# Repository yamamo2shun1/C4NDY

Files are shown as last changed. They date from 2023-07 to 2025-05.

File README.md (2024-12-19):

# C4NDY KeyVLM / STK

## Documentation
- [See the official documentation on https://yamamo2shun1.github.io/C4NDY/](https://yamamo2shun1.github.io/C4NDY/)

The docs are powered by [VitePress](https://vitepress.dev/). 

## Submodule
[TinyUSB](https://github.com/hathach/tinyusb) is included as a submodule in [STM32CubeIDE/C4NDY_KeyVLM](https://github.com/yamamo2shun1/C4NDY/tree/main/STM32CubeIDE/C4NDY_KeyVLM) and [STM32CubeIDE/C4NDY_STK](https://github.com/yamamo2shun1/C4NDY/tree/main/STM32CubeIDE/C4NDY_STK). Since the version of TinyUSB that we have confirmed to work is [0.17.0](https://github.com/hathach/tinyusb/releases/tag/0.17.0), please check out to the [commit](https://github.com/hathach/tinyusb/commit/5217cee5de4cd555018da90f9f1bcc87fb1c1d3a) with this tag.

## Maintainer
C4NDY is developed and maintained by Shunichi Yamamoto of Yamamoto Works Ltd.

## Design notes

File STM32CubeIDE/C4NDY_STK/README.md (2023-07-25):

# C4NDY Composite HID & UAC

サブモジュール化したTinyUSBそのままではPC接続時にUSBデバイスとして正しく認識しないので、以下の変更を行う。

## dcd_stm32_fsdev.c (src/portable/st/stm32_fsdev)
dcd_init_enable関数内にある割り込みを有効化する処理を2箇所、コメントアウトする。

```
#elif CFG_TUSB_MCU == OPT_MCU_STM32G4
  //NVIC_EnableIRQ(USB_HP_IRQn); <-- コメントアウト
  NVIC_EnableIRQ(USB_LP_IRQn);
  //NVIC_EnableIRQ(USBWakeUp_IRQn); <-- コメントアウト
```

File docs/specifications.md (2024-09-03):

# Specifications

## Common

- Mainboard:
  - MCU: [STM32G491](https://www.st.com/en/microcontrollers-microprocessors/stm32g4x1.html)
  - USB Stack: [TinyUSB](https://docs.tinyusb.org/en/latest/)
  - Debug Interface: SWD
  - [Schematics](/pdf/main-sch.pdf)
  - [PCB](/pdf/main-brd.pdf)
- Codec: [Analog Devices ADAU1761](https://www.analog.com/jp/products/adau1761.html)
  - USB Audio Spec: 24bit 48kHz Input only
  - Analog Audio In/Out: Line/Phono In and HP Out, [Thonkiconn 3.5mm jack socket](https://www.thonk.co.uk/shop/thonkiconn/))
- Keyswitch: Gateron Low Profile 2.0(Implemented Hotswap socket KS-27)  

## KeyVLM 

- 65x Keys, 2x Pots(mix and main output gain), 9x GPIO Ports
- [Schematics](/pdf/KeyVLM-sch.pdf)
- [PCB](/pdf/KeyVLM-brd.pdf)

## STK

- 37x Keys, 34x RGB LEDs, 2x Analog JoySticks, 1x Pot(mix), 6x GPIO Ports
- [Schematics](/pdf/STK-sch.pdf)
- [PCB](/pdf/STK-brd.pdf)

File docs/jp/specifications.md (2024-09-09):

# 主な仕様

## 共通

- メインボード:
  - MCU: [STM32G491](https://www.st.com/en/microcontrollers-microprocessors/stm32g4x1.html)
  - USBスタック: [TinyUSB](https://docs.tinyusb.org/en/latest/)
  - デバッグ・インターフェース: SWD
  - [Schematics](/pdf/main-sch.pdf)
  - [PCB](/pdf/main-brd.pdf)
- オーディオ・コーデック: [Analog Devices ADAU1761](https://www.analog.com/jp/products/adau1761.html)
  - USBオーディオ: 24bit 48kHz （入力のみ、フォノ/ラインの音声をホスト側に送ることは出来ません）
  - アナログ・オーディオ入出力: フォノ/ライン入力、 HP出力, [Thonkiconn 3.5mm jack socket](https://www.thonk.co.uk/shop/thonkiconn/))
- キースイッチ: Gateron Low Profile 2.0(Implemented Hotswap socket KS-27)  

## KeyVLM 

- 65個のキー、2個のボリューム(ミックスと出力ゲイン調整用), 9個のGPIOポート
- [Schematics](/pdf/KeyVLM-sch.pdf)
- [PCB](/pdf/KeyVLM-brd.pdf)

## STK

- 37個のキー、34個のフルカラーLED、2本のジョイスティック、1個のボリューム(ミックス調整用), 6個のGPIOポート
- [Schematics](/pdf/STK-sch.pdf)
- [PCB](/pdf/STK-brd.pdf)

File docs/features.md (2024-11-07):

# What is C4NDY KeyVLM/STK?

The C4NDY KeyVLM/STK is a USB keyboard with a Ortholinear layout. It's greatest feature is that it can be connected to a turntable, allowing you to mix the music you are playing on your computer or smartphone(USB host device) with the music on your vinyl records.

Furthermore, C4NDY KeyVLM/STK is open source hardware under the [MIT license](https://github.com/yamamo2shun1/C4NDY/blob/main/LICENSE.md). The [source codes](https://github.com/yamamo2shun1/C4NDY/tree/main/STM32CubeIDE) of the firmware as well as the [circuit board schematics](https://github.com/yamamo2shun1/C4NDY/tree/main/KiCad) and [3D model data](https://github.com/yamamo2shun1/C4NDY/tree/main/3Dmodel) of the enclosure are available to the public.

## KeyVLM

KeyVLM is designed to be stress-free for first-time users of Ortholinear Layout by setting the number of keys to 65.

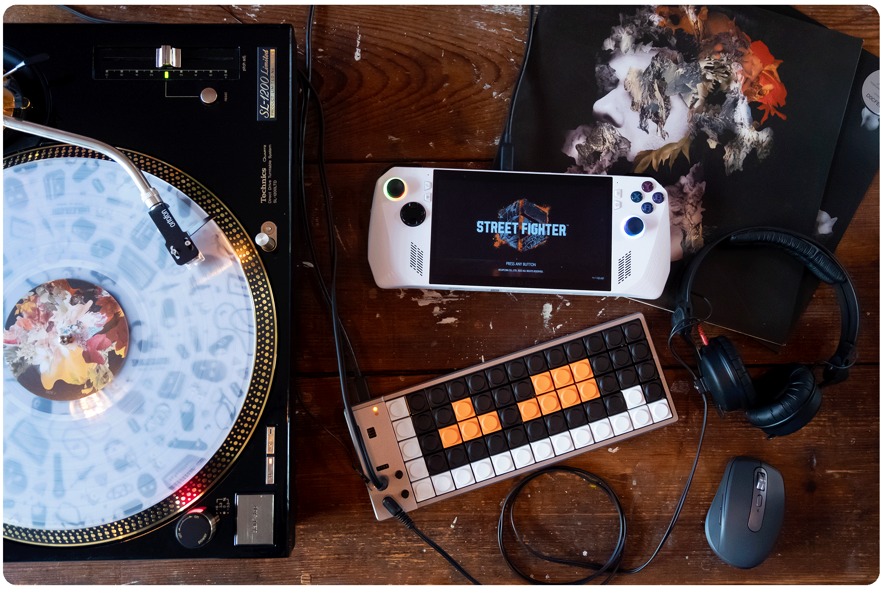
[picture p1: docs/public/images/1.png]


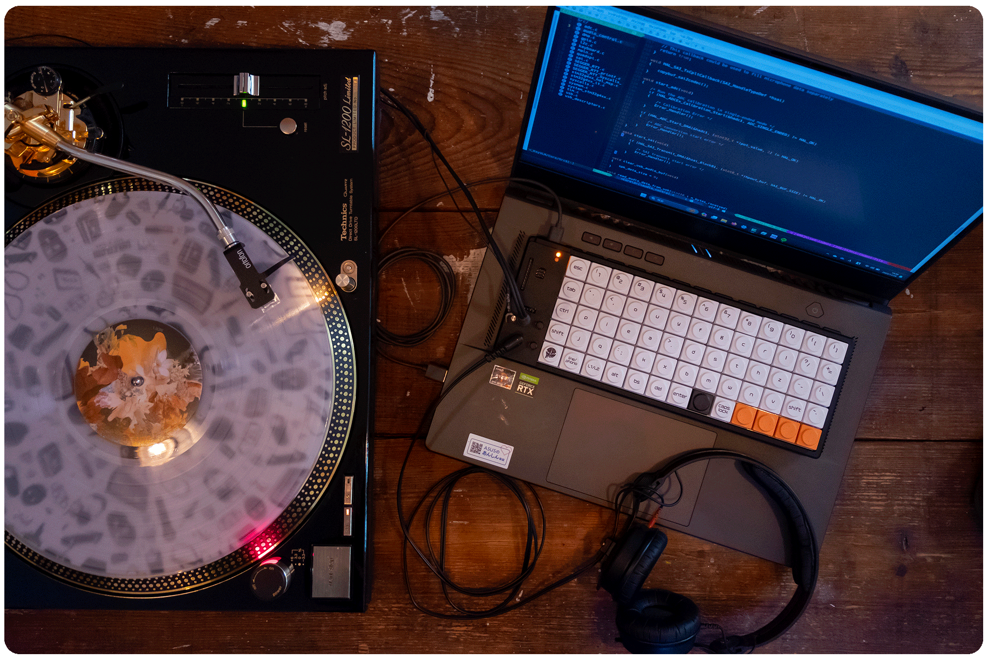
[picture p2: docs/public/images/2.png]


## STK

STK is a minimalist keyboard with 37 keys, but with 2 joysticks designed to reduce pinky finger fatigue and maximize thumb's performance.

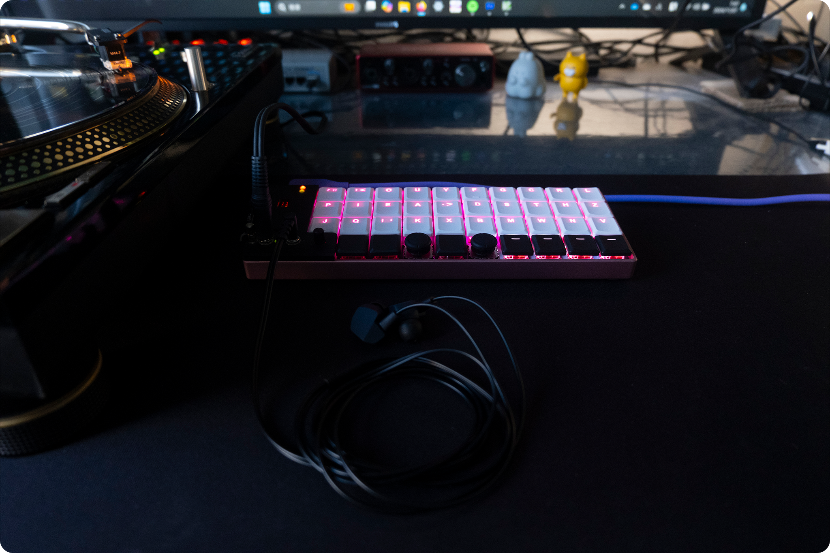
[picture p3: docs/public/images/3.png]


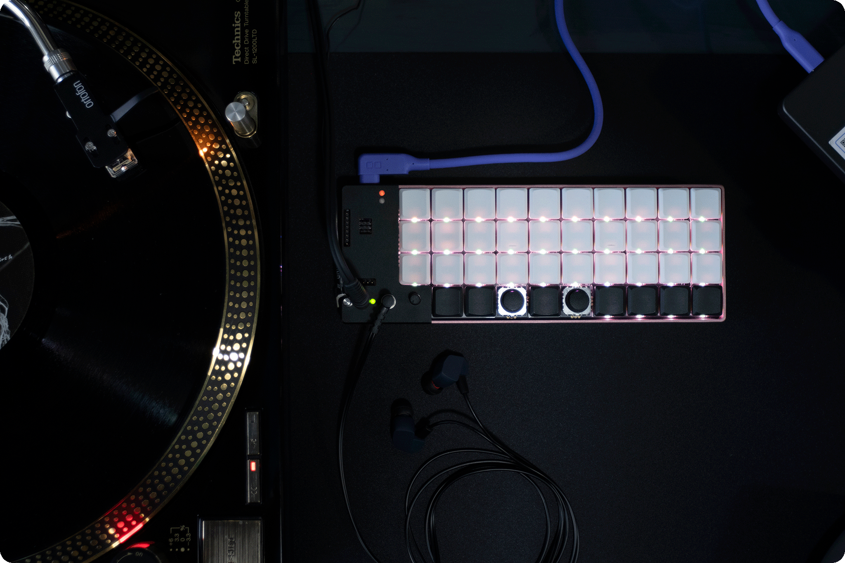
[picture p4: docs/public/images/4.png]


<iframe class="youtube" src="https://www.youtube.com/embed/TXuELYQbFvI?si=C4ZM-QYwuqbofEQ4" title="YouTube video player" frameborder="0" allow="accelerometer; autoplay; clipboard-write; encrypted-media; gyroscope; picture-in-picture; web-share" referrerpolicy="strict-origin-when-cross-origin" allowfullscreen></iframe>
<br>
<iframe class="youtube" src="https://www.youtube.com/embed/GJj3aiSIqJE?si=5twpRAXy-AmaJDOT" title="YouTube video player" frameborder="0" allow="accelerometer; autoplay; clipboard-write; encrypted-media; gyroscope; picture-in-picture; web-share" referrerpolicy="strict-origin-when-cross-origin" allowfullscreen></iframe>
<br>
<iframe class="youtube" src="https://www.youtube.com/embed/NtcGqJvtMxw?si=YaaeqbSABE9DcXNv" title="YouTube video player" frameborder="0" allow="accelerometer; autoplay; clipboard-write; encrypted-media; gyroscope; picture-in-picture; web-share" referrerpolicy="strict-origin-when-cross-origin" allowfullscreen></iframe>
<br>
<iframe class="youtube" src="https://www.youtube.com/embed/8FVFd6uG3Ts?si=2ghEefk_HB_o5fTh" title="YouTube video player" frameborder="0" allow="accelerometer; autoplay; clipboard-write; encrypted-media; gyroscope; picture-in-picture; web-share" referrerpolicy="strict-origin-when-cross-origin" allowfullscreen></iframe>

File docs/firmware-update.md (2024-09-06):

# Firmware Update
## Introduction
The C4NDY KeyVLM/STK does not require a firmware rewrite to change the keymap.
Normal users will only update the firmware when bug fixes or new features are added.
C4NDY KeyVLM/STK has a built-in boot loader for this purpose.

## How to switch to boot loader mode
Press and hold down the LGUI and ESC keys or RESET key until the green LED on the Side-Panel blinks three times to enter the boot loader mode.

<video controls="controls" src="https://github.com/yamamo2shun1/C4NDY/assets/96638/79a93170-637f-4472-83ec-ebd615135d6c" />

## Installing the driver
If you are using Windows, you will need to install the driver on [Zadig](https://zadig.akeo.ie/) after entering the boot loader mode (first time only).

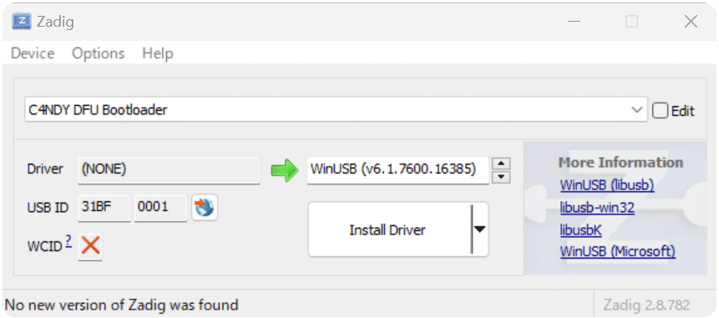
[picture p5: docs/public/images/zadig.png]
zadig


## Installing the programmer
To update the firmware, it is recommended to install and use [STM32CubeProg](https://www.st.com/ja/development-tools/stm32cubeprog.html).
The procedure to update the firmware using STM32CubeProg is as follows

0. Download the latest ELF file from [here](https://github.com/yamamo2shun1/C4NDY/releases).
1. launch STM32CubeProg.
2. Rewrite "PID" to "0x0001".
3. Rewrite "VID" to "0x31BF".
4. Click the "Port" update button.
5. Confirm that "Port" is changed from "No DFU detected" to "USB1" and click the "Connect" button.
6. Click the "Erasing & Programming" button, the second green button from the top on the left side of the window.
7. Check the "Verify programming" and "Run after programming" check boxes.
8. Confirm that "Full chip erase" is not checked.
9. Set the path of downloaded .elf file in "File path".
10. Click "Start Programming" to start programming.

<video controls="controls" src="https://github.com/yamamo2shun1/C4NDY/assets/96638/fc8503f9-ba2c-4c98-849b-17fdc625cbd1" />

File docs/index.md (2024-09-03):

---
# https://vitepress.dev/reference/default-theme-home-page
layout: home

hero:
  name: "C4NDY KeyVLM / STK"
  text: "Ortholinear Keyboard connectable a Turntable."
  tagline: The UAC and HID composite device project based on STM32G491.
  image:
    dark: /images/c4ndy-dark.png
    light: /images/c4ndy-light.png
    alt: logo
  actions:
    - theme: brand
      text: Get Started
      link: /features
    - theme: alt
      text: View on GitHub
      link: https://github.com/yamamo2shun1/C4NDY 

features:
  - icon:
      src: /images/keyvlm.png
      width: 560px
    title: C4NDY KeyVLM
    details: 65-Key Ortholinear Layout and Audio I/O(Phono/Line in & HP out).
    link: https://booth.pm/ja/items/5785829
    linkText: buy (Japanese)
    rel: external
  - icon:
      src: /images/stk.png
      width: 560px
    title: C4NDY STK
    details: 37-Key Ortholinear Layout, 34-RGB LEDs, 2-JoySticks and Audio I/O(Phono/Line in & HP out).
#  - title: Feature C
#    details: Lorem ipsum dolor sit amet, consectetur adipiscing elit
---

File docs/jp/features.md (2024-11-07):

# C4NDY KeyVLM/STK とは？

C4NDY KeyVLM/STKは格子配列のUSBキーボードです。最大の特徴はターンテーブルが接続することが可能で、PCやスマホなど（USBホストデバイス）の音楽とヴァイナルの音楽をミックスして楽しく事ができます。

さらに、C4NDY KeyVLM/STK は[MITライセンス](https://github.com/yamamo2shun1/C4NDY/blob/main/LICENSE.md)に基づくオープンソース・ハードウェアです。ファームウェアの[ソースコード](https://github.com/yamamo2shun1/C4NDY/tree/main/STM32CubeIDE)、[基板の回路図、ボードデータ](https://github.com/yamamo2shun1/C4NDY/tree/main/KiCad) 、そして筐体の[3Dデータ](https://github.com/yamamo2shun1/C4NDY/tree/main/3Dmodel)も再利用可能です。

## KeyVLM

KeyVLMは初めての格子配列キーボードでもストレスなく使えるようキーの数を65キーで設計されています。





## STK

STKは37キーのミニマルなキーボードです。小指の負荷を軽減し、親指の運動性能を最大限活用するため2本のジョイスティックが実装されています。





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

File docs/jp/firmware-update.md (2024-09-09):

# ファームウェアの更新
## はじめに
C4NDY KeyVLM/STKはキーマップの変更でファームウェアを書き換える必要がありません。通常のユーザーはバグ修正や新機能が追加されるときに必要に応じてファームエアを更新します。

## ブートローダーモードへの移行
C4NDY KeyVLM/STKはファームウェア書き換え用のライターを使わずにファームウェアの更新を置くなうためにブートローダーが内蔵さえています。
ブートローダーモードに移行するには、サイドパネルの緑LEDが3回点滅するまでLGUIとESCキーの2つ（もしくはRESETキー単独）を長押しします。

<video controls="controls" src="https://github.com/yamamo2shun1/C4NDY/assets/96638/79a93170-637f-4472-83ec-ebd615135d6c" />

## ドライバのインストール
Windowsユーザーの場合、ブートローダーモードに初めて切り替えた時のみ、[Zadig](https://zadig.akeo.ie/)でドライバーをインストールする必要があります。

zadig

## プログラマのインストール
ファームウェアの更新をするためには、STMicroelectronics社がリリースしている[STM32CubeProg](https://www.st.com/ja/development-tools/stm32cubeprog.html)をインストールしてお使いいただくことを推奨しています。
STM32CubeProgを使ってファームウェアを更新する手順は下記の通りです。

0. 最新のELFファイルを[ここ](https://github.com/yamamo2shun1/C4NDY/releases)からダウンロードします
1. STM32CubeProgを起動します
2. 「PID」に「0x0001」と入力します
3. 「VID」に「0x31BF」と入力します
4. 「Port」の更新ボタンをクリックします
5. 「Port」が「No DFU detected」から「USB1」になったことを確認し、「Connect」ボタンをクリックします
6. ウィンドウ左端に並んでいる緑色アイコンの上から2つ目にある「Erasing & Programming」ボタンをクリックします
7. 「Verify programming」と「Run after programming」のチェックボックスにチェックを入れます
8. 「Full chip erase」にチェックが入っていないことを確認します
9．「File path」にダウンロードした.elfファイルをセットします
10. 「Start Programming」をクリックし、9でセットした.elfを書き込みます

<video controls="controls" src="https://github.com/yamamo2shun1/C4NDY/assets/96638/fc8503f9-ba2c-4c98-849b-17fdc625cbd1" />

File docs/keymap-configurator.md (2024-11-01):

# How to remap

[Confiseur](https://github.com/yamamo2shun1/Confiseur) is a command line tool for key remapping dedicated to C4NDY KeyVLM/STK.

## Preparing
By preparing a keymap file written in TOML and reading it, it is possible to remap without rewriting the firmware.

- [Example for KeyVLM](https://github.com/yamamo2shun1/Confiseur/blob/main/example-layout/layouts_KeyVLM.toml)
```toml
[layout1]
	normal = [
		[["Esc", "00000000"],  ["1", "00000000"],    ["2", "00000000"],      ["3", "00000000"],    ["4", "00000000"],  ["5", "00000000"],   ["6", "00000000"],     ["7", "00000000"],     ["8", "00000000"],        ["9", "00000000"],      ["0", "00000000"],     ["Minus", "00000000"],      ["Equal", "00000000"]],
		[["Tab", "00000000"],  ["Q", "00000000"],    ["W", "00000000"],      ["E", "00000000"],    ["R", "00000000"],  ["T", "00000000"],   ["Y", "00000000"],     ["U", "00000000"],     ["V", "00000000"],        ["O", "00000000"],      ["P", "00000000"],     ["O_SBracket", "00000000"], ["C_SBracket", "00000000"]],
		[["Null", "00000001"], ["A", "00000000"],    ["S", "00000000"],      ["D", "00000000"],    ["F", "00000000"],  ["G", "00000000"],   ["H", "00000000"],     ["J", "00000000"],     ["K", "00000000"],        ["L", "00000000"],      ["Colon", "00000000"], ["Apostrophe", "00000000"], ["Yen", "00000000"]],
		[["Null", "00000010"], ["Z", "00000000"],    ["X", "00000000"],      ["C", "00000000"],    ["I", "00000000"],  ["B", "00000000"],   ["N", "00000000"],     ["M", "00000000"],     ["Comma", "00000000"],    ["Period", "00000000"], ["Slash", "00000000"], ["Null", "00100000"],       ["Backquote", "00000000"]],
		[["Null", "00001000"], ["LNPH", "00000000"], ["LAYOUT", "00000000"], ["Null", "00000100"], ["BS", "00000000"], ["Del", "00000000"], ["Enter", "00000000"], ["Space", "00000000"], ["CapsLock", "00000000"], ["Left", "00000000"],   ["Down", "00000000"],  ["Up", "00000000"],         ["Right", "00000000"]]

	]

[layout2]
	normal = [
		[["Esc", "00000000"],  ["1", "00000000"],          ["2", "00000000"],      ["3", "00000000"],     ["4", "00000000"],  ["5", "00000000"],      ["6", "00000000"],     ["7", "00000000"],     ["8", "00000000"],        ["9", "00000000"],    ["0", "00000000"],    ["O_SBracket", "00000000"], ["C_SBracket", "00000000"]],
		[["Tab", "00000000"],  ["Apostrophe", "00000000"], ["Comma", "00000000"],  ["O", "00000000"],     ["U", "00000000"],  ["Y", "00000000"],      ["F", "00000000"],     ["G", "00000000"],     ["C", "00000000"],        ["R", "00000000"],    ["L", "00000000"],    ["Slash", "00000000"],      ["Equal", "00000000"]],
		[["Null", "00000001"], ["P", "00000000"],          ["I", "00000000"],      ["E", "00000000"],     ["A", "00000000"],  ["Period", "00000000"], ["D", "00000000"],     ["S", "00000000"],     ["T", "00000000"],        ["H", "00000000"],    ["Z", "00000000"],    ["Minus", "00000000"],      ["Backslash", "00000000"]],
		[["Null", "00000010"], ["J", "00000000"],          ["Q", "00000000"],      ["Colon", "00000000"], ["K", "00000000"],  ["X", "00000000"],      ["B", "00000000"],     ["M", "00000000"],     ["W", "00000000"],        ["N", "00000000"],    ["V", "00000000"],    ["Null", "00100000"],       ["Backquote", "00000000"]],
		[["Null", "00001000"], ["LNPH", "00000000"],       ["LAYOUT", "00000000"], ["Null", "00000100"],  ["BS", "00000000"], ["Del", "00000000"],    ["Enter", "00000000"], ["Space", "00000000"], ["CapsLock", "00000000"], ["Left", "00000000"], ["Down", "00000000"], ["Up", "00000000"],         ["Right", "00000000"]]
	]
```

- [Example for STK](https://github.com/yamamo2shun1/Confiseur/blob/main/example-layout/layouts_STK.toml)
```toml
[layout1]
	normal = [
		[["Q", "00000000"],    ["W", "00000000"],    ["E", "00000000"],    ["R", "00000000"],    ["T", "00000000"],    ["Y", "00000000"],    ["U", "00000000"],    ["I", "00000000"],     ["O", "00000000"],      ["P", "00000000"]],
		[["A", "00000000"],    ["S", "00000000"],    ["D", "00000000"],    ["F", "00000000"],    ["G", "00000000"],    ["H", "00000000"],    ["J", "00000000"],    ["K", "00000000"],     ["L", "00000000"],      ["Colon", "00000000"]],
		[["Z", "00000000"],    ["X", "00000000"],    ["C", "00000000"],    ["V", "00000000"],    ["B", "00000000"],    ["N", "00000000"],    ["M", "00000000"],    ["Comma", "00000000"], ["Period", "00000000"], ["Slash", "00000000"]],
		[["Null", "00000000"], ["Null", "00001000"], ["Null", "00000100"], ["Null", "00000000"], ["Null", "00000001"], ["Null", "00000000"], ["Left", "00000000"], ["Down", "00000000"],  ["Up", "00000000"],     ["Right", "00000000"]]
	]
	upper = [
		[["1", "00000000"],          ["2", "00000000"],         ["3", "00000000"],      ["4", "00000000"],      ["5", "00000000"],       ["6", "00000000"],    ["7", "00000000"],          ["8", "00000000"],          ["9", "00000000"],        ["0", "00000000"]],
		[["Apostrophe", "00000000"], ["Backquote", "00000000"], ["Null", "00000000"],   ["Null", "00001000"],   ["Null", "00000000"],    ["Null", "00000000"], ["O_SBracket", "00000000"], ["C_SBracket", "00000000"], ["Minus", "00000000"],    ["Equal", "00000000"]],
		[["Null", "00000000"],       ["CapsLock", "00000000"],  ["M_LBTN", "00000000"], ["M_RBTN", "00000000"], ["M_WHEEL", "00000000"], ["Null", "00000000"], ["Null", "00000000"],       ["Comma", "00000000"],      ["Period", "00000000"],   ["Backslash", "00000000"]],
		[["Null", "00000000"],       ["LNPH", "00000000"],      ["LAYOUT", "00000000"], ["Null", "00000000"],   ["Null", "00000001"],    ["Null", "00000000"], ["Null", "00000000"],       ["MGain_Down", "00000000"], ["MGain_Up", "00000000"], ["Reset", "00000000"]]
	]
	stick = [
		[
			["Null", "00000000"], ["Upper", "00000000"], ["Null", "00000000"],
			["BS",   "00000000"], ["Null",  "00000000"], ["Tab",  "00000000"],
			["Null", "00000000"], ["Enter", "00000000"], ["Null", "00000000"]
		],
		[
			["Null", "00000000"], ["Null", "00100000"], ["Null",  "00000000"],
			["Del",  "00000000"], ["Null", "00000000"], ["Space", "00000000"],
			["Null", "00000000"], ["Esc",  "00000000"], ["Null",  "00000000"]
		]
	]
	led = [
		[0x00, 0xAE, 0xEF],
		[0xEF, 0x00, 0xAE],
		[0xAE, 0xEF, 0x00]
	]
    intensity = [
        1.0
    ]

[layout2]
	normal = [
		[["Apostrophe", "00000000"], ["Comma", "00000000"], ["O", "00000000"],     ["U", "00000000"],    ["Y", "00000000"],      ["F", "00000000"],    ["G", "00000000"],    ["C", "00000000"],    ["R", "00000000"],  ["L", "00000000"]],
		[["P", "00000000"],          ["I", "00000000"],     ["E", "00000000"],     ["A", "00000000"],    ["Period", "00000000"], ["D", "00000000"],    ["S", "00000000"],    ["T", "00000000"],    ["H", "00000000"],  ["Z", "00000000"]],
		[["J", "00000000"],          ["Q", "00000000"],     ["Colon", "00000000"], ["K", "00000000"],    ["X", "00000000"],      ["B", "00000000"],    ["M", "00000000"],    ["W", "00000000"],    ["N", "00000000"],  ["V", "00000000"]],
		[["Null", "00000000"],       ["Null", "00001000"],  ["Null", "00000100"],  ["Null", "00000000"], ["Null", "00000001"],   ["Null", "00000000"], ["Left", "00000000"], ["Down", "00000000"], ["Up", "00000000"], ["Right", "00000000"]]
	]
	upper = [
		[["1", "00000000"],          ["2", "00000000"],        ["3", "00000000"],      ["4", "00000000"],      ["5", "00000000"],       ["6", "00000000"],    ["7", "00000000"],          ["8", "00000000"],          ["9", "00000000"],         ["0", "00000000"]],
		[["Apostrophe", "00000000"], ["Comma", "00000000"],    ["Null", "00000000"],   ["Null", "00001000"],   ["Period", "00000000"],  ["Null", "00000000"], ["O_SBracket", "00000000"], ["C_SBracket", "00000000"], ["Slash", "00000000"],     ["Minus", "00000000"]],
		[["Null", "00000000"],       ["CapsLock", "00000000"], ["M_LBTN", "00000000"], ["M_RBTN", "00000000"], ["M_WHEEL", "00000000"], ["Null", "00000000"], ["Equal", "00000000"],      ["Null", "00000000"],       ["Backquote", "00000000"], ["Backslash", "00000000"]],
		[["Null", "00000000"],       ["LNPH", "00000000"],     ["LAYOUT", "00000000"], ["Null", "00000000"],   ["Null", "00000001"],    ["Null", "00000000"], ["Null", "00000000"],       ["MGain_Down", "00000000"], ["MGain_Up", "00000000"],  ["Reset", "00000000"]]
	]
	stick = [
		[
			["Null", "00000000"], ["Upper", "00000000"], ["Null", "00000000"],
			["BS",   "00000000"], ["Null",  "00000000"], ["Tab",  "00000000"],
			["Null", "00000000"], ["Enter", "00000000"], ["Null", "00000000"]
		],
		[
			["Null", "00000000"], ["Null", "00100000"], ["Null",  "00000000"],
			["Del",  "00000000"], ["Null", "00000000"], ["Space", "00000000"],
			["Null", "00000000"], ["Esc",  "00000000"], ["Null",  "00000000"]
		]
	]
	led = [
		[0xFF, 0x00, 0x8C],
		[0x00, 0xFF, 0xFF],
		[0x00, 0x00, 0xFF]
	]
    intensity = [
        1.0
    ]
```

## Installation
The `go install` is available.
```shellscript
$ go install github.com/yamamo2shun1/Confiseur/cmd/confiseur@v0.14.0
```

## Usage

```Less
-version
        Show the version of the tool installed.
        ex) confiseur -version
-check
        Show information on C4NDY KeyVLM/STK connected to PC/Mac.
        ex) confiseur -check
-list
        Show connected device name list.
        ex) confiseur -list
-id [int]
        Select connected device ID(ID can be checked in -check/-list).
        This option is available when using the following command options.
        If ID is not specified, 0 is the default.
-load
        Show the current key names of the keyboard.
        ex) confiseur -load
            confiseur -load -id 1
-remap [string]
        Apply the keyboard settings from specified toml file.
        ex) confiseur -remap examples/layout_STK.toml
            confiseur -remap examples/layout_KeyVLM.toml -id 0
-save
        Save the keymap written by "remap" to the memory area.
        ex) confiseur -save
            confiseur -id 0 -save
-led [int(0x000000-0xFFFFFF)]
        Set LED RGB value for checking color.
        ex) confiseur -led 0xFF0000 # red
            confiseur id 0 -led 0x00FFFF # cyan
-intensity [float(0.0-1.0)]
        Set LED intensity.
        ex) confiseur -intensity 1.0
            confiseur -id 1 -intensity 0.5
-restart
        Restart the keyboard immediately.
        ex) confiseur -restart
            confiseur -restart -id 1
-factoryreset
        Reset all settings to factory defaults.
        ex) confiseur -factoryreset
            confiseur -id 0 -factoryreset
```

## Preparation to build
First, install the [Go language](https://go.dev/) development environment.  
Some preparation is required to build the code because we are using [go-hid](https://github.com/sstallion/go-hid).

### for Windows
Add `CGO_ENABLED=1` to the environment variable and install a C compiler such as [TDM-GCC](https://jmeubank.github.io/tdm-gcc/) beforehand.

### for macOS/Linux
Add `CGO_ENABLED=1` to your shell configuration file, such as .zshrc.

## How to build from Source Code
```shellscript
$ git clone https://github.com/yamamo2shun1/Confiseur
$ cd Confiseur/cmd/confiseur
$ go build -o confiseur
```

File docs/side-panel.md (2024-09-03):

# Side Panel I/O

## KeyVLM
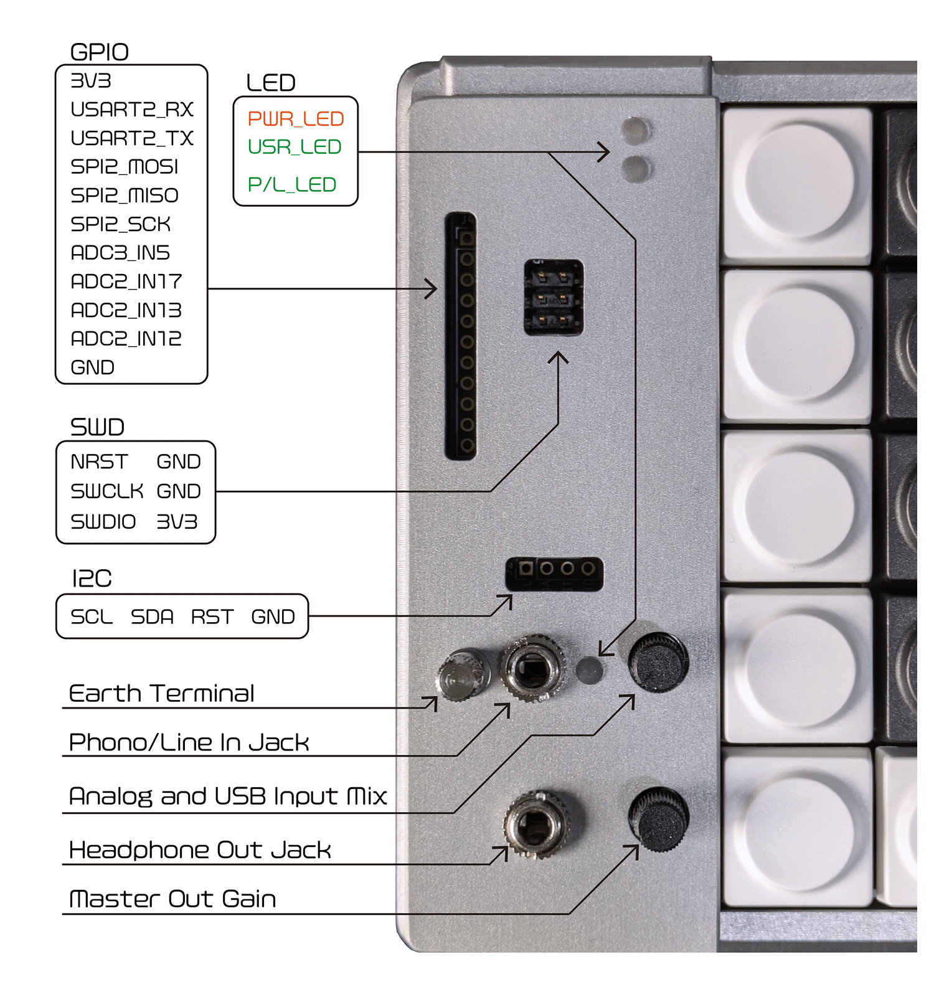
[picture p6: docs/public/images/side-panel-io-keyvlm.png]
side-panel-io-keyvlm


## STK
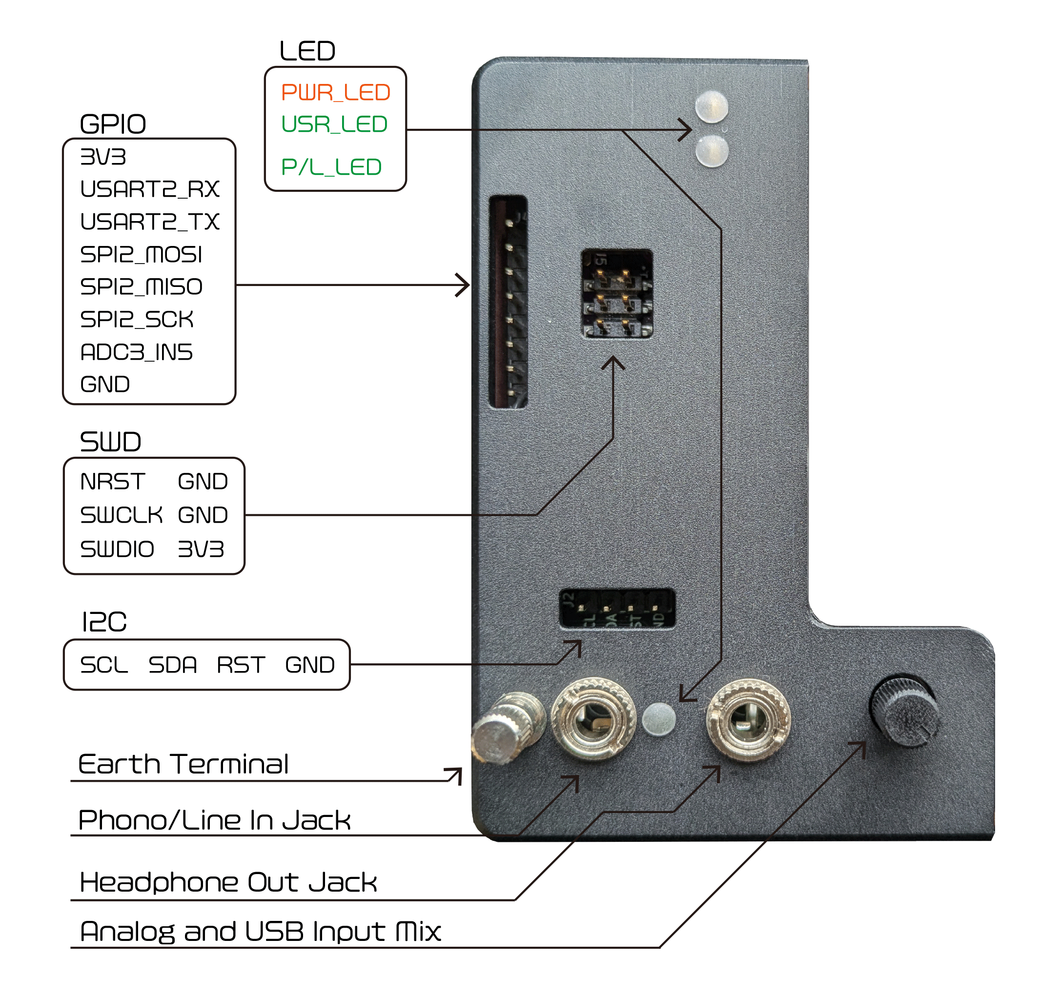
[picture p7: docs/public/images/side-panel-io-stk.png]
side-panel-io-stk


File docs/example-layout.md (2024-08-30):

# Example Layout
## KeyVLM
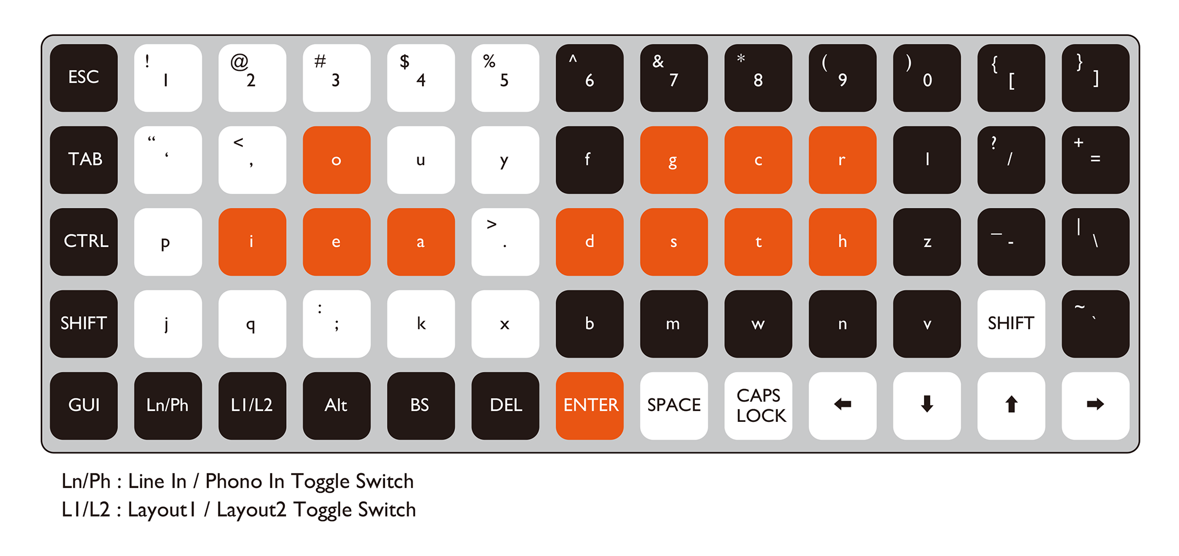
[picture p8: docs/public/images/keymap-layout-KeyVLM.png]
layout-keyvlm


## STK
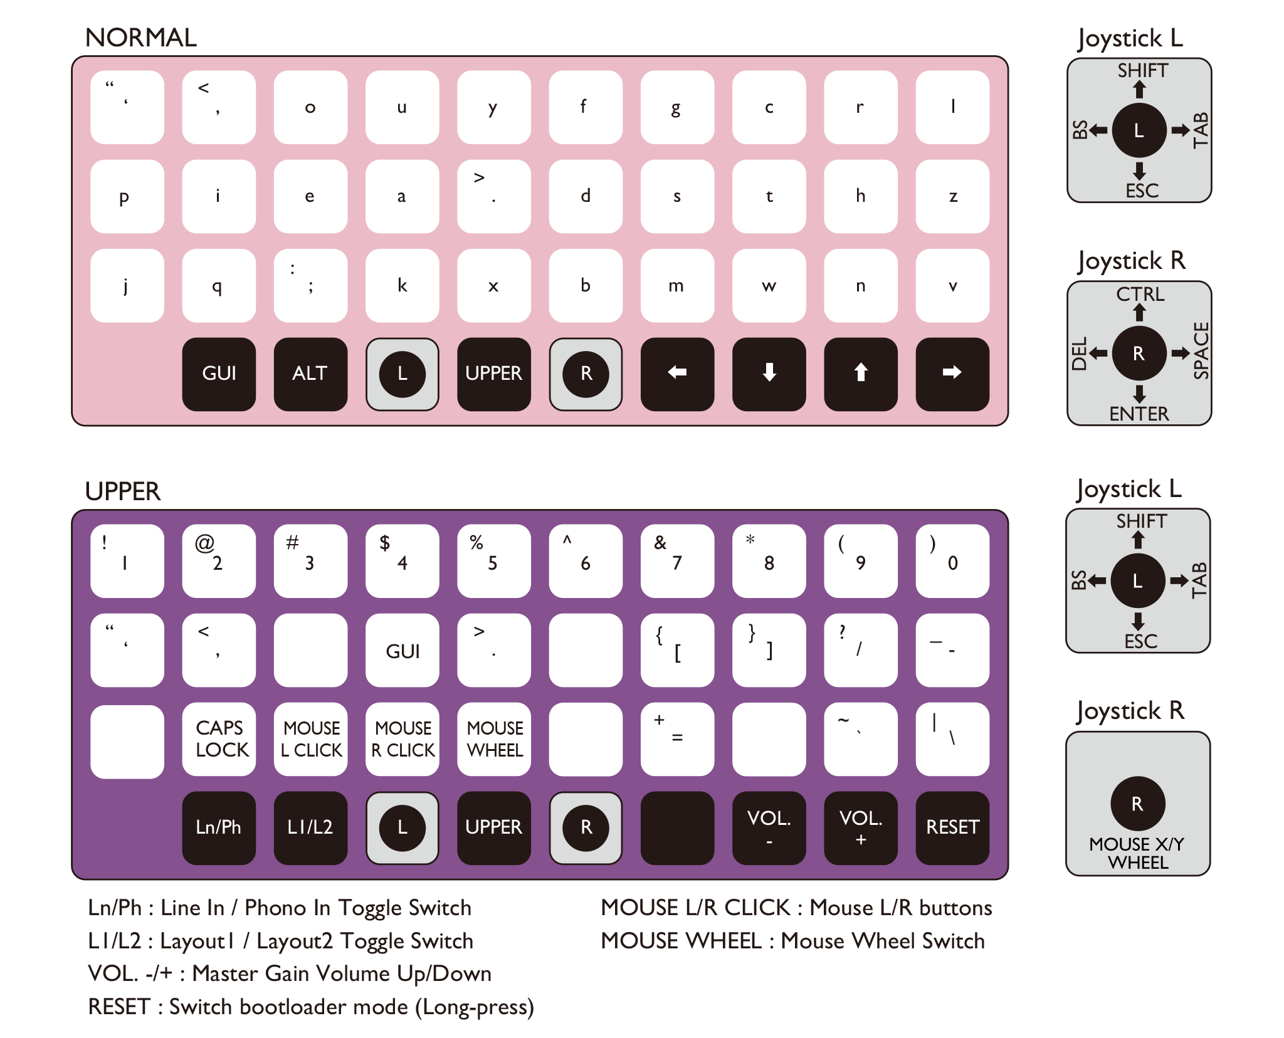
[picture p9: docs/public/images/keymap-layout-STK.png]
layout-stk


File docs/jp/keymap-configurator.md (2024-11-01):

# キーボードのリマップ

C4NDY KeyVLM/STKのキーをリマップするには、専用のコマンドライン・ツール[Confiseur](https://github.com/yamamo2shun1/Confiseur)を使います。

## 準備
キーマップを記述したTOMLを用意することで、ファームウェアの書き換え無しにリマップすることが可能です。

- [例：KeyVLM](https://github.com/yamamo2shun1/Confiseur/blob/main/example-layout/layouts_KeyVLM.toml)

```toml
[layout1]
	normal = [
		[["Esc", "00000000"],  ["1", "00000000"],    ["2", "00000000"],      ["3", "00000000"],    ["4", "00000000"],  ["5", "00000000"],   ["6", "00000000"],     ["7", "00000000"],     ["8", "00000000"],        ["9", "00000000"],      ["0", "00000000"],     ["Minus", "00000000"],      ["Equal", "00000000"]],
		[["Tab", "00000000"],  ["Q", "00000000"],    ["W", "00000000"],      ["E", "00000000"],    ["R", "00000000"],  ["T", "00000000"],   ["Y", "00000000"],     ["U", "00000000"],     ["V", "00000000"],        ["O", "00000000"],      ["P", "00000000"],     ["O_SBracket", "00000000"], ["C_SBracket", "00000000"]],
		[["Null", "00000001"], ["A", "00000000"],    ["S", "00000000"],      ["D", "00000000"],    ["F", "00000000"],  ["G", "00000000"],   ["H", "00000000"],     ["J", "00000000"],     ["K", "00000000"],        ["L", "00000000"],      ["Colon", "00000000"], ["Apostrophe", "00000000"], ["Yen", "00000000"]],
		[["Null", "00000010"], ["Z", "00000000"],    ["X", "00000000"],      ["C", "00000000"],    ["I", "00000000"],  ["B", "00000000"],   ["N", "00000000"],     ["M", "00000000"],     ["Comma", "00000000"],    ["Period", "00000000"], ["Slash", "00000000"], ["Null", "00100000"],       ["Backquote", "00000000"]],
		[["Null", "00001000"], ["LNPH", "00000000"], ["LAYOUT", "00000000"], ["Null", "00000100"], ["BS", "00000000"], ["Del", "00000000"], ["Enter", "00000000"], ["Space", "00000000"], ["CapsLock", "00000000"], ["Left", "00000000"],   ["Down", "00000000"],  ["Up", "00000000"],         ["Right", "00000000"]]
	]

[layout2]
	normal = [
		[["Esc", "00000000"],  ["1", "00000000"],          ["2", "00000000"],      ["3", "00000000"],     ["4", "00000000"],  ["5", "00000000"],      ["6", "00000000"],     ["7", "00000000"],     ["8", "00000000"],        ["9", "00000000"],    ["0", "00000000"],    ["O_SBracket", "00000000"], ["C_SBracket", "00000000"]],
		[["Tab", "00000000"],  ["Apostrophe", "00000000"], ["Comma", "00000000"],  ["O", "00000000"],     ["U", "00000000"],  ["Y", "00000000"],      ["F", "00000000"],     ["G", "00000000"],     ["C", "00000000"],        ["R", "00000000"],    ["L", "00000000"],    ["Slash", "00000000"],      ["Equal", "00000000"]],
		[["Null", "00000001"], ["P", "00000000"],          ["I", "00000000"],      ["E", "00000000"],     ["A", "00000000"],  ["Period", "00000000"], ["D", "00000000"],     ["S", "00000000"],     ["T", "00000000"],        ["H", "00000000"],    ["Z", "00000000"],    ["Minus", "00000000"],      ["Backslash", "00000000"]],
		[["Null", "00000010"], ["J", "00000000"],          ["Q", "00000000"],      ["Colon", "00000000"], ["K", "00000000"],  ["X", "00000000"],      ["B", "00000000"],     ["M", "00000000"],     ["W", "00000000"],        ["N", "00000000"],    ["V", "00000000"],    ["Null", "00100000"],       ["Backquote", "00000000"]],
		[["Null", "00001000"], ["LNPH", "00000000"],       ["LAYOUT", "00000000"], ["Null", "00000100"],  ["BS", "00000000"], ["Del", "00000000"],    ["Enter", "00000000"], ["Space", "00000000"], ["CapsLock", "00000000"], ["Left", "00000000"], ["Down", "00000000"], ["Up", "00000000"],         ["Right", "00000000"]]
	]
```

- [例：STK](https://github.com/yamamo2shun1/Confiseur/blob/main/example-layout/layouts_STK.toml)
```toml
[layout1]
	normal = [
		[["Q", "00000000"],    ["W", "00000000"],    ["E", "00000000"],    ["R", "00000000"],    ["T", "00000000"],    ["Y", "00000000"],    ["U", "00000000"],    ["I", "00000000"],     ["O", "00000000"],      ["P", "00000000"]],
		[["A", "00000000"],    ["S", "00000000"],    ["D", "00000000"],    ["F", "00000000"],    ["G", "00000000"],    ["H", "00000000"],    ["J", "00000000"],    ["K", "00000000"],     ["L", "00000000"],      ["Colon", "00000000"]],
		[["Z", "00000000"],    ["X", "00000000"],    ["C", "00000000"],    ["V", "00000000"],    ["B", "00000000"],    ["N", "00000000"],    ["M", "00000000"],    ["Comma", "00000000"], ["Period", "00000000"], ["Slash", "00000000"]],
		[["Null", "00000000"], ["Null", "00001000"], ["Null", "00000100"], ["Null", "00000000"], ["Null", "00000001"], ["Null", "00000000"], ["Left", "00000000"], ["Down", "00000000"],  ["Up", "00000000"],     ["Right", "00000000"]]
	]
	upper = [
		[["1", "00000000"],          ["2", "00000000"],         ["3", "00000000"],      ["4", "00000000"],      ["5", "00000000"],       ["6", "00000000"],    ["7", "00000000"],          ["8", "00000000"],          ["9", "00000000"],        ["0", "00000000"]],
		[["Apostrophe", "00000000"], ["Backquote", "00000000"], ["Null", "00000000"],   ["Null", "00001000"],   ["Null", "00000000"],    ["Null", "00000000"], ["O_SBracket", "00000000"], ["C_SBracket", "00000000"], ["Minus", "00000000"],    ["Equal", "00000000"]],
		[["Null", "00000000"],       ["CapsLock", "00000000"],  ["M_LBTN", "00000000"], ["M_RBTN", "00000000"], ["M_WHEEL", "00000000"], ["Null", "00000000"], ["Null", "00000000"],       ["Comma", "00000000"],      ["Period", "00000000"],   ["Backslash", "00000000"]],
		[["Null", "00000000"],       ["LNPH", "00000000"],      ["LAYOUT", "00000000"], ["Null", "00000000"],   ["Null", "00000001"],    ["Null", "00000000"], ["Null", "00000000"],       ["MGain_Down", "00000000"], ["MGain_Up", "00000000"], ["Reset", "00000000"]]
	]
	stick = [
		[
			["Null", "00000000"], ["Upper", "00000000"], ["Null", "00000000"],
			["BS",   "00000000"], ["Null",  "00000000"], ["Tab",  "00000000"],
			["Null", "00000000"], ["Enter", "00000000"], ["Null", "00000000"]
		],
		[
			["Null", "00000000"], ["Null", "00100000"], ["Null",  "00000000"],
			["Del",  "00000000"], ["Null", "00000000"], ["Space", "00000000"],
			["Null", "00000000"], ["Esc",  "00000000"], ["Null",  "00000000"]
		]
	]
	led = [
		[0x00, 0xAE, 0xEF],
		[0xEF, 0x00, 0xAE],
		[0xAE, 0xEF, 0x00]
	]
    intensity = [
        1.0
    ]

[layout2]
	normal = [
		[["Apostrophe", "00000000"], ["Comma", "00000000"], ["O", "00000000"],     ["U", "00000000"],    ["Y", "00000000"],      ["F", "00000000"],    ["G", "00000000"],    ["C", "00000000"],    ["R", "00000000"],  ["L", "00000000"]],
		[["P", "00000000"],          ["I", "00000000"],     ["E", "00000000"],     ["A", "00000000"],    ["Period", "00000000"], ["D", "00000000"],    ["S", "00000000"],    ["T", "00000000"],    ["H", "00000000"],  ["Z", "00000000"]],
		[["J", "00000000"],          ["Q", "00000000"],     ["Colon", "00000000"], ["K", "00000000"],    ["X", "00000000"],      ["B", "00000000"],    ["M", "00000000"],    ["W", "00000000"],    ["N", "00000000"],  ["V", "00000000"]],
		[["Null", "00000000"],       ["Null", "00001000"],  ["Null", "00000100"],  ["Null", "00000000"], ["Null", "00000001"],   ["Null", "00000000"], ["Left", "00000000"], ["Down", "00000000"], ["Up", "00000000"], ["Right", "00000000"]]
	]
	upper = [
		[["1", "00000000"],          ["2", "00000000"],        ["3", "00000000"],      ["4", "00000000"],      ["5", "00000000"],       ["6", "00000000"],    ["7", "00000000"],          ["8", "00000000"],          ["9", "00000000"],         ["0", "00000000"]],
		[["Apostrophe", "00000000"], ["Comma", "00000000"],    ["Null", "00000000"],   ["Null", "00001000"],   ["Period", "00000000"],  ["Null", "00000000"], ["O_SBracket", "00000000"], ["C_SBracket", "00000000"], ["Slash", "00000000"],     ["Minus", "00000000"]],
		[["Null", "00000000"],       ["CapsLock", "00000000"], ["M_LBTN", "00000000"], ["M_RBTN", "00000000"], ["M_WHEEL", "00000000"], ["Null", "00000000"], ["Equal", "00000000"],      ["Null", "00000000"],       ["Backquote", "00000000"], ["Backslash", "00000000"]],
		[["Null", "00000000"],       ["LNPH", "00000000"],     ["LAYOUT", "00000000"], ["Null", "00000000"],   ["Null", "00000001"],    ["Null", "00000000"], ["Null", "00000000"],       ["MGain_Down", "00000000"], ["MGain_Up", "00000000"],  ["Reset", "00000000"]]
	]
	stick = [
		[
			["Null", "00000000"], ["Upper", "00000000"], ["Null", "00000000"],
			["BS",   "00000000"], ["Null",  "00000000"], ["Tab",  "00000000"],
			["Null", "00000000"], ["Enter", "00000000"], ["Null", "00000000"]
		],
		[
			["Null", "00000000"], ["Null", "00100000"], ["Null",  "00000000"],
			["Del",  "00000000"], ["Null", "00000000"], ["Space", "00000000"],
			["Null", "00000000"], ["Esc",  "00000000"], ["Null",  "00000000"]
		]
	]
	led = [
		[0xFF, 0x00, 0x8C],
		[0x00, 0xFF, 0xFF],
		[0x00, 0x00, 0xFF]
	]
    intensity = [
        1.0
    ]
```

## インストール方法
`go install`でインストールすることが可能です。

```shellscript
$ go install github.com/yamamo2shun1/Confiseur/cmd/confiseur@v0.14.0
```

## 使い方
```Less
-version
        Show the version of the tool installed.
        ex) confiseur -version
-check
        Show information on C4NDY KeyVLM/STK connected to PC/Mac.
        ex) confiseur -check
-list
        Show connected device name list.
        ex) confiseur -list
-id [int]
        Select connected device ID(ID can be checked in -check/-list).
        This option is available when using the following command options.
        If ID is not specified, 0 is the default.
-load
        Show the current key names of the keyboard.
        ex) confiseur -load
            confiseur -load -id 1
-remap [string]
        Apply the keyboard settings from specified toml file.
        ex) confiseur -remap examples/layout_STK.toml
            confiseur -remap examples/layout_KeyVLM.toml -id 0
-save
        Save the keymap written by "remap" to the memory area.
        ex) confiseur -save
            confiseur -id 0 -save
-led [int(0x000000-0xFFFFFF)]
        Set LED RGB value for checking color.
        ex) confiseur -led 0xFF0000 # red
            confiseur id 0 -led 0x00FFFF # cyan
-intensity [float(0.0-1.0)]
        Set LED intensity.
        ex) confiseur -intensity 1.0
            confiseur -id 1 -intensity 0.5
-restart
        Restart the keyboard immediately.
        ex) confiseur -restart
            confiseur -restart -id 1
-factoryreset
        Reset all settings to factory defaults.
        ex) confiseur -factoryreset
            confiseur -id 0 -factoryreset
```

## ツールのビルド
[Go言語](https://go.dev/)の開発環境を各自でご用意ください。
また、ConfiseurではHIDでの通信を行うために[go-hid](https://github.com/sstallion/go-hid)を利用しており、OSごとに下記のような設定が必要になります。

### Windowsの場合
環境変数に`CGO_ENABLED=1`を追加し、[TDM-GCC](https://jmeubank.github.io/tdm-gcc/) などのCコンパイラをインストールしてください。

### macOS/Linuxの場合
ご利用のシェルの設定ファイル（zshの場合は.zshrcなど）に`CGO_ENABLED=1`を加えてください。

## ソースコードからビルドする場合
以下のようにして、ご利用のOS用の実行ファイルを生成してください。
```shellscript
$ git clone https://github.com/yamamo2shun1/Confiseur
$ cd Confiseur/cmd/confiseur
$ go build -o confiseur
```

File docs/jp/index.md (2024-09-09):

---
# https://vitepress.dev/reference/default-theme-home-page
layout: home

hero:
  name: "C4NDY KeyVLM / STK"
  text: "ターンテーブルが接続可能な格子配列キーボード"
  tagline: STM32G491をベースにしたUACとHIDの複合デバイス開発プロジェクト
  image:
    dark: /images/c4ndy-dark.png
    light: /images/c4ndy-light.png
    alt: logo
  actions:
    - theme: brand
      text: 詳しくはコチラ
      link: /jp/features
    - theme: alt
      text: GitHubはコチラ
      link: https://github.com/yamamo2shun1/C4NDY 

features:
  - icon:
      src: /images/keyvlm.png
      width: 560px
    title: C4NDY KeyVLM
    details: 65キー格子配列、オーディオ入出力(フォノ/ライン入力 & HP出力).
    link: https://booth.pm/ja/items/5785829
    linkText: 購入はコチラ
    rel: external
  - icon:
      src: /images/stk.png
      width: 560px
    title: C4NDY STK
    details: 37キー格子配列、34個のフルカラーLED, 2本のジョイスティック、オーディオ入出力(フォノ/ライン入力 & HP出力).
#  - title: Feature C
#    details: Lorem ipsum dolor sit amet, consectetur adipiscing elit
---

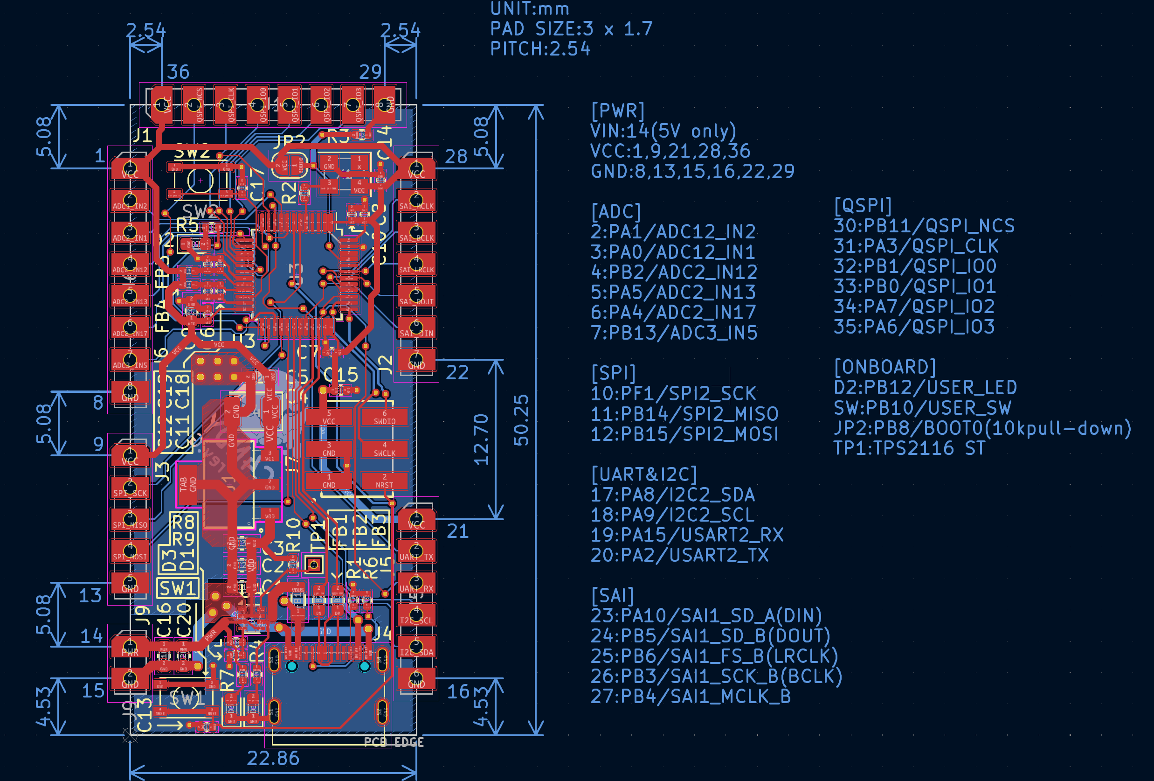
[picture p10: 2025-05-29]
KiCad/C4NDY_mainboard/board_info.png

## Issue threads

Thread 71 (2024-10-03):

ジョイスティックの斜め入力

yamamo2shun1, 2024-10-03:
上下左右のみだった時に比べ、入力精度、速度共に悪くなった。
当初、想定していた左ジョイスティックの上→左上などの連携も思った程使いやすくない。

斜めを正式に採用するには入力を安定させるアイデアが必要。

yamamo2shun1, 2024-10-03:
これはファームの処理の問題よりも、現在使用しているAdafruitのジョイスティック

https://www.adafruit.com/product/2765

のキャップ形状による可能性が高いかもしれない。
キーボードを打つ手の角度でスティックを操作する場合、ゲームのパッドのようにスティックを真上から押さえるのでは無く側面から押す方が操作しやすい。しかし、キャップの背が低いため、側面から押しにくく、かつ背が低いためにモーメントが小さくスティックを倒しにくい。

試しに、キャップの上に小さなゴム足を貼り付けてみたところ、操作性は向上した。
しかし、あまり背を高くしすぎるとキャップが外れやすくなる、ということも分かった。

Closed 2024-11-05.

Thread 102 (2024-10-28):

FLASHデータ書き換えでクラッシュ

yamamo2shun1, 2024-10-28:
USBオーディオ再生中もしくは再生後にFLASHのデータ書き換えを行おうとするとデバイスがクラッシュする。

yamamo2shun1, 2024-10-28:
デバッガーを接続していなければ実害は無さそうなので、いったんクローズとする。

yamamo2shun1, 2024-10-28:
やっぱ発生するので再オープン。

yamamo2shun1, 2024-10-28:
LAYOUTキーとLN/PHキーを押したときに切り替えた状態を即時保存するようにしていたが、この問題を回避するため、いったん即時保存はしないように変更。

状態の保存はConfiseurから行う事とする。

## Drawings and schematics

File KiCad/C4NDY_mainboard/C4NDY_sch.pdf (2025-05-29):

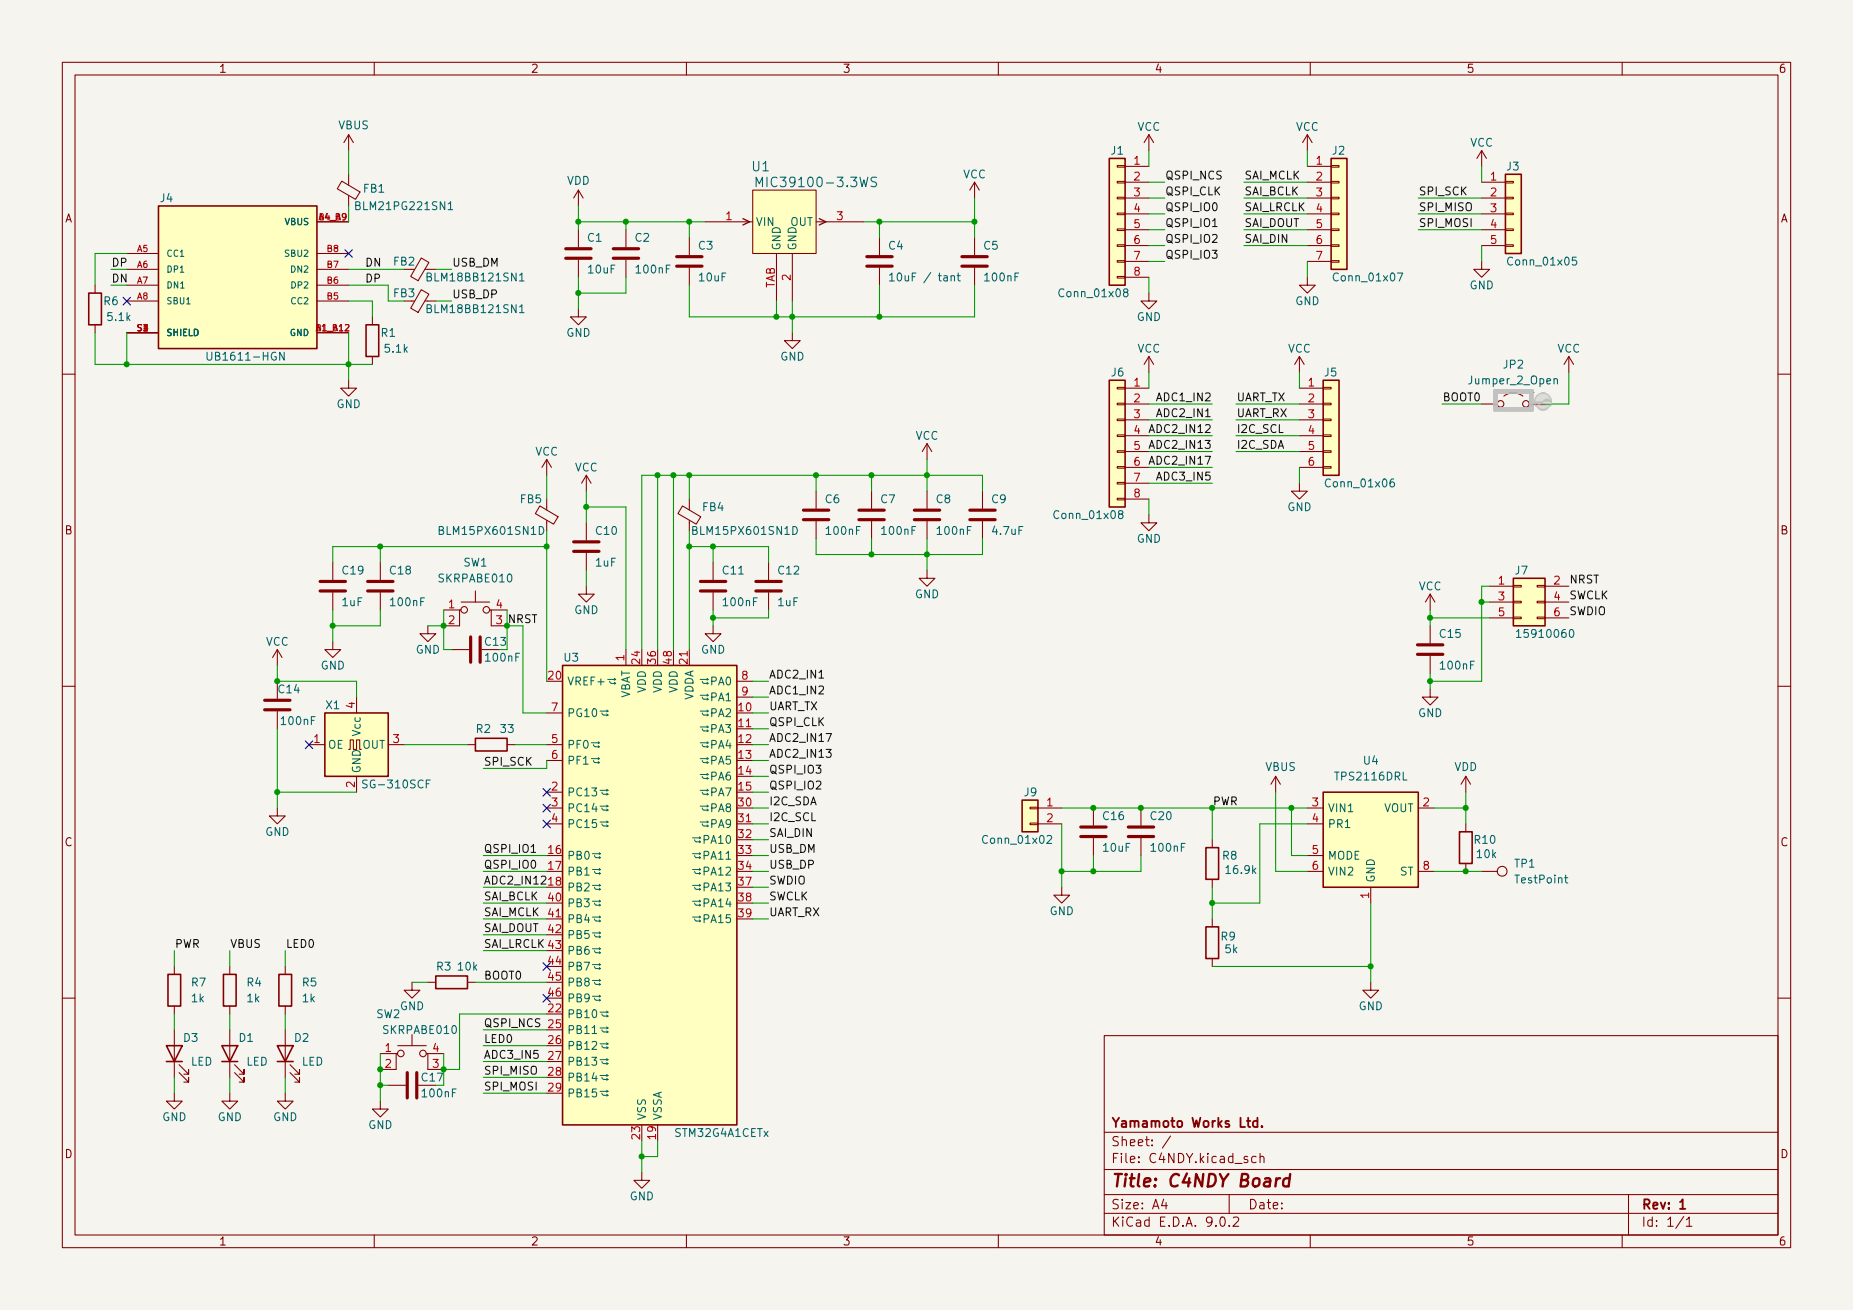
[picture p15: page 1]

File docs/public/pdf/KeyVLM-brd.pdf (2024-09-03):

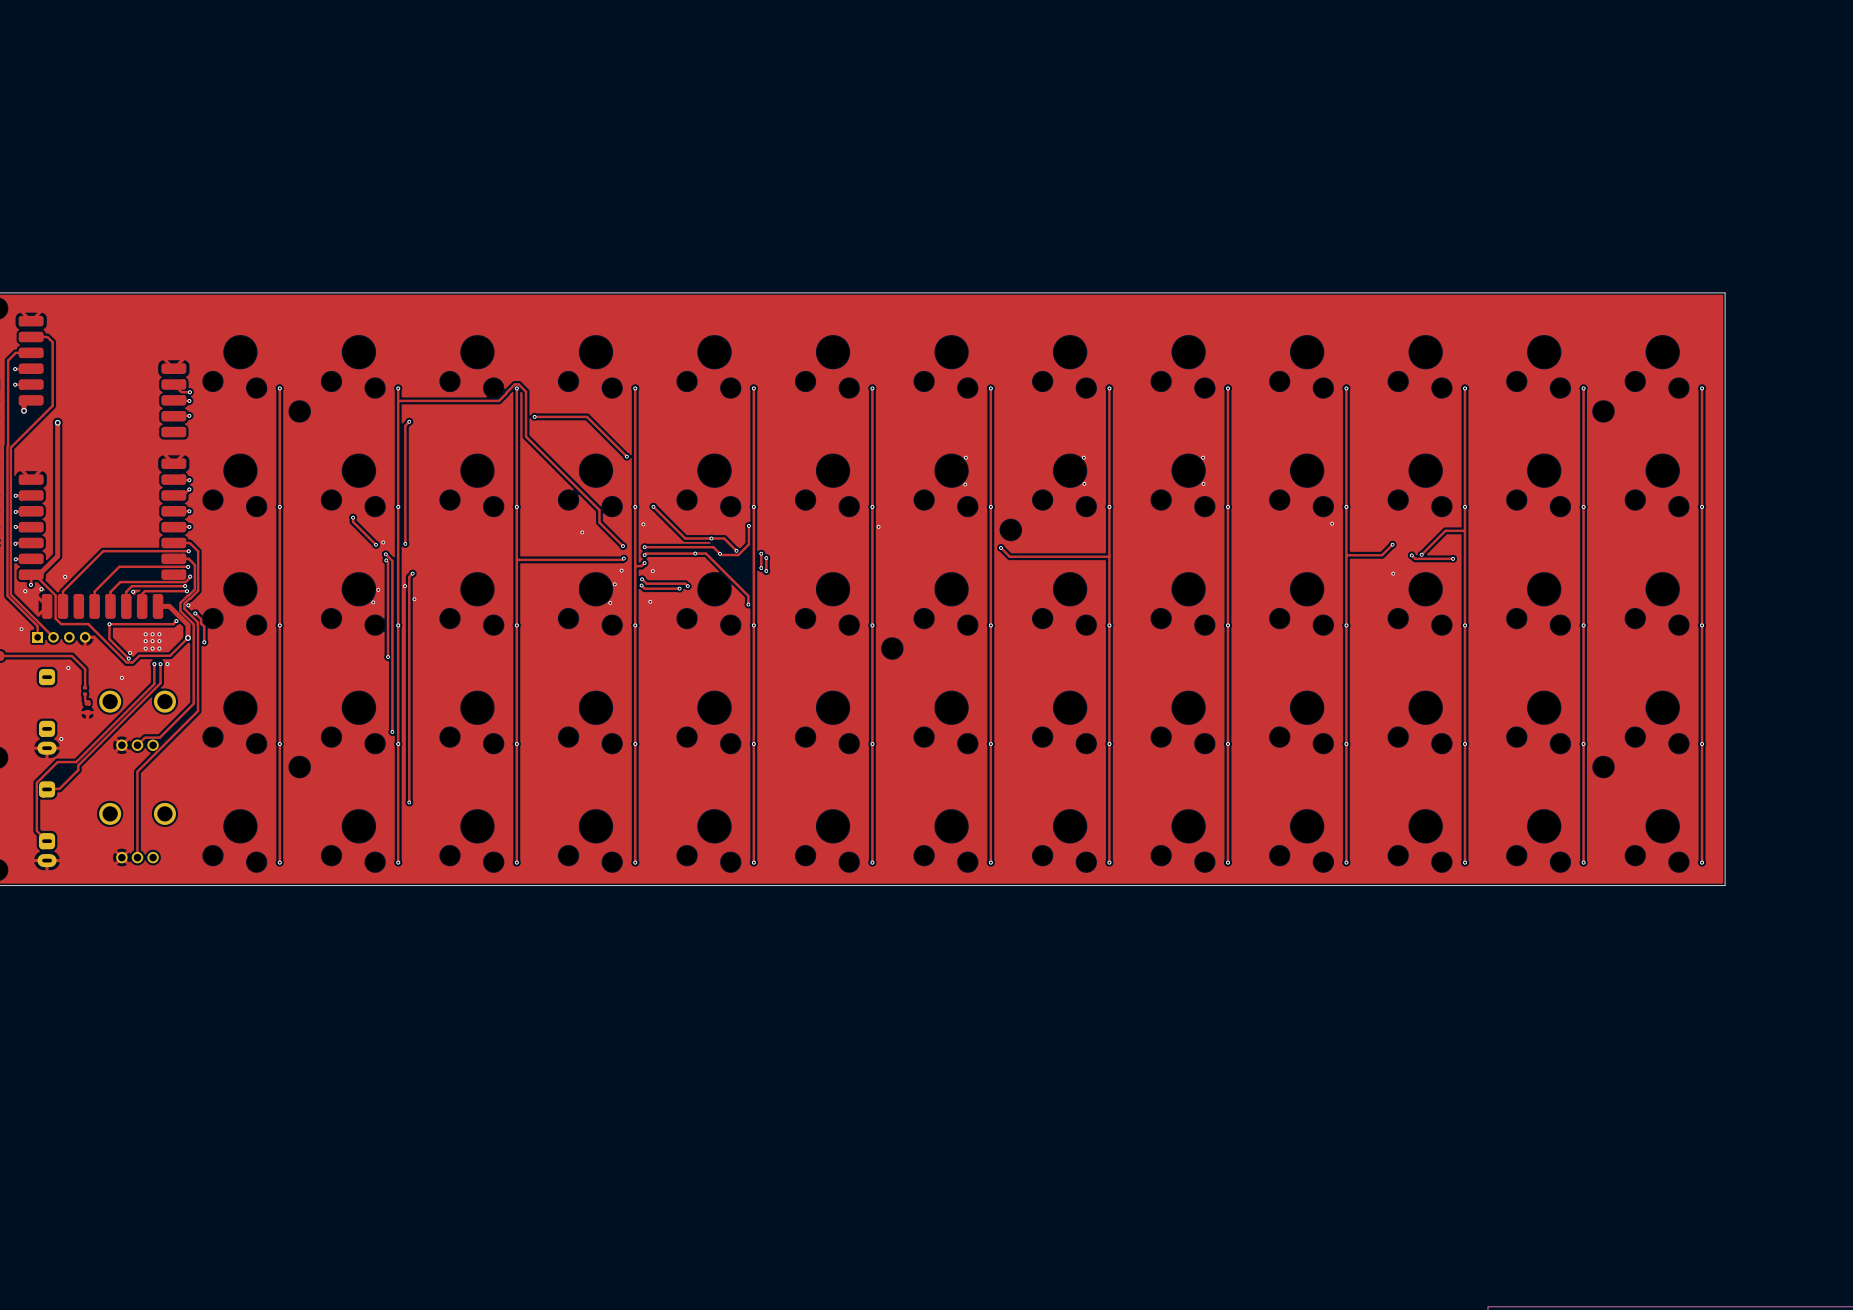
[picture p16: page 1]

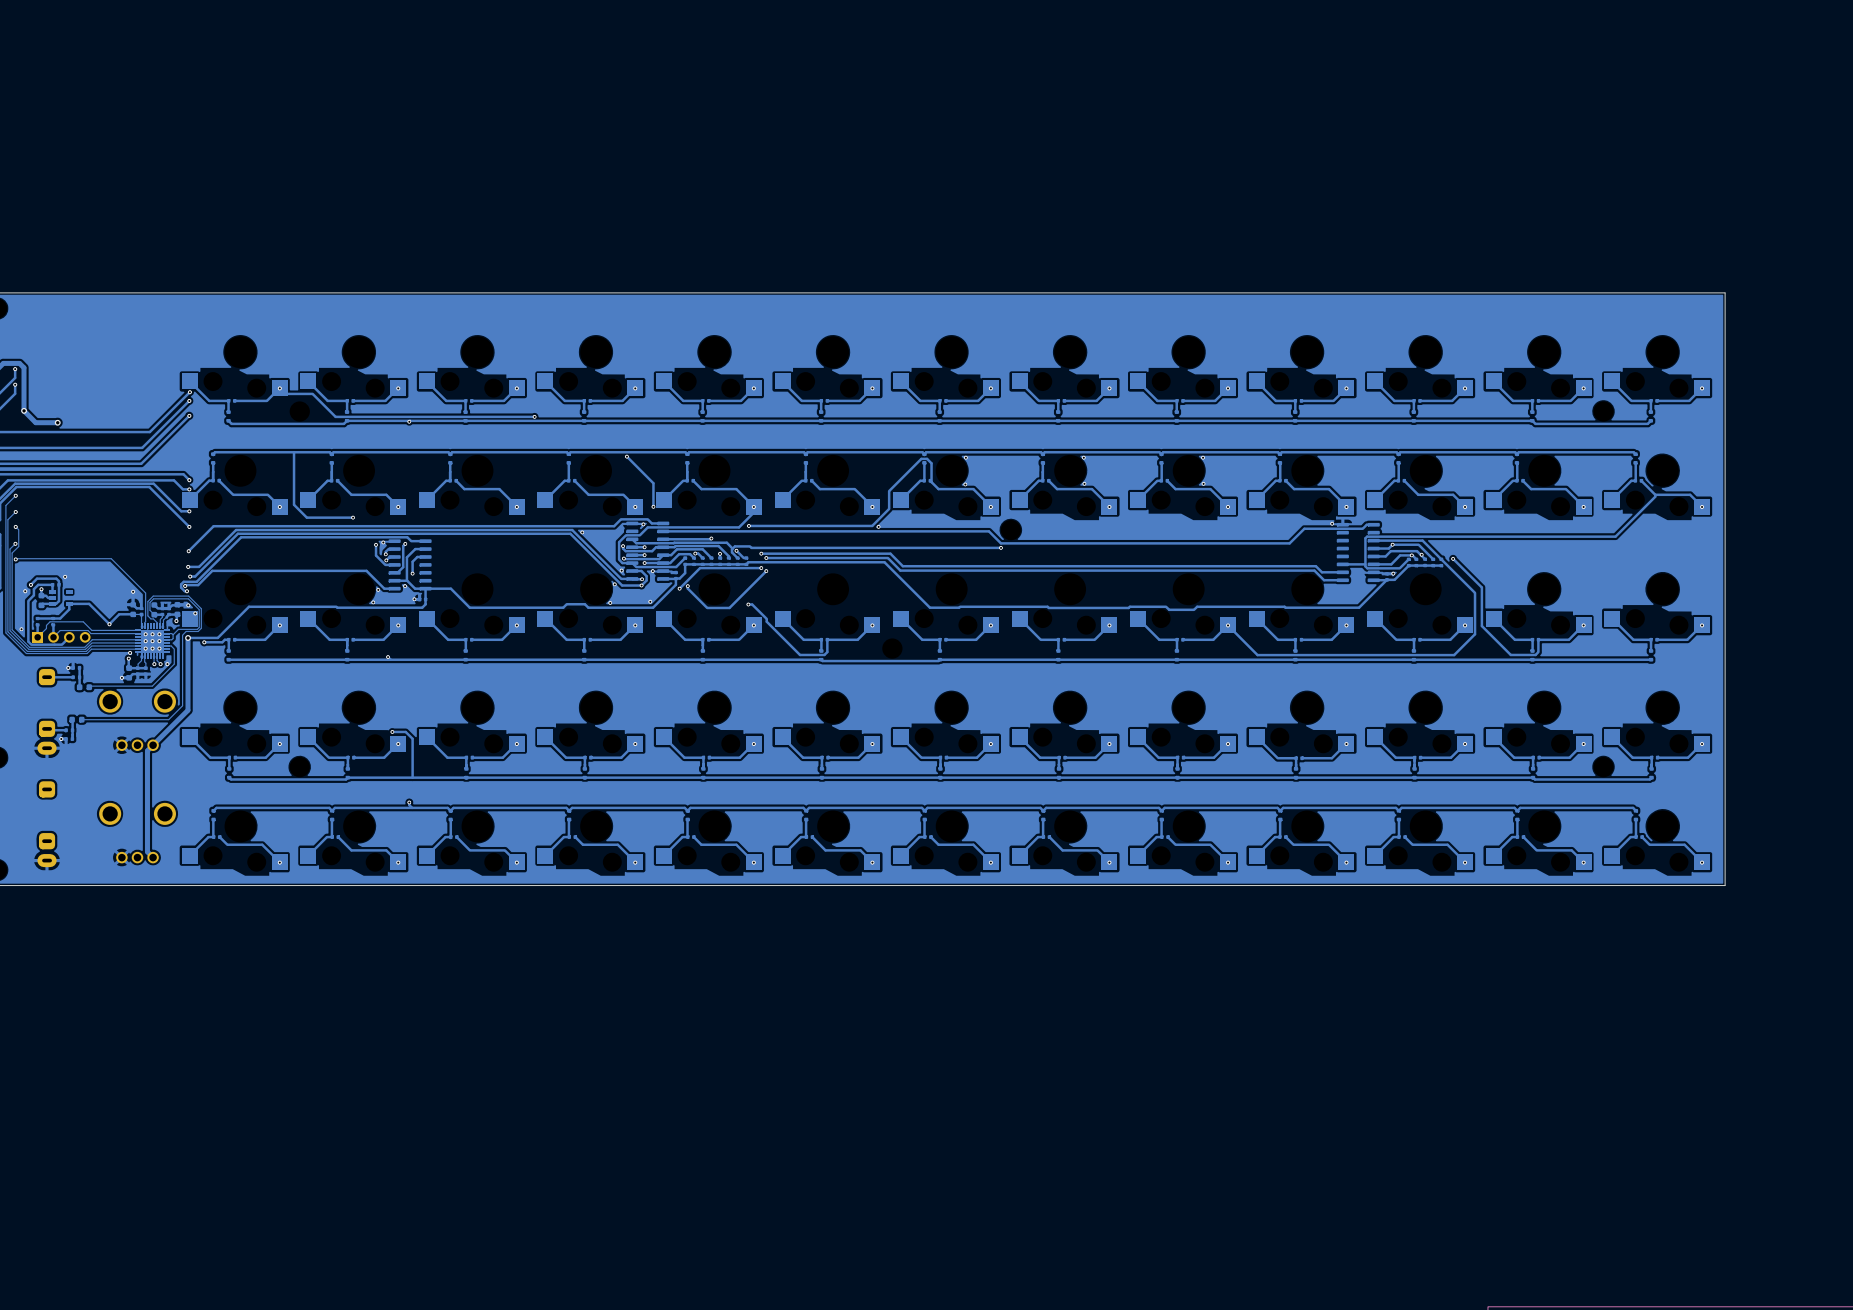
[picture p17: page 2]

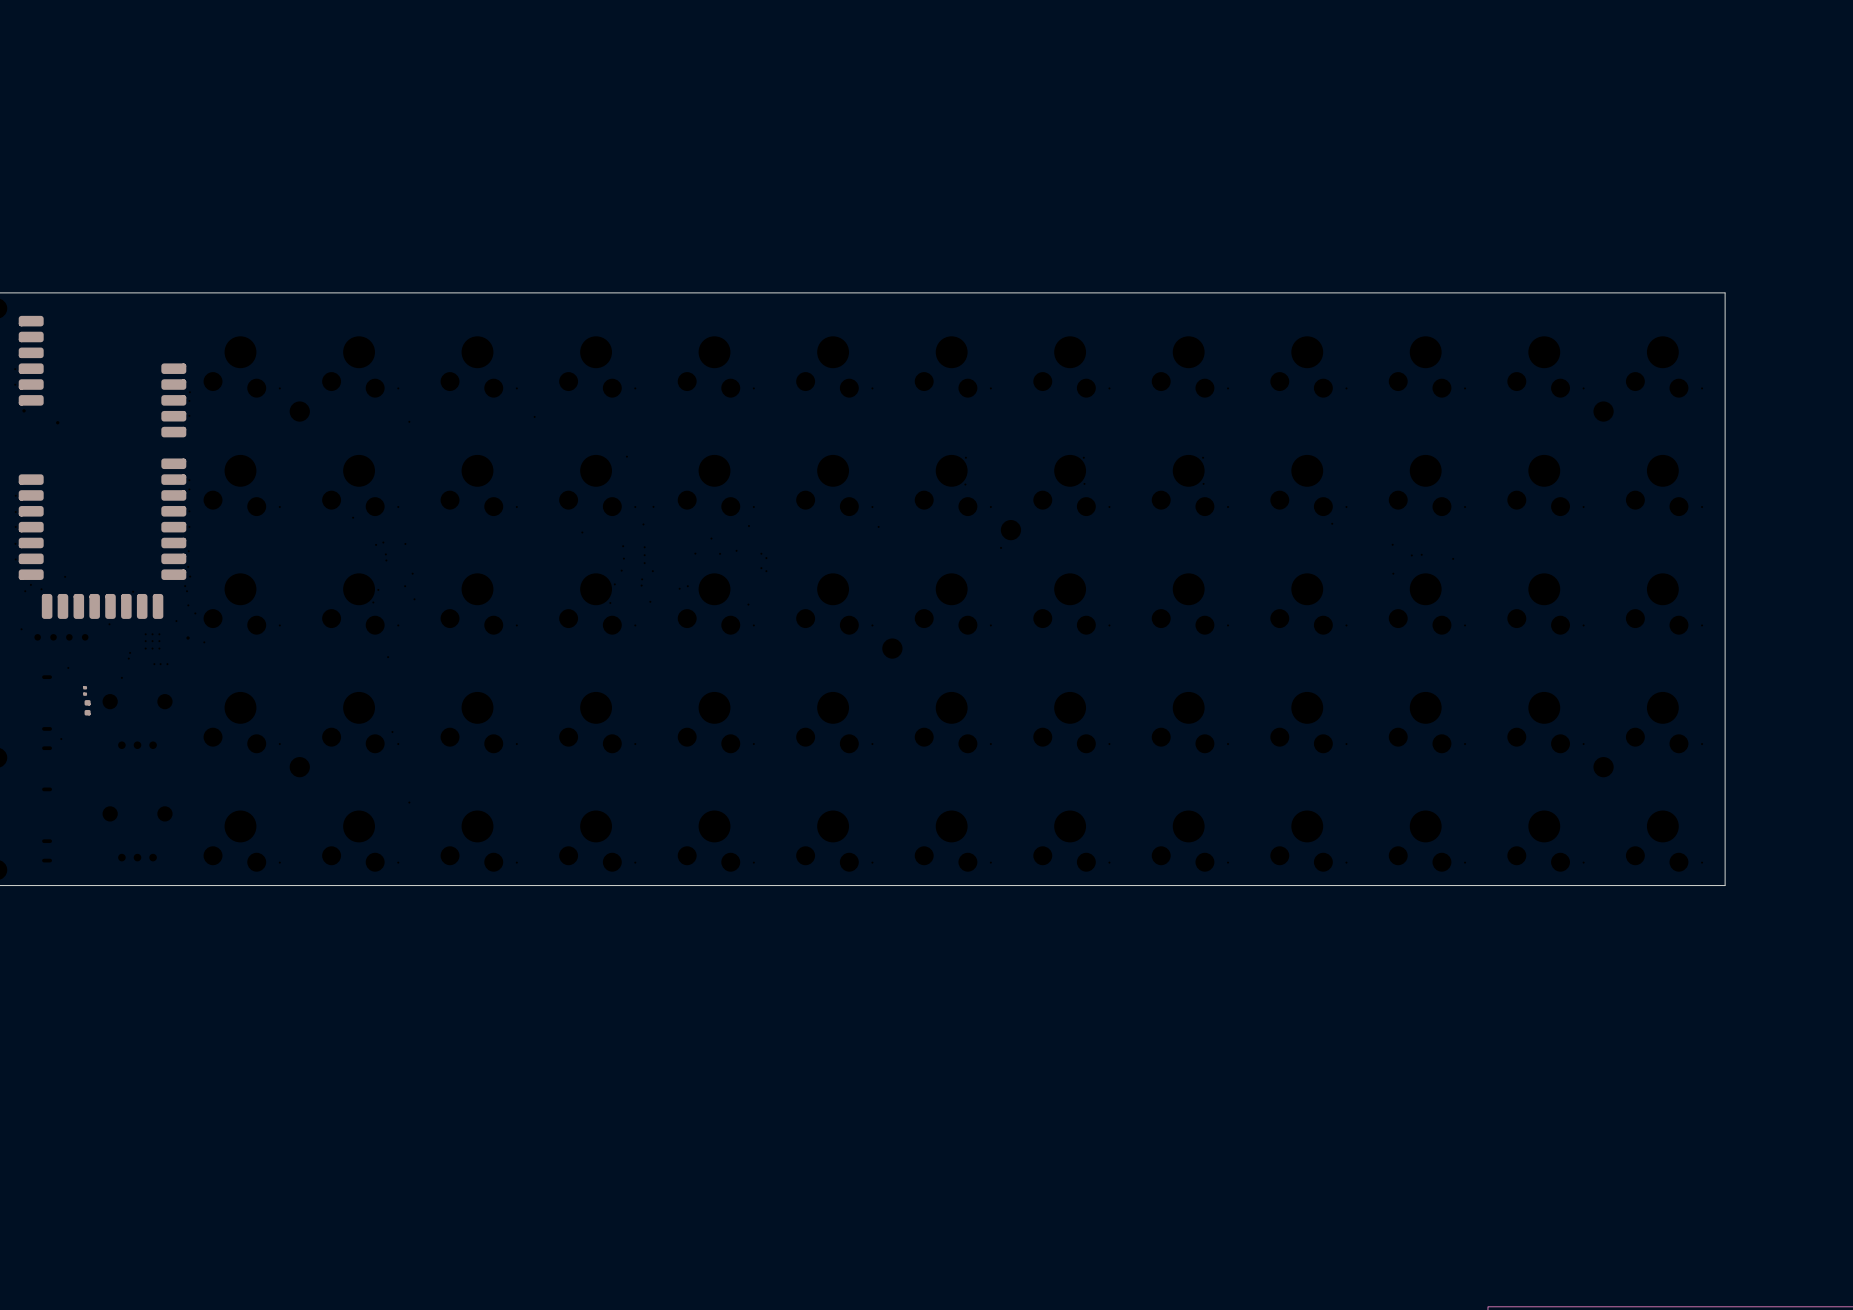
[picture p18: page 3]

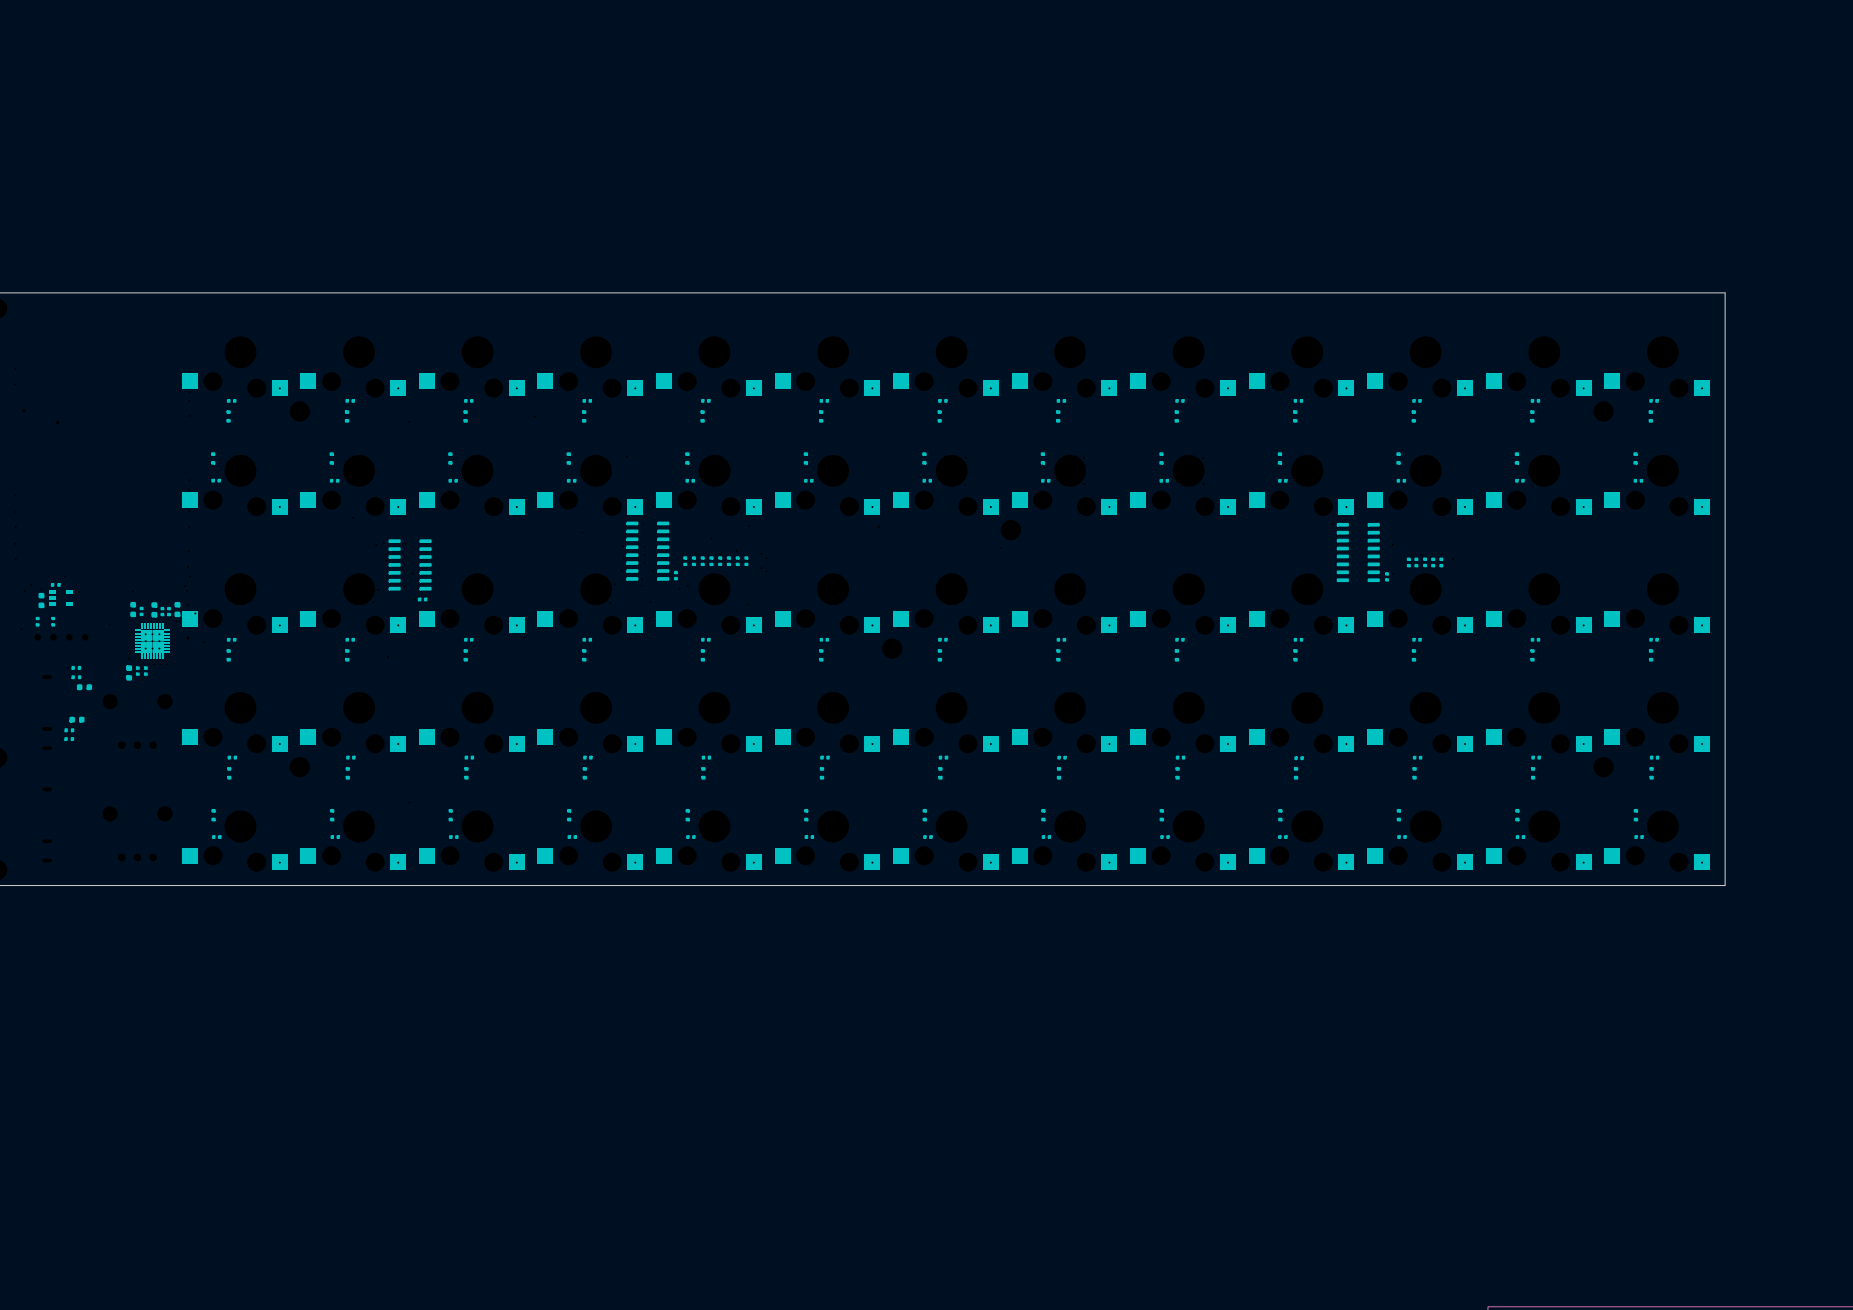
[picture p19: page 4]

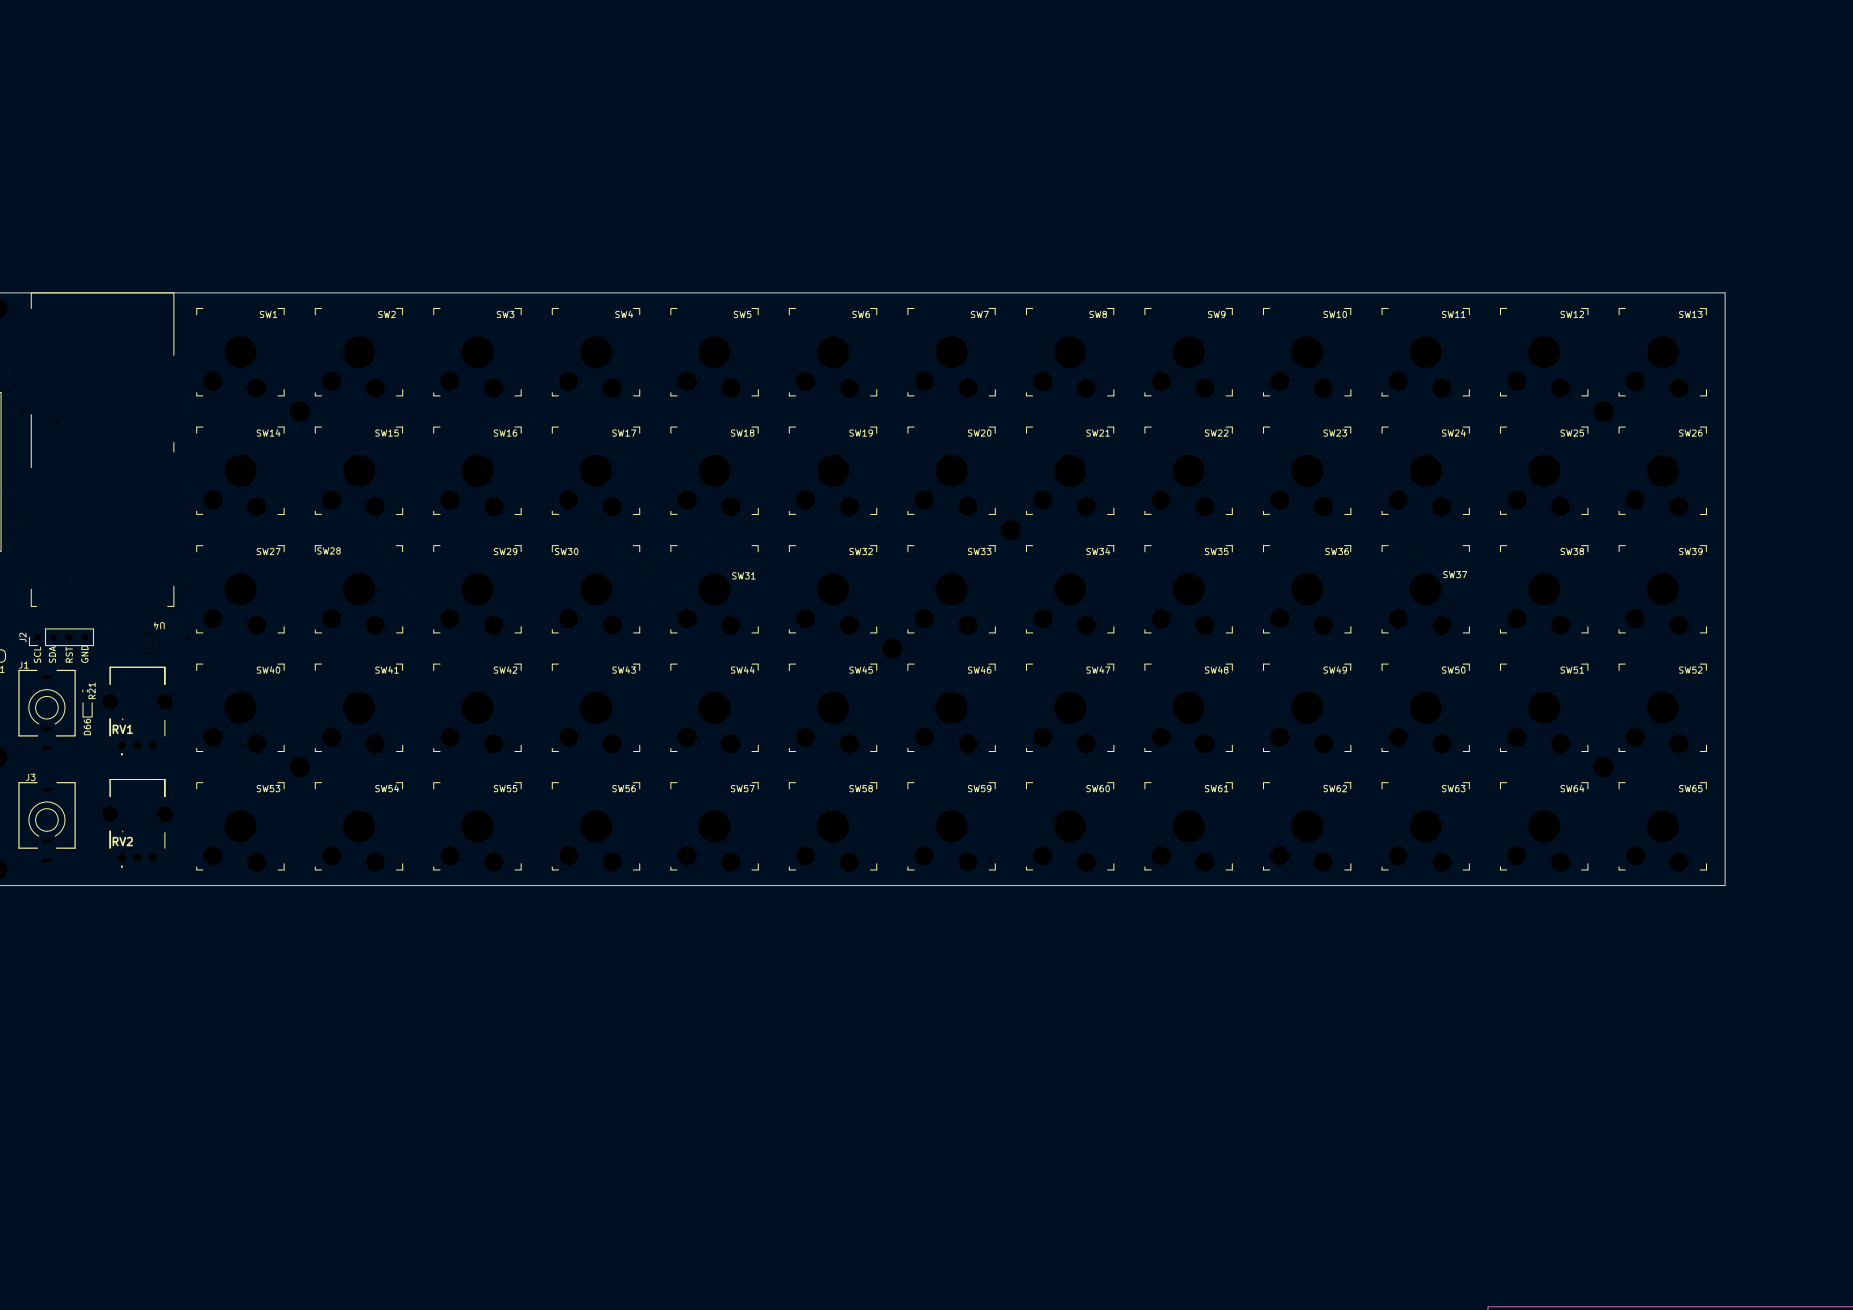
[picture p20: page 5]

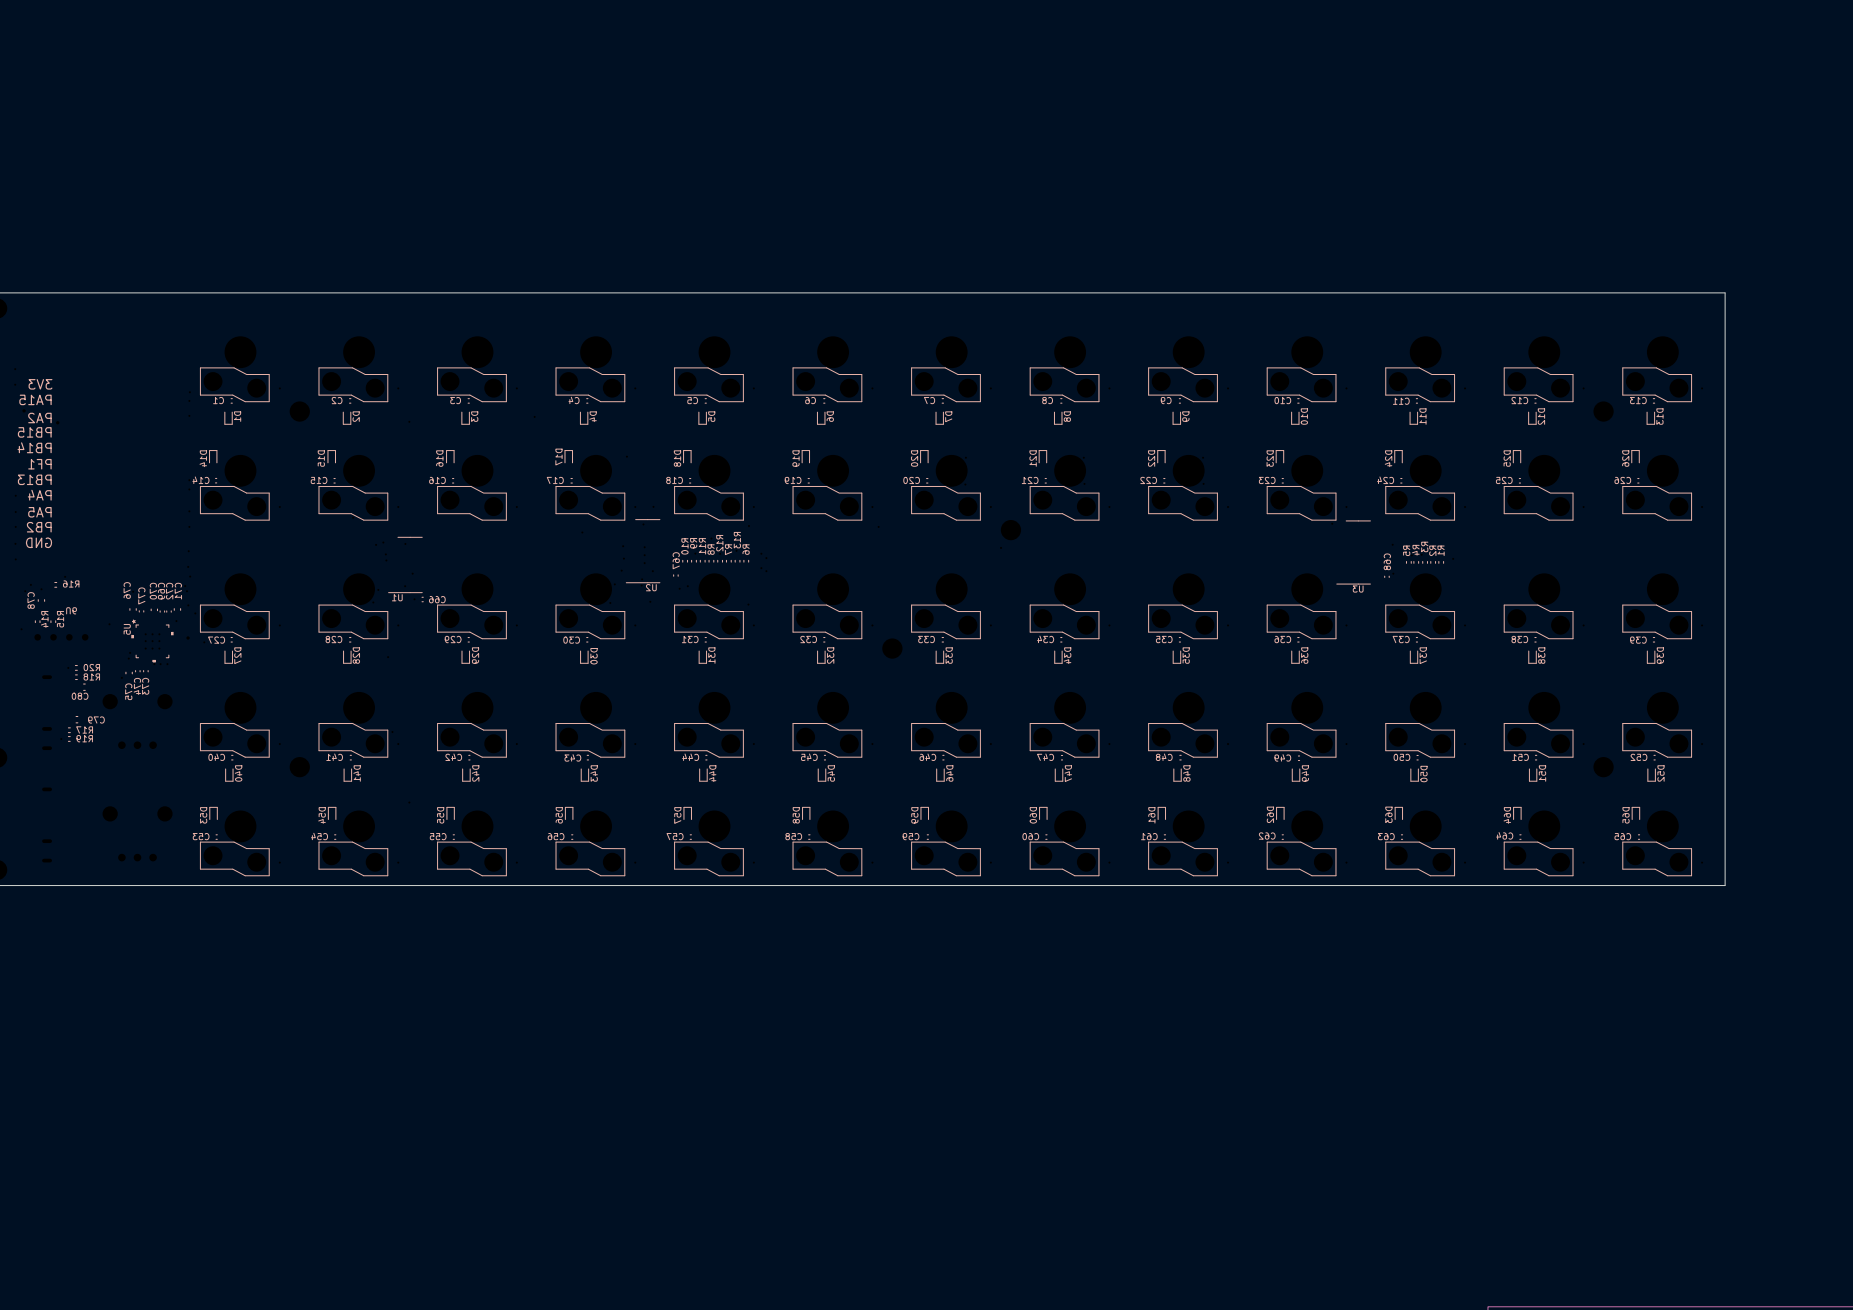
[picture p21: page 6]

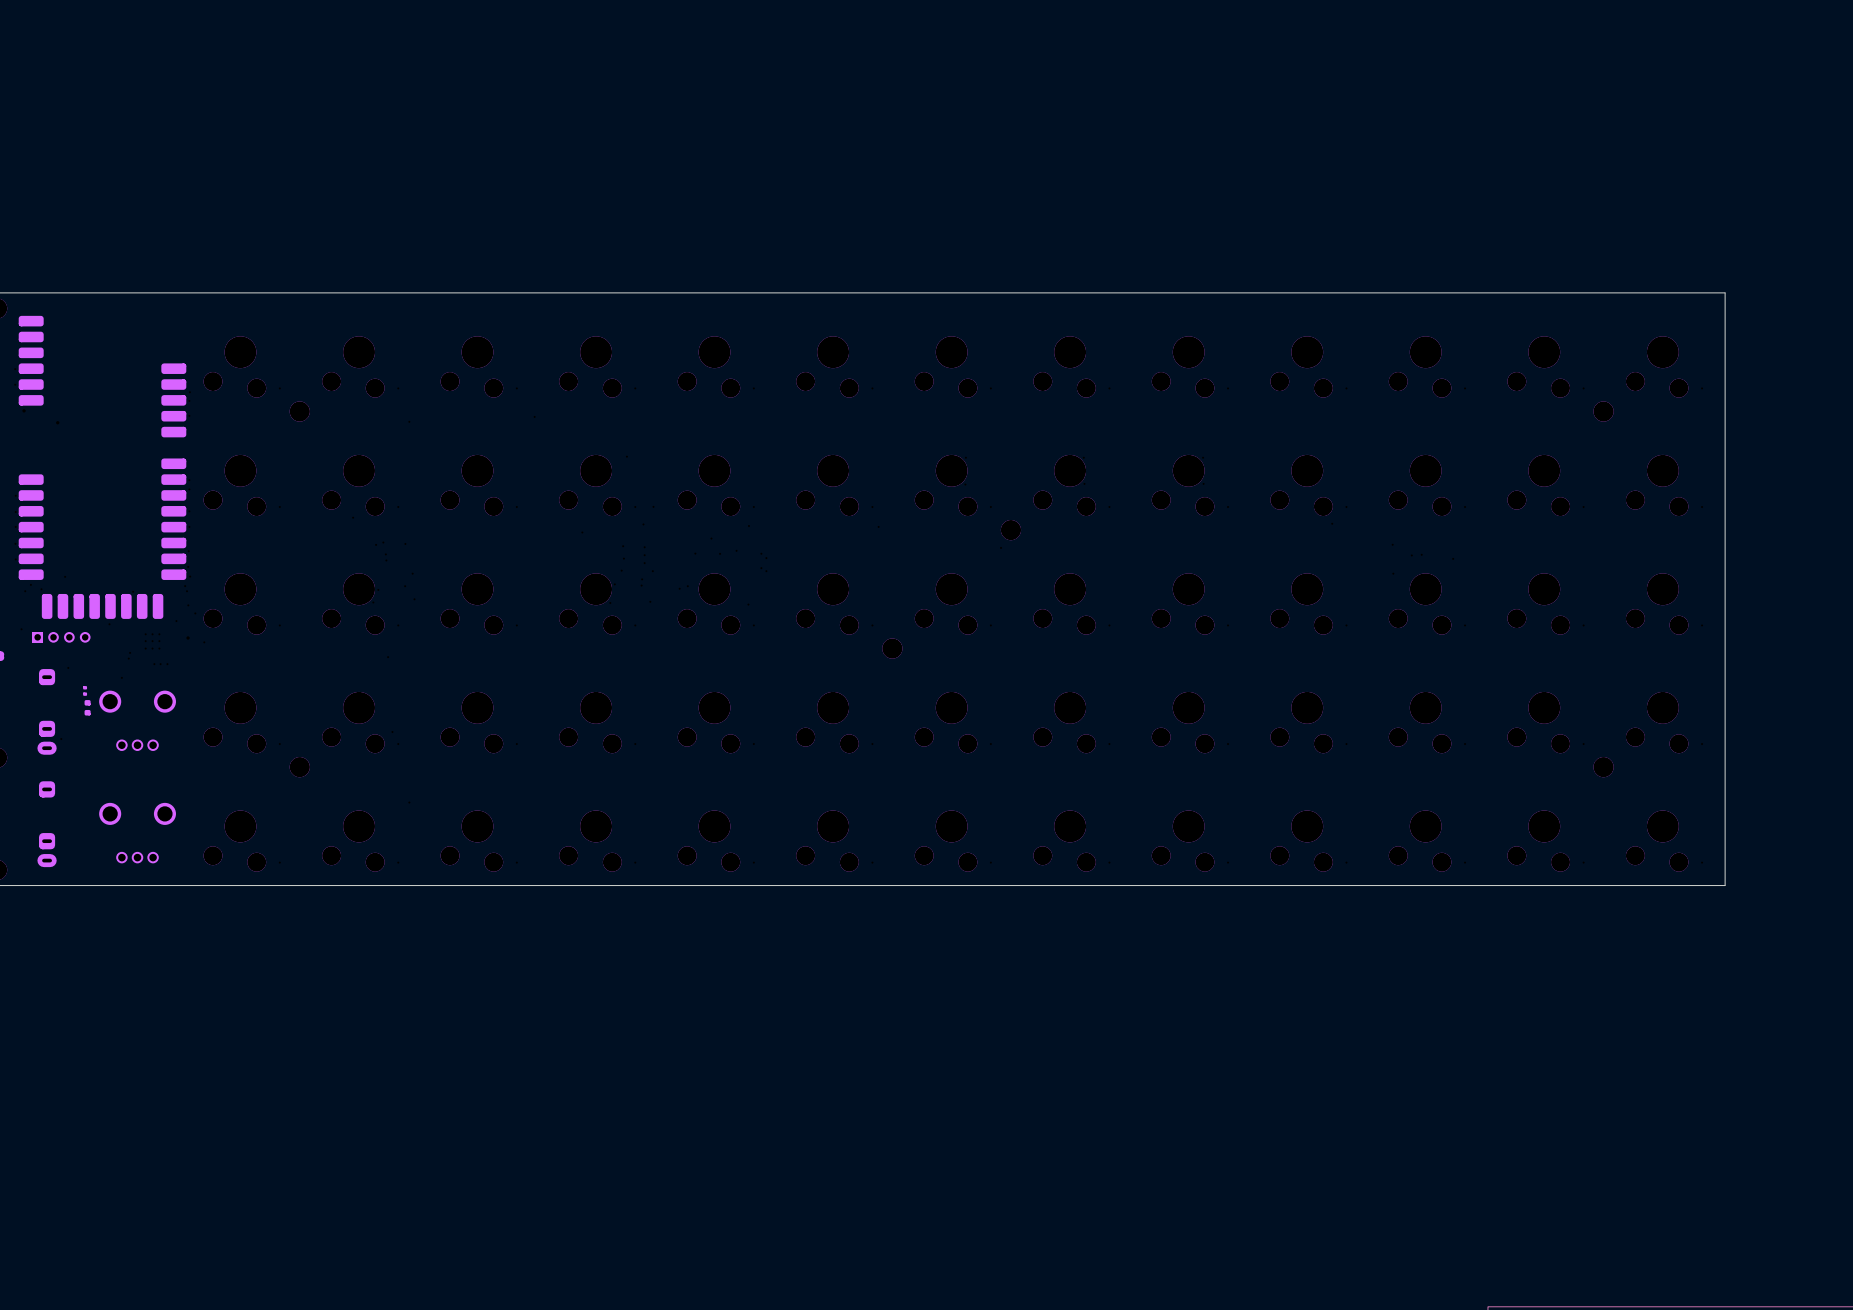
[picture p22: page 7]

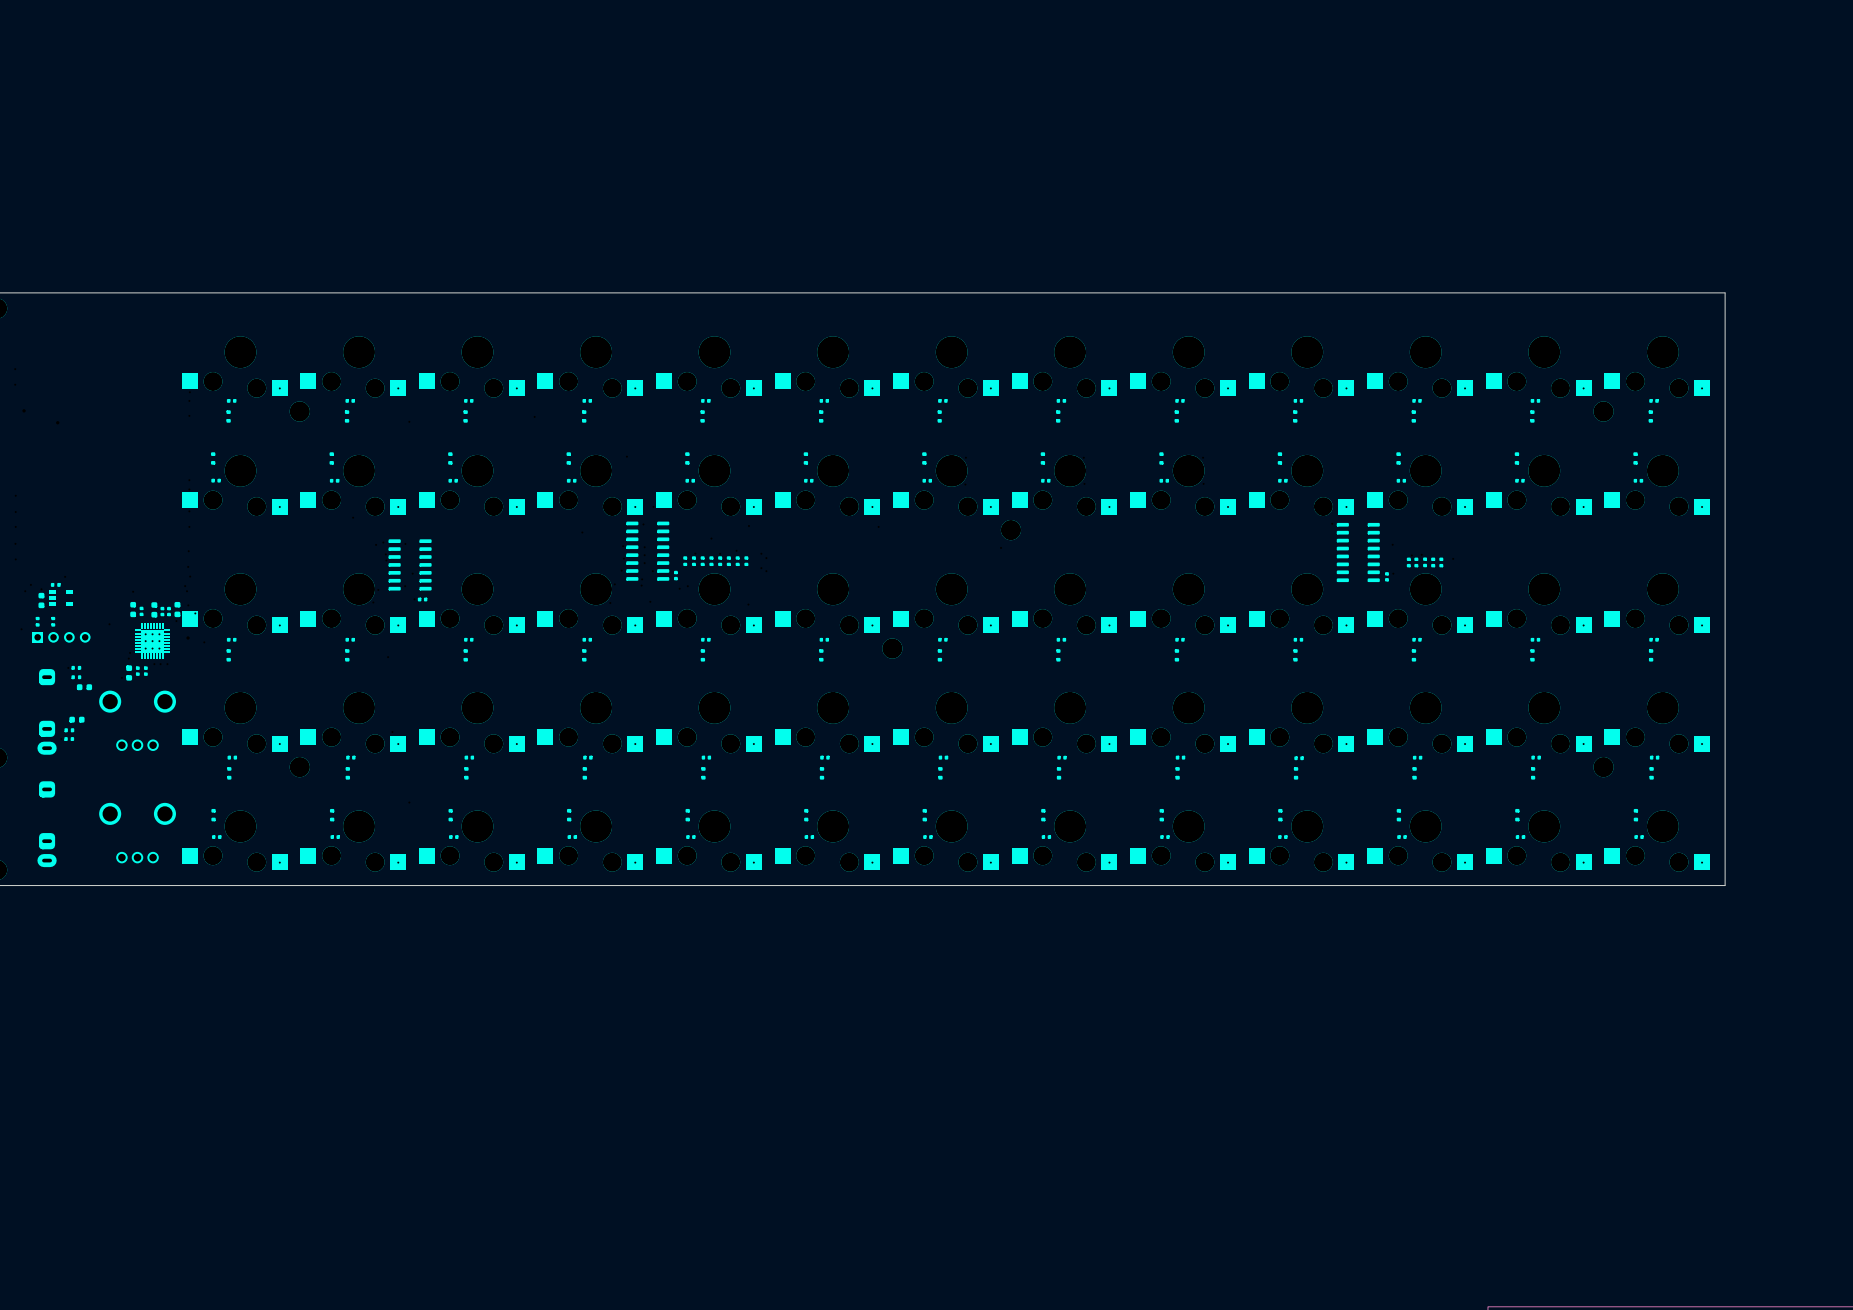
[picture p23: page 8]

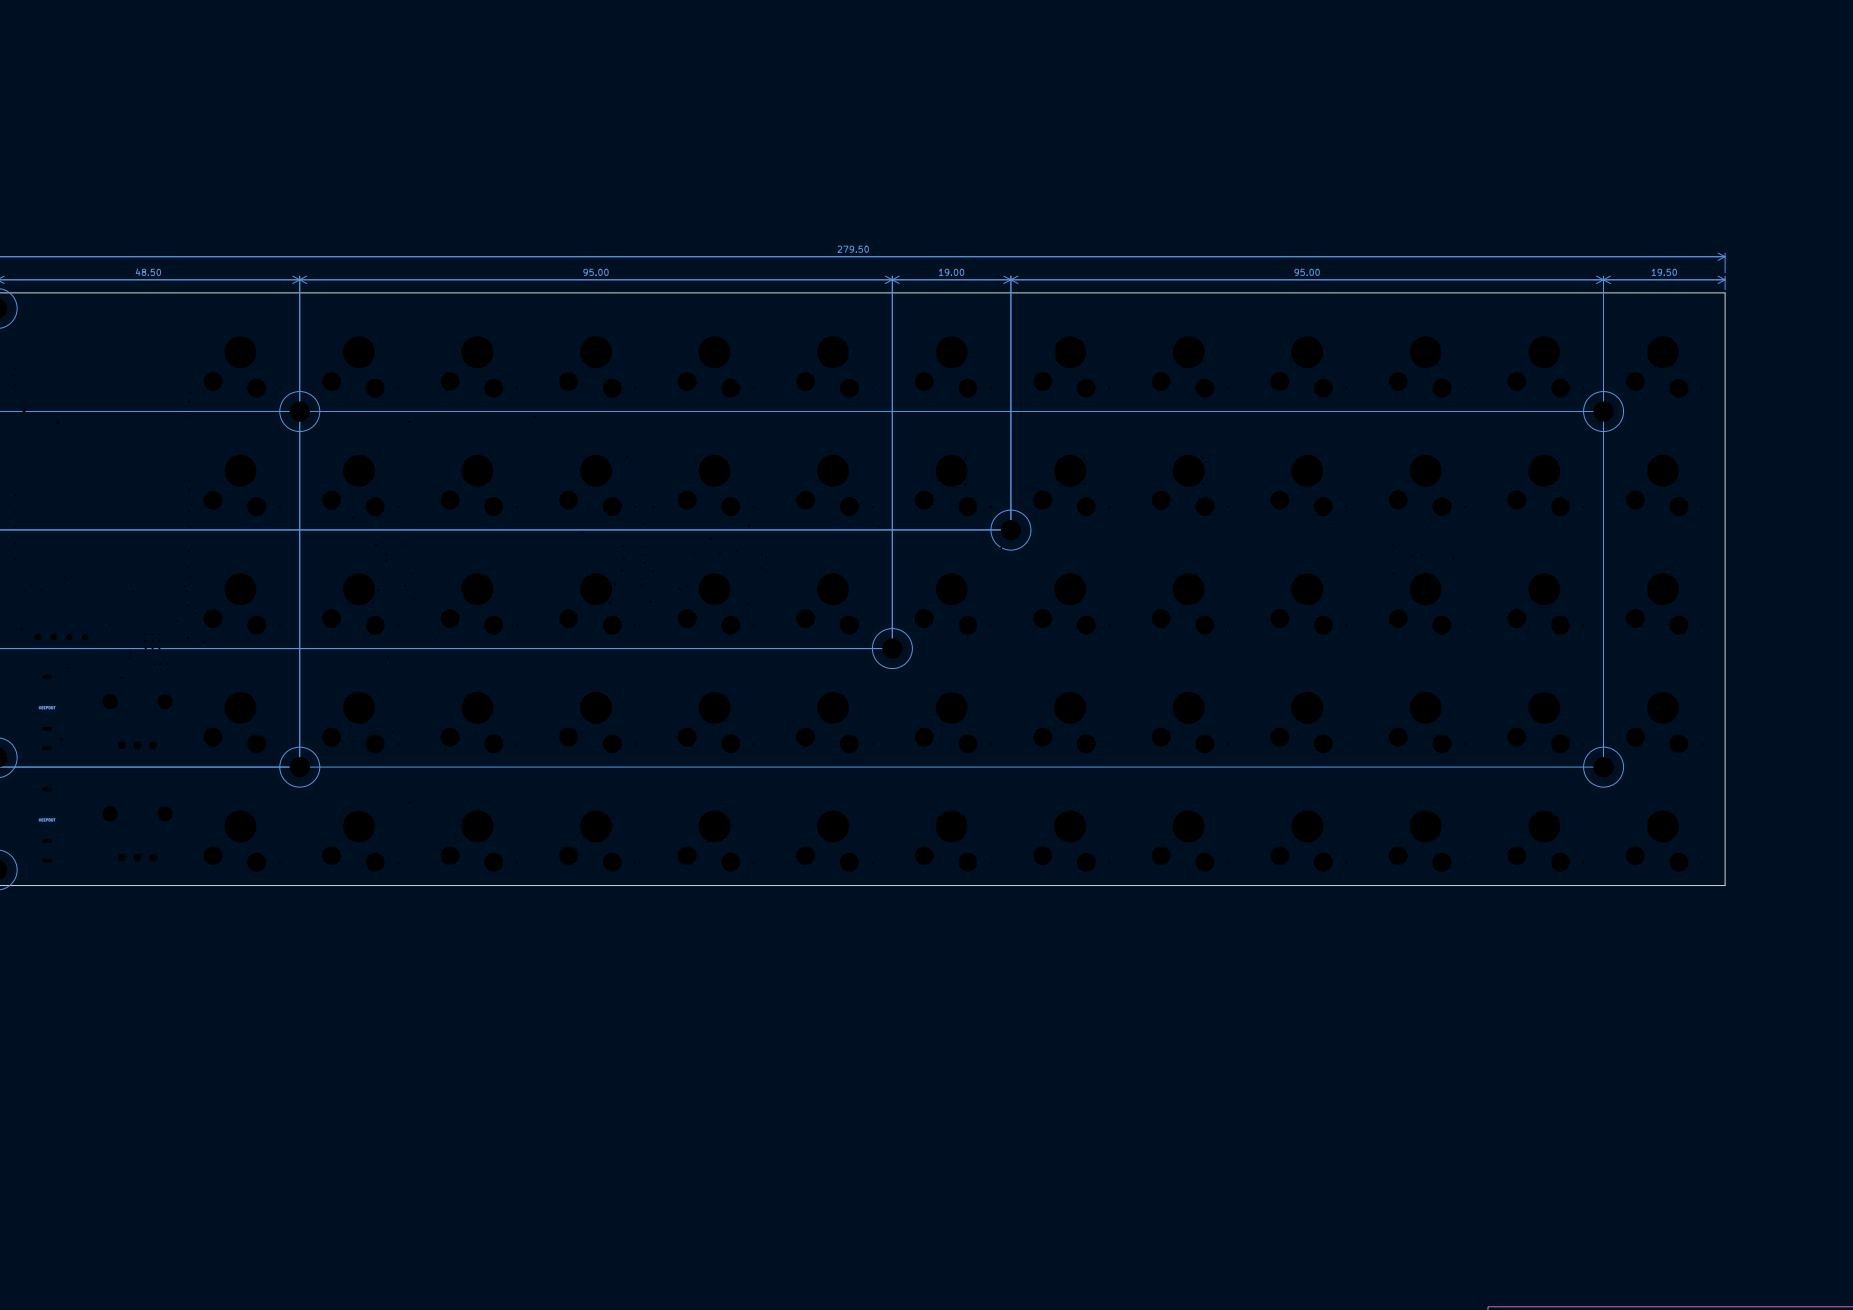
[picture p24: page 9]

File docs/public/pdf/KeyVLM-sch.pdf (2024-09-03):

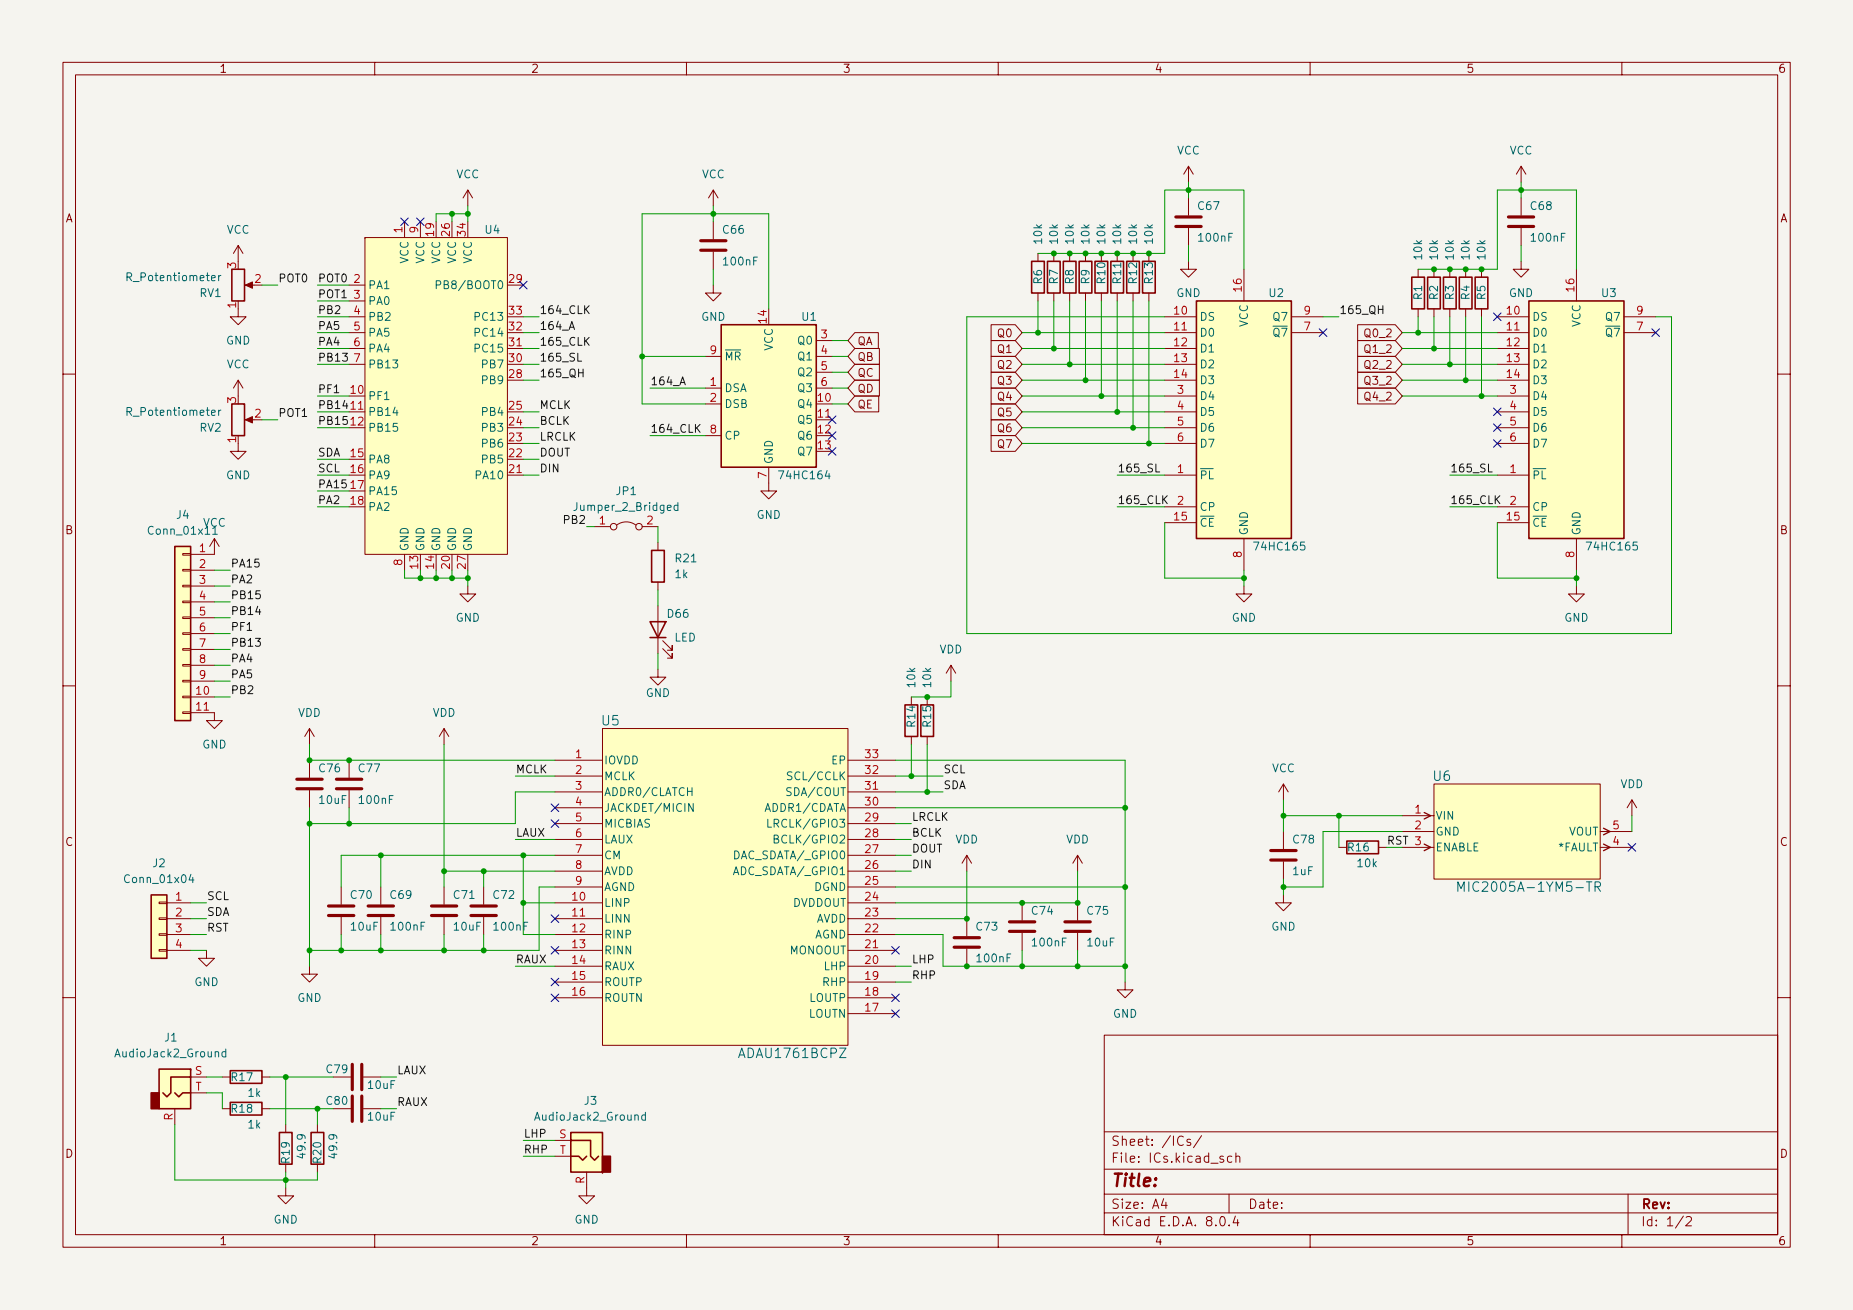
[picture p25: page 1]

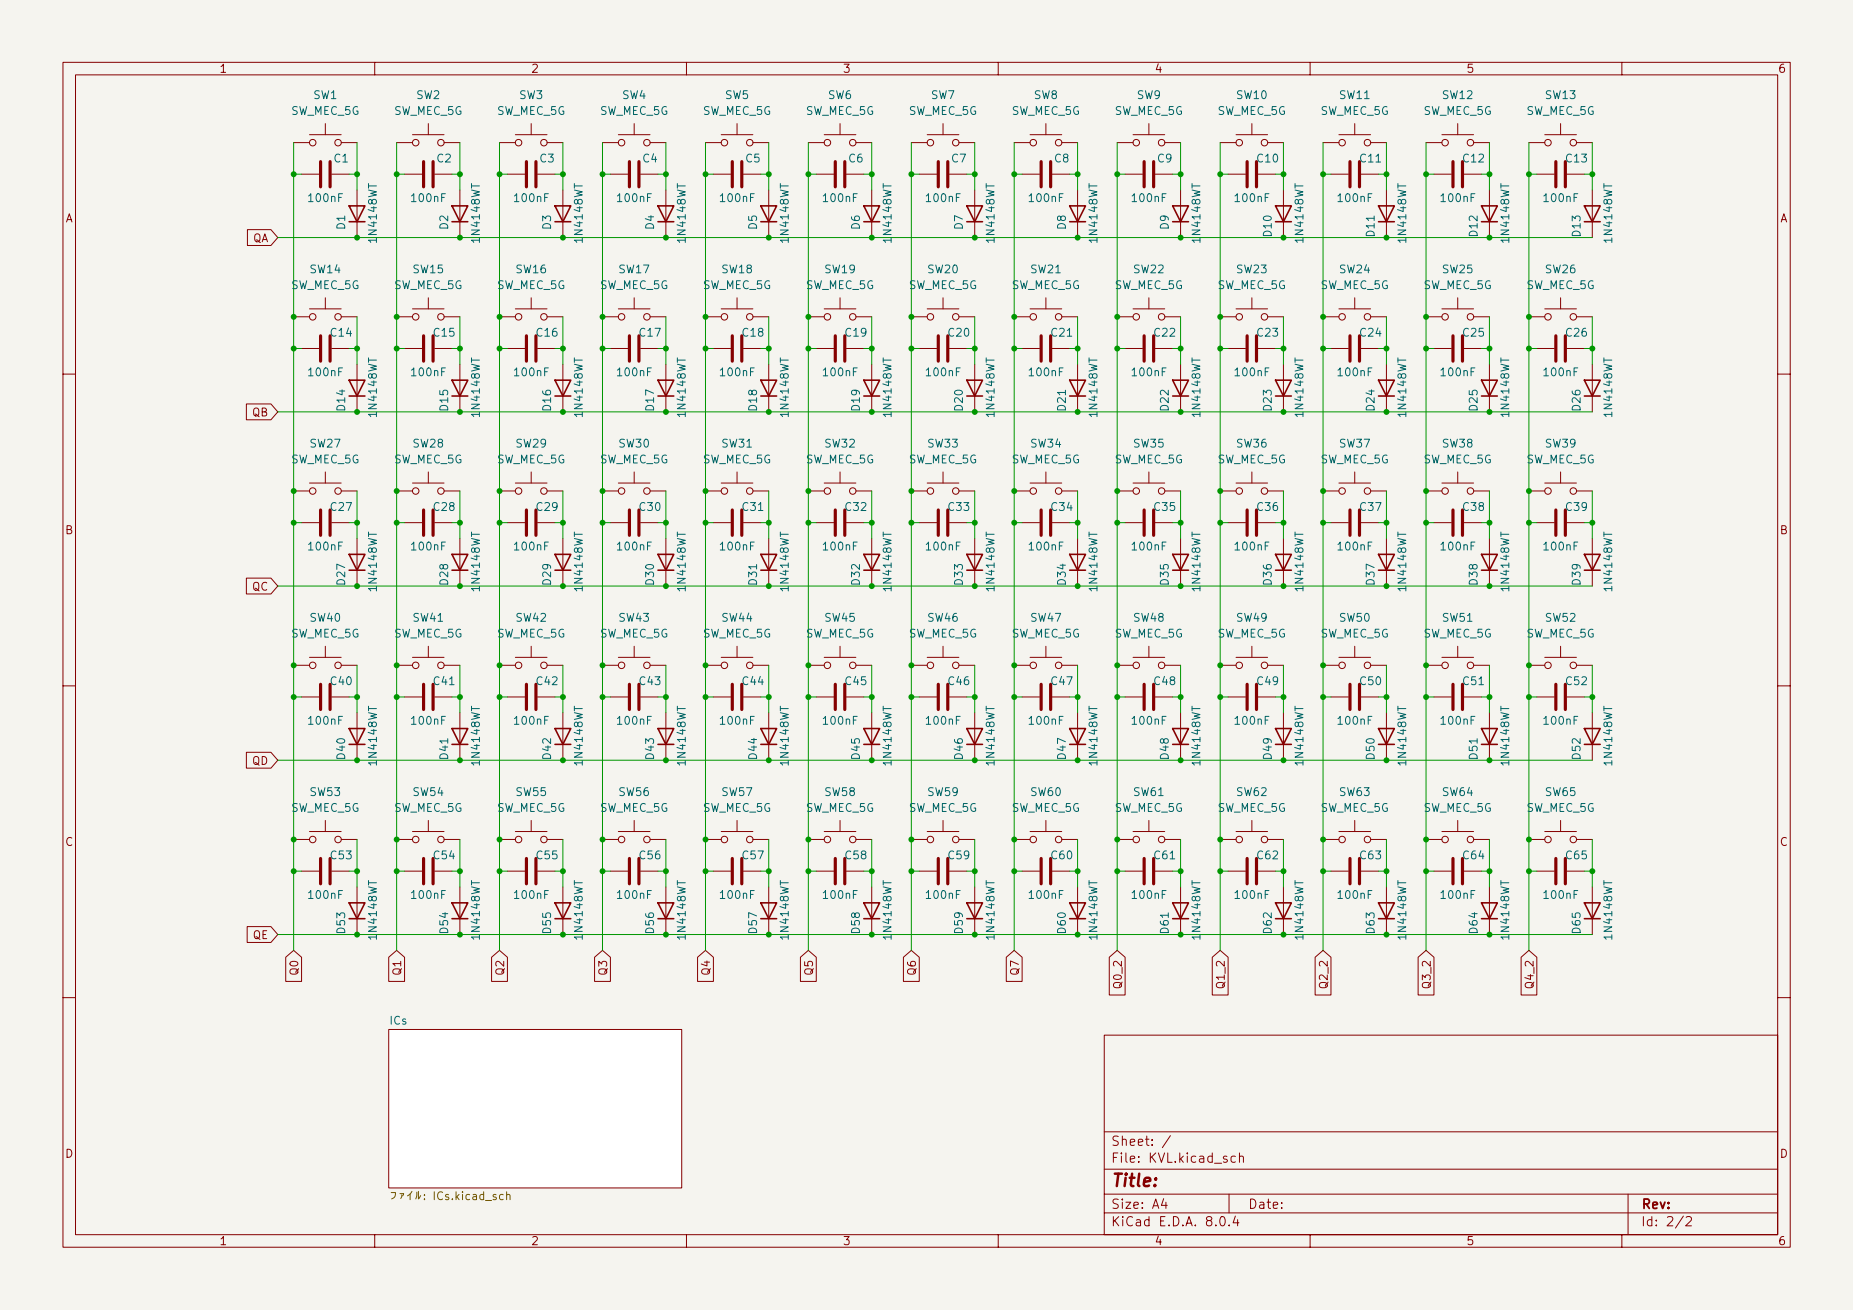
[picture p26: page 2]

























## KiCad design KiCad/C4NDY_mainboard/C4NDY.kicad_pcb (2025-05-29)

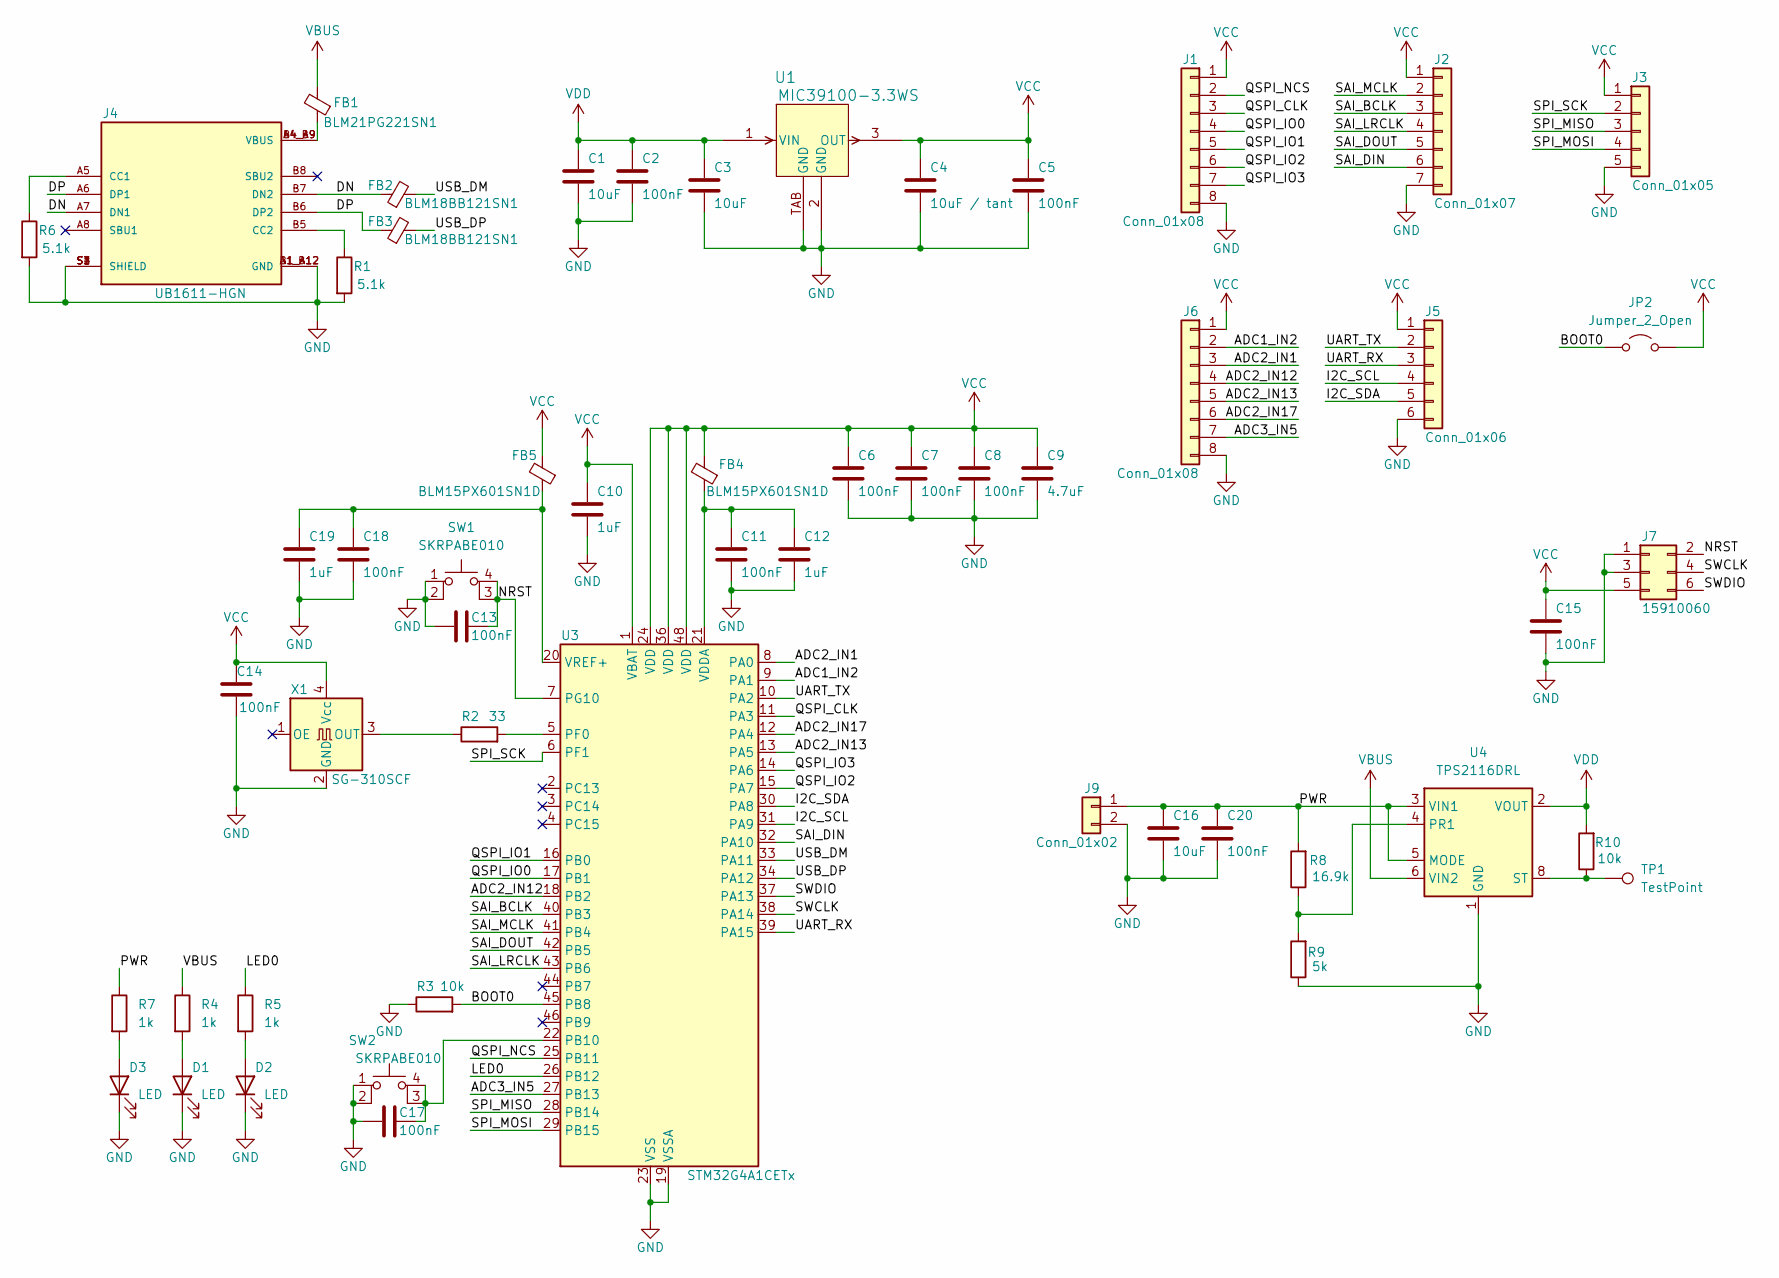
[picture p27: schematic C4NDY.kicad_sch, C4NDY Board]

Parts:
C1, C3, C16: 10uF; C_0603_1608Metric
C2, C5, C20: 100nF; C_0603_1608Metric
C4: 10uF / tant; CP_EIA-3528-12_Kemet-T
C6, C7, C8, C11, C13, C14, C15, C17, C18: 100nF; C_0402_1005Metric
C9: 4.7uF; C_0603_1608Metric
C10, C12, C19: 1uF; C_0402_1005Metric
D1, D2, D3: LED; LED_0603_1608Metric
FB1: BLM21PG221SN1; L_0805_2012Metric
FB2, FB3: BLM18BB121SN1; L_0603_1608Metric
FB4, FB5: BLM15PX601SN1D; L_0402_1005Metric
J1, J6: Conn_01x08; PinHeader_1x08_P2.54mm_Vertical
J2: Conn_01x07; PinHeader_1x07_P2.54mm_Vertical
J3: Conn_01x05; PinHeader_1x05_P2.54mm_Vertical
J4: UB1611-HGN; Gangyuan_UB1611-HGN; PARTREV B
J5: Conn_01x06; PinHeader_1x06_P2.54mm_Vertical
J7: 15910060; Molex_15910060
J9: Conn_01x02; PinHeader_1x02_P2.54mm_Vertical
JP2: Jumper_2_Open; SolderJumper-2_P1.3mm_Open_RoundedPad1.0x1.5mm
R1, R6: 5.1k; R_0402_1005Metric
R2: 33; R_0402_1005Metric
R3, R10: 10k; R_0402_1005Metric
R4, R5, R7: 1k; R_0402_1005Metric
R8: 16.9k; R_0402_1005Metric
R9: 5k; R_0402_1005Metric
SW1, SW2: SKRPABE010
TP1: TestPoint; TestPoint_THTPad_1.0x1.0mm_Drill0.5mm
U1: MIC39100-3.3WS; SOT-223_S_MCL
U3: STM32G4A1CETx; LQFP-48_7x7mm_P0.5mm
U4: TPS2116DRL; SOT-583-8
X1: SG-310SCF; Oscillator_SMD_SeikoEpson_SG8002CE-4Pin_3.2x2.5mm

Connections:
/ADC1_IN2: J6.2, U3.9 (PA1)
/ADC2_IN1: J6.3, U3.8 (PA0)
/ADC2_IN12: J6.4, U3.18 (PB2)
/ADC2_IN13: J6.5, U3.13 (PA5)
/ADC2_IN17: J6.6, U3.12 (PA4)
/ADC3_IN5: J6.7, U3.27 (PB13)
/BOOT0: JP2.1 (A), R3.2, U3.45 (PB8)
/DN: FB2.1, J4.A7 (DN1), J4.B7 (DN2)
/DP: FB3.1, J4.A6 (DP1), J4.B6 (DP2)
/I2C_SCL: J5.4, U3.31 (PA9)
/I2C_SDA: J5.5, U3.30 (PA8)
/LED0: R5.1, U3.26 (PB12)
/NRST: C13.1, J7.2, SW1.3 (K), SW1.4 (A), U3.7 (PG10)
/PWR: C16.1, C20.1, J9.1, R7.1, R8.2, U4.3 (VIN1), U4.5 (MODE)
/QSPI_CLK: J1.3, U3.11 (PA3)
/QSPI_IO0: J1.4, U3.17 (PB1)
/QSPI_IO1: J1.5, U3.16 (PB0)
/QSPI_IO2: J1.6, U3.15 (PA7)
/QSPI_IO3: J1.7, U3.14 (PA6)
/QSPI_NCS: J1.2, U3.25 (PB11)
/SAI_BCLK: J2.3, U3.40 (PB3)
/SAI_DIN: J2.6, U3.32 (PA10)
/SAI_DOUT: J2.5, U3.42 (PB5)
/SAI_LRCLK: J2.4, U3.43 (PB6)
/SAI_MCLK: J2.2, U3.41 (PB4)
/SPI_MISO: J3.3, U3.28 (PB14)
/SPI_MOSI: J3.4, U3.29 (PB15)
/SPI_SCK: J3.2, U3.6 (PF1)
/SWCLK: J7.4, U3.38 (PA14)
/SWDIO: J7.6, U3.37 (PA13)
/UART_RX: J5.3, U3.39 (PA15)
/UART_TX: J5.2, U3.10 (PA2)
/USB_DM: FB2.2, U3.33 (PA11)
/USB_DP: FB3.2, U3.34 (PA12)
GND: C1.2, C2.2, C3.2, C4.2, C5.2, C6.2, C7.2, C8.2, C9.2, C10.2, C11.2, C12.2, C13.2, C14.1, C15.2, C16.2, C17.2, C18.2, C19.2, C20.2, D1.1 (K), D2.1 (K), D3.1 (K), J1.8, J2.7, J3.5, J4.A1_B12 (GND), J4.B1_A12 (GND), J4.S1 (SHIELD), J4.S2 (SHIELD), J4.S3 (SHIELD), J4.S4 (SHIELD), J5.6, J6.8, J7.1, J7.3, J9.2, R1.2, R3.1, R6.2, R9.1, SW1.1, SW1.2, SW2.1, SW2.2, U1.2 (GND), U1.TAB (GND), U3.19 (VSSA), U3.23 (VSS), U3.35 (VSS), U3.47 (VSS), U4.1 (GND), X1.2 (GND)
unnamed: D1.2 (A), R4.2
unnamed: D2.2 (A), R5.2
unnamed: D3.2 (A), R7.2
unnamed: FB1.1, J4.A4_B9 (VBUS), J4.B4_A9 (VBUS)
unnamed: J4.A5 (CC1), R6.1
unnamed: J4.B5 (CC2), R1.1
unnamed: C17.1, SW2.3 (K), SW2.4 (A), U3.22 (PB10)
unnamed: R2.2, U3.5 (PF0)
unnamed: C11.1, C12.1, FB4.1, U3.21 (VDDA)
unnamed: C18.1, C19.1, FB5.1, U3.20 (VREF+)
unnamed: R8.1, R9.2, U4.4 (PR1)
unnamed: R10.1, TP1.1, U4.8 (ST)
unnamed: R2.1, X1.3 (OUT)
VBUS: FB1.2, R4.1, U4.6 (VIN2)
VCC: C4.1, C5.1, C6.1, C7.1, C8.1, C9.1, C10.1, C14.2, C15.1, FB4.2, FB5.2, J1.1, J2.1, J3.1, J5.1, J6.1, J7.5, JP2.2 (B), U1.3 (OUT), U3.1 (VBAT), U3.24 (VDD), U3.36 (VDD), U3.48 (VDD), X1.4 (Vcc)
VDD: C1.1, C2.1, C3.1, R10.2, U1.1 (VIN), U4.2 (VOUT), U4.7 (VOUT)

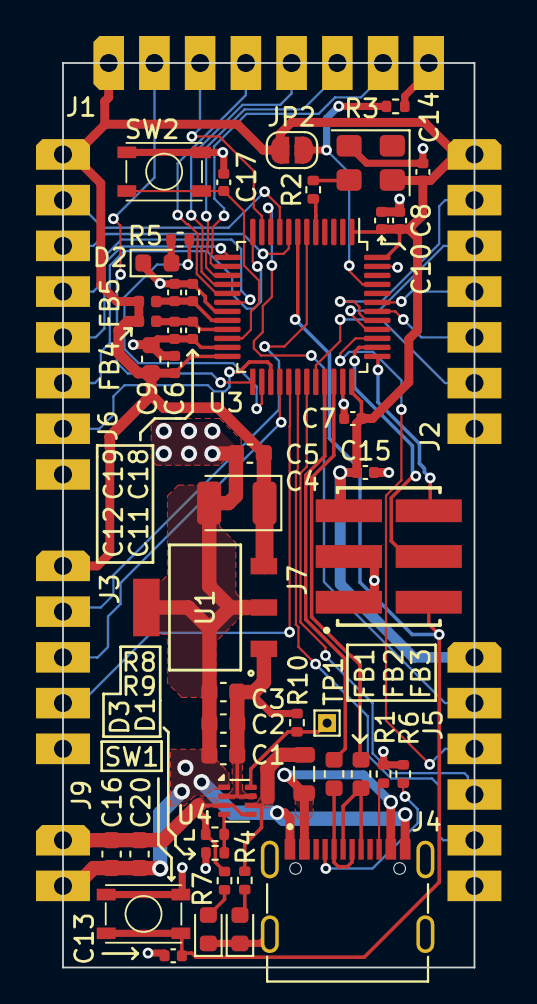
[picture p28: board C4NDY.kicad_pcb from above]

Board: 2 copper layers, 22.9 x 50.2 mm, 54 parts (0 on the bottom side), 51 nets.

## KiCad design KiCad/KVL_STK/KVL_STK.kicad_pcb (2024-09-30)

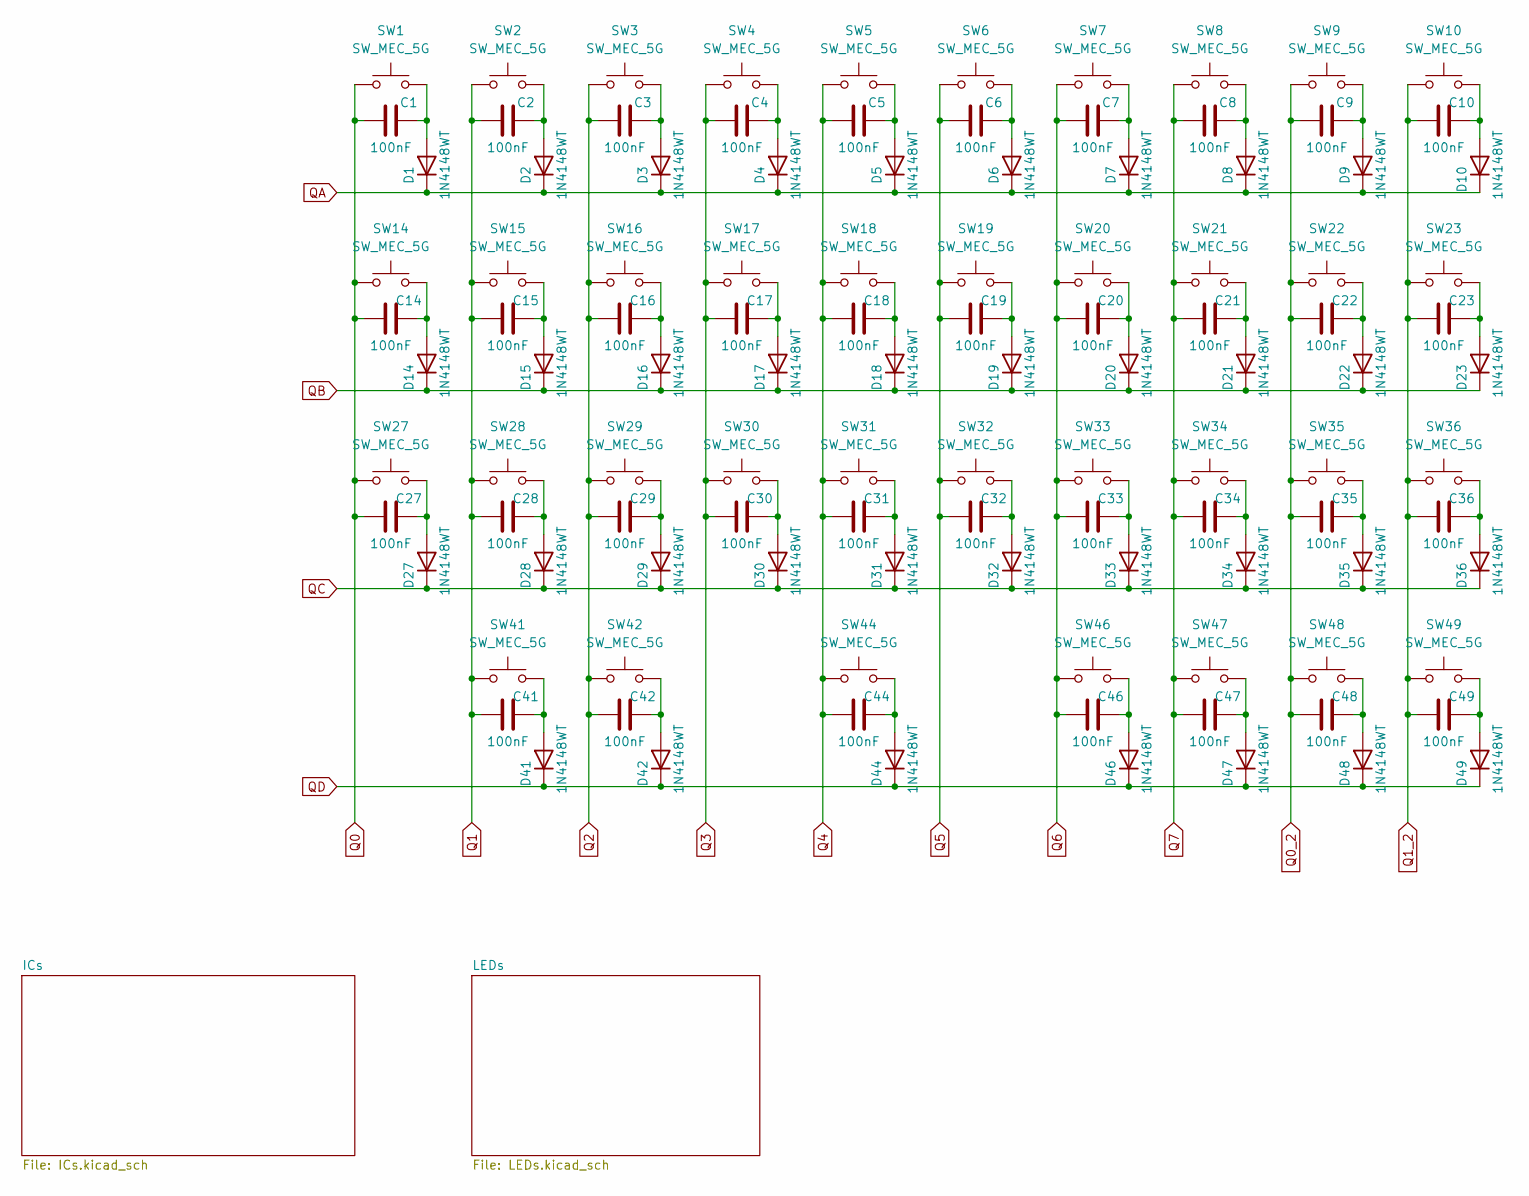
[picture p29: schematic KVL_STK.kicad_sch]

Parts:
C1, C2, C3, C4, C5, C6, C7, C8, C9, C10, C14, C15, C16, C17, C18, C19, C20, C21, C22, C23, C27, C28, C29, C30, C31, C32, C33, C34, C35, C36, C41, C42, C44, C46, C47, C48, C49: 100nF; C_0402_1005Metric
D1, D2, D3, D4, D5, D6, D7, D8, D9, D10, D14, D15, D16, D17, D18, D19, D20, D21, D22, D23, D27, D28, D29, D30, D31, D32, D33, D34, D35, D36, D41, D42, D44, D46, D47, D48, D49: 1N4148WT; D_SOD-523
SW1, SW2, SW3, SW4, SW5, SW6, SW7, SW8, SW9, SW10, SW14, SW15, SW16, SW17, SW18, SW19, SW20, SW21, SW22, SW23, SW27, SW28, SW29, SW30, SW31, SW32, SW33, SW34, SW35, SW36, SW41, SW42, SW44, SW46, SW47, SW48, SW49: SW_MEC_5G; Gateron_KS-27

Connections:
unnamed: C1.2, D1.2 (A), SW1.3 (B)
unnamed: C3.2, D3.2 (A), SW3.3 (B)
unnamed: C4.2, D4.2 (A), SW4.3 (B)
unnamed: C5.2, D5.2 (A), SW5.3 (B)
unnamed: C6.2, D6.2 (A), SW6.3 (B)
unnamed: C7.2, D7.2 (A), SW7.3 (B)
unnamed: C8.2, D8.2 (A), SW8.3 (B)
unnamed: C9.2, D9.2 (A), SW9.3 (B)
unnamed: C10.2, D10.2 (A), SW10.3 (B)
unnamed: C14.2, D14.2 (A), SW14.3 (B)
unnamed: C15.2, D15.2 (A), SW15.3 (B)
unnamed: C16.2, D16.2 (A), SW16.3 (B)
unnamed: C17.2, D17.2 (A), SW17.3 (B)
unnamed: C18.2, D18.2 (A), SW18.3 (B)
unnamed: C19.2, D19.2 (A), SW19.3 (B)
unnamed: C20.2, D20.2 (A), SW20.3 (B)
unnamed: C21.2, D21.2 (A), SW21.3 (B)
unnamed: C22.2, D22.2 (A), SW22.3 (B)
unnamed: C23.2, D23.2 (A), SW23.3 (B)
unnamed: C27.2, D27.2 (A), SW27.3 (B)
unnamed: C28.2, D28.2 (A), SW28.3 (B)
unnamed: C29.2, D29.2 (A), SW29.3 (B)
unnamed: C30.2, D30.2 (A), SW30.3 (B)
unnamed: C31.2, D31.2 (A), SW31.3 (B)
unnamed: C32.2, D32.2 (A), SW32.3 (B)
unnamed: C33.2, D33.2 (A), SW33.3 (B)
unnamed: C34.2, D34.2 (A), SW34.3 (B)
unnamed: C35.2, D35.2 (A), SW35.3 (B)
unnamed: C36.2, D36.2 (A), SW36.3 (B)
unnamed: C41.2, D41.2 (A), SW41.3 (B)
unnamed: C42.2, D42.2 (A), SW42.3 (B)
unnamed: C44.2, D44.2 (A), SW44.3 (B)
unnamed: C46.2, D46.2 (A), SW46.3 (B)
unnamed: C47.2, D47.2 (A), SW47.3 (B)
unnamed: C48.2, D48.2 (A), SW48.3 (B)
unnamed: C49.2, D49.2 (A), SW49.3 (B)
Q0: C1.1, C14.1, C27.1, SW1.1 (A), SW14.1 (A), SW27.1 (A); also elsewhere on the board
Q0_2: C9.1, C22.1, C35.1, C48.1, SW9.1 (A), SW22.1 (A), SW35.1 (A), SW48.1 (A); also elsewhere on the board
Q1: C2.1, C15.1, C28.1, C41.1, SW2.1 (A), SW15.1 (A), SW28.1 (A), SW41.1 (A); also elsewhere on the board
Q1_2: C10.1, C23.1, C36.1, C49.1, SW10.1 (A), SW23.1 (A), SW36.1 (A), SW49.1 (A); also elsewhere on the board
Q2: C3.1, C16.1, C29.1, C42.1, SW3.1 (A), SW16.1 (A), SW29.1 (A), SW42.1 (A); also elsewhere on the board
Q3: C4.1, C17.1, C30.1, SW4.1 (A), SW17.1 (A), SW30.1 (A); also elsewhere on the board
Q4: C5.1, C18.1, C31.1, C44.1, SW5.1 (A), SW18.1 (A), SW31.1 (A), SW44.1 (A); also elsewhere on the board
Q5: C6.1, C19.1, C32.1, SW6.1 (A), SW19.1 (A), SW32.1 (A); also elsewhere on the board
Q6: C7.1, C20.1, C33.1, C46.1, SW7.1 (A), SW20.1 (A), SW33.1 (A), SW46.1 (A); also elsewhere on the board
Q7: C8.1, C21.1, C34.1, C47.1, SW8.1 (A), SW21.1 (A), SW34.1 (A), SW47.1 (A); also elsewhere on the board
QB: D14.1 (K), D15.1 (K), D16.1 (K), D17.1 (K), D18.1 (K), D19.1 (K), D20.1 (K), D21.1 (K), D22.1 (K), D23.1 (K); also elsewhere on the board
QC: D27.1 (K), D28.1 (K), D29.1 (K), D30.1 (K), D31.1 (K), D32.1 (K), D33.1 (K), D34.1 (K), D35.1 (K), D36.1 (K); also elsewhere on the board
QD: D41.1 (K), D42.1 (K), D44.1 (K), D46.1 (K), D47.1 (K), D48.1 (K), D49.1 (K); also elsewhere on the board

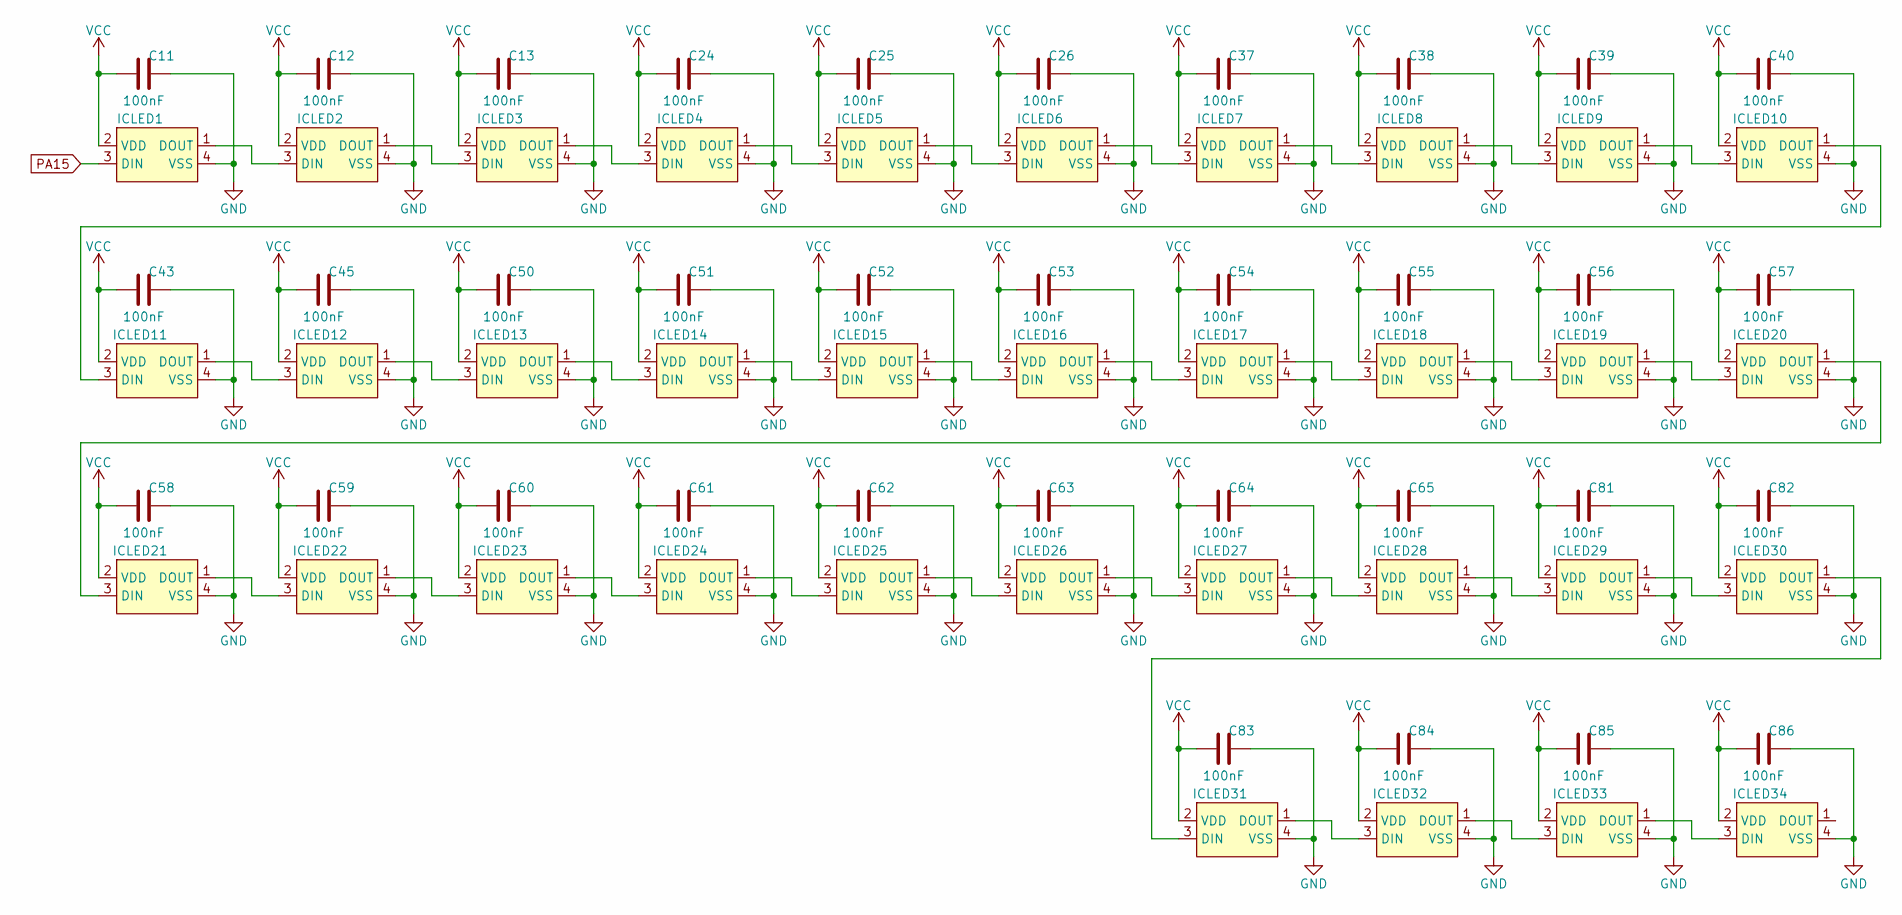
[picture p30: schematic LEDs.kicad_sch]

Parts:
C11, C12, C13, C24, C25, C26, C37, C38, C39, C40, C43, C45, C50, C51, C52, C53, C54, C55, C56, C57, C58, C59, C60, C61, C62, C63, C64, C65, C81, C82, C83, C84, C85, C86: 100nF; C_0402_1005Metric
ICLED1, ICLED2, ICLED3, ICLED4, ICLED5, ICLED6, ICLED7, ICLED8, ICLED9, ICLED10, ICLED11, ICLED12, ICLED13, ICLED14, ICLED15, ICLED16, ICLED17, ICLED18, ICLED19, ICLED20, ICLED21, ICLED22, ICLED23, ICLED24, ICLED25, ICLED26, ICLED27, ICLED28, ICLED29, ICLED30, ICLED31, ICLED32, ICLED33, ICLED34: 1312020030000

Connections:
unnamed: ICLED1.1 (DOUT), ICLED2.3 (DIN)
unnamed: ICLED2.1 (DOUT), ICLED3.3 (DIN)
unnamed: ICLED3.1 (DOUT), ICLED4.3 (DIN)
unnamed: ICLED4.1 (DOUT), ICLED5.3 (DIN)
unnamed: ICLED5.1 (DOUT), ICLED6.3 (DIN)
unnamed: ICLED6.1 (DOUT), ICLED7.3 (DIN)
unnamed: ICLED7.1 (DOUT), ICLED8.3 (DIN)
unnamed: ICLED8.1 (DOUT), ICLED9.3 (DIN)
unnamed: ICLED9.1 (DOUT), ICLED10.3 (DIN)
unnamed: ICLED10.1 (DOUT), ICLED11.3 (DIN)
unnamed: ICLED11.1 (DOUT), ICLED12.3 (DIN)
unnamed: ICLED12.1 (DOUT), ICLED13.3 (DIN)
unnamed: ICLED13.1 (DOUT), ICLED14.3 (DIN)
unnamed: ICLED14.1 (DOUT), ICLED15.3 (DIN)
unnamed: ICLED15.1 (DOUT), ICLED16.3 (DIN)
unnamed: ICLED16.1 (DOUT), ICLED17.3 (DIN)
unnamed: ICLED17.1 (DOUT), ICLED18.3 (DIN)
unnamed: ICLED18.1 (DOUT), ICLED19.3 (DIN)
unnamed: ICLED19.1 (DOUT), ICLED20.3 (DIN)
unnamed: ICLED20.1 (DOUT), ICLED21.3 (DIN)
unnamed: ICLED21.1 (DOUT), ICLED22.3 (DIN)
unnamed: ICLED22.1 (DOUT), ICLED23.3 (DIN)
unnamed: ICLED23.1 (DOUT), ICLED24.3 (DIN)
unnamed: ICLED24.1 (DOUT), ICLED25.3 (DIN)
unnamed: ICLED25.1 (DOUT), ICLED26.3 (DIN)
unnamed: ICLED26.1 (DOUT), ICLED27.3 (DIN)
unnamed: ICLED27.1 (DOUT), ICLED28.3 (DIN)
unnamed: ICLED28.1 (DOUT), ICLED29.3 (DIN)
unnamed: ICLED29.1 (DOUT), ICLED30.3 (DIN)
unnamed: ICLED30.1 (DOUT), ICLED31.3 (DIN)
unnamed: ICLED31.1 (DOUT), ICLED32.3 (DIN)
unnamed: ICLED32.1 (DOUT), ICLED33.3 (DIN)
unnamed: ICLED33.1 (DOUT), ICLED34.3 (DIN)
PA15: ICLED1.3 (DIN); also elsewhere on the board
VCC: C11.1, C12.1, C13.1, C24.1, C25.1, C26.1, C37.1, C38.1, C39.1, C40.1, C43.1, C45.1, C50.1, C51.1, C52.1, C53.1, C54.1, C55.1, C56.1, C57.1, C58.1, C59.1, C60.1, C61.1, C62.1, C63.1, C64.1, C65.1, C81.1, C82.1, C83.1, C84.1, C85.1, C86.1, ICLED1.2 (VDD), ICLED2.2 (VDD), ICLED3.2 (VDD), ICLED4.2 (VDD), ICLED5.2 (VDD), ICLED6.2 (VDD), ICLED7.2 (VDD), ICLED8.2 (VDD), ICLED9.2 (VDD), ICLED10.2 (VDD), ICLED11.2 (VDD), ICLED12.2 (VDD), ICLED13.2 (VDD), ICLED14.2 (VDD), ICLED15.2 (VDD), ICLED16.2 (VDD), ICLED17.2 (VDD), ICLED18.2 (VDD), ICLED19.2 (VDD), ICLED20.2 (VDD), ICLED21.2 (VDD), ICLED22.2 (VDD), ICLED23.2 (VDD), ICLED24.2 (VDD), ICLED25.2 (VDD), ICLED26.2 (VDD), ICLED27.2 (VDD), ICLED28.2 (VDD), ICLED29.2 (VDD), ICLED30.2 (VDD), ICLED31.2 (VDD), ICLED32.2 (VDD), ICLED33.2 (VDD), ICLED34.2 (VDD); also elsewhere on the board

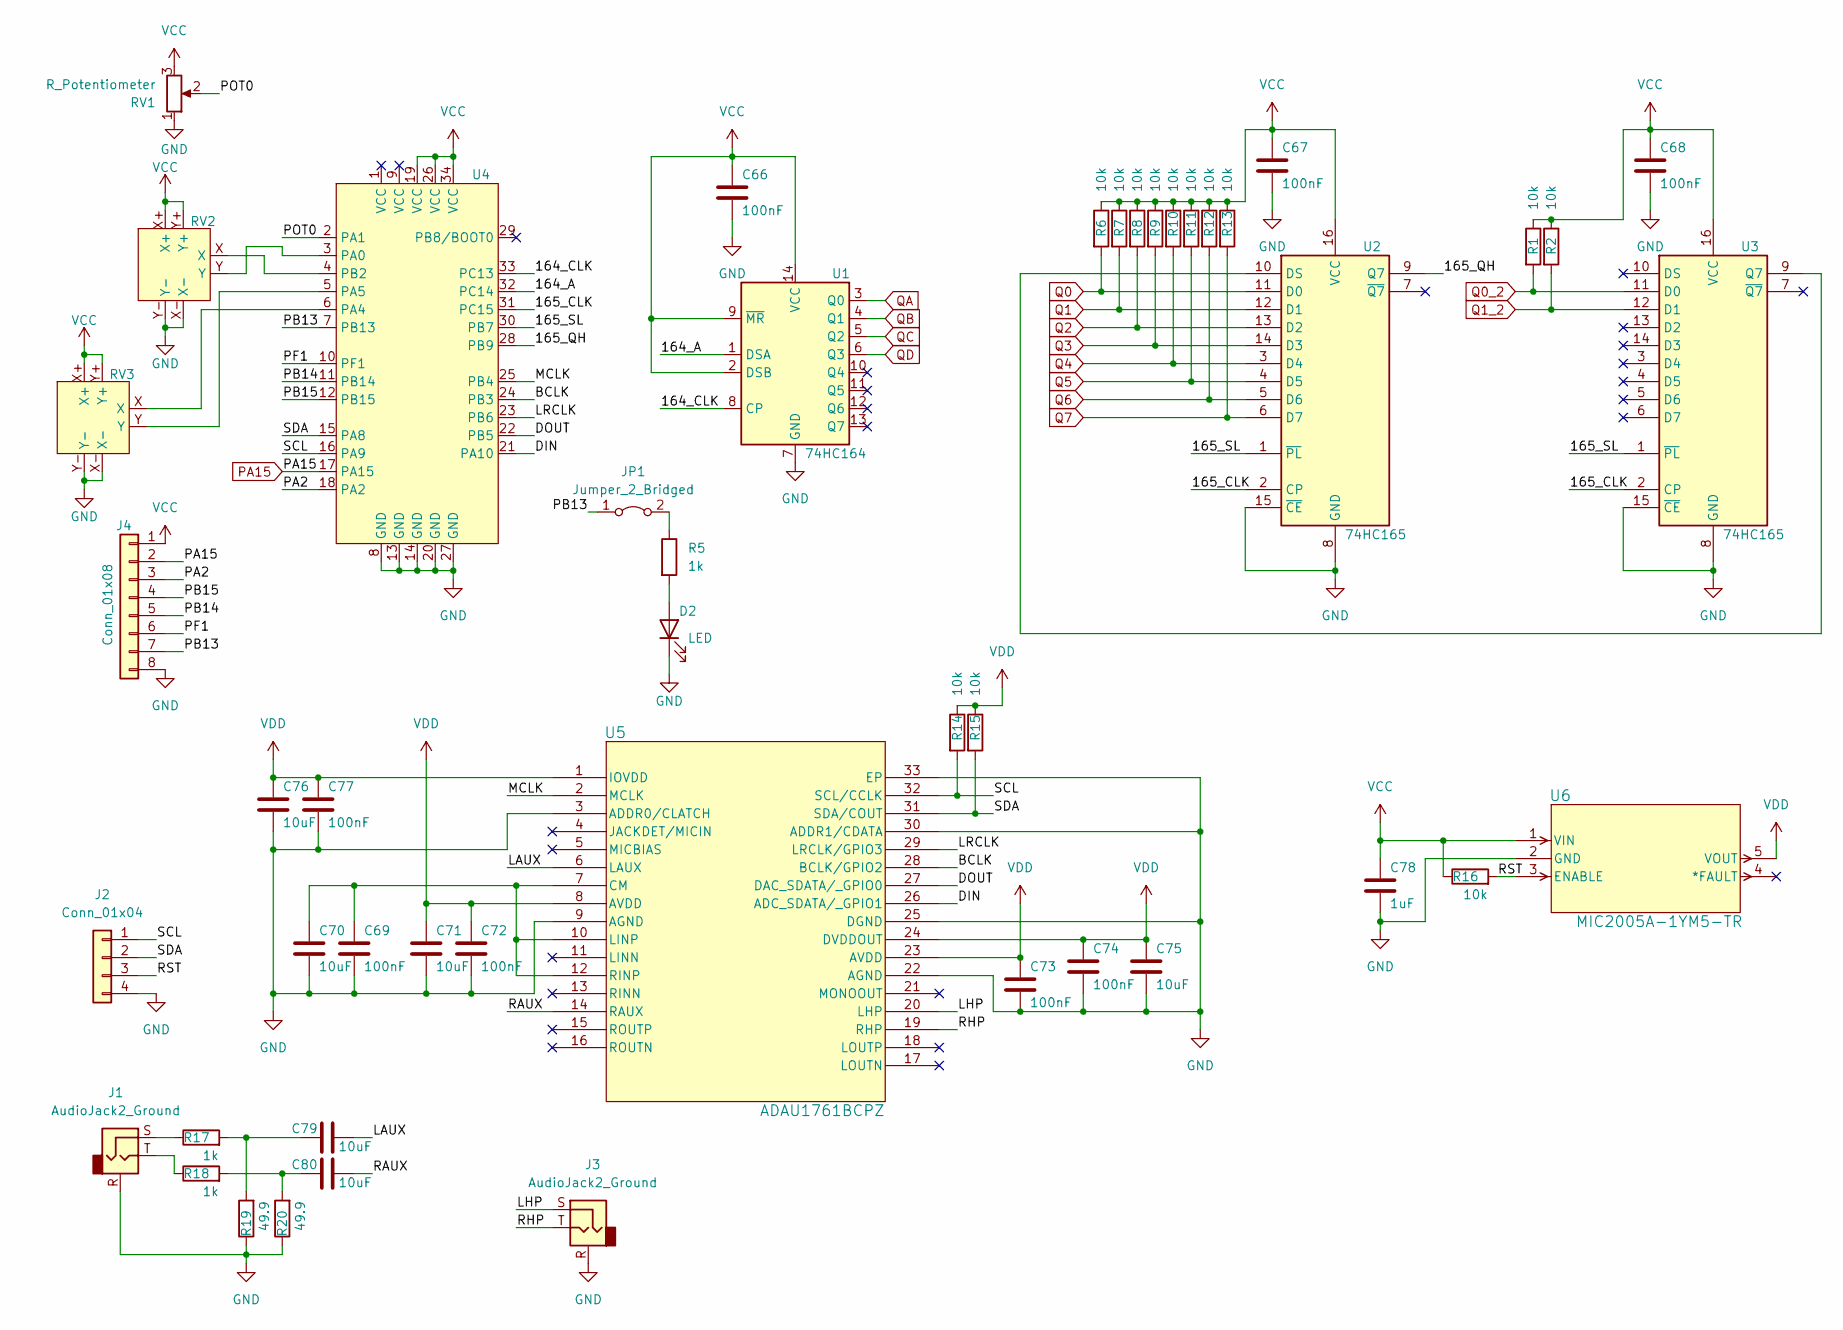
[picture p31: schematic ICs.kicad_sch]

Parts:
C66, C67, C68, C69, C72, C73, C74, C77: 100nF; C_0402_1005Metric
C70, C71, C75, C76, C79, C80: 10uF; C_0603_1608Metric
C78: 1uF; C_0603_1608Metric
D2: LED; LED_0603_1608Metric
J1, J3: AudioJack2_Ground; Jack_3.5mm_QingPu_WQP-PJ366ST_Vertical
J2: Conn_01x04; PinHeader_1x04_P2.54mm_Vertical
J4: Conn_01x08; PinHeader_1x08_P2.54mm_Vertical
JP1: Jumper_2_Bridged; SolderJumper-2_P1.3mm_Bridged_RoundedPad1.0x1.5mm
R1, R2, R6, R7, R8, R9, R10, R11, R12, R13, R14, R15, R16: 10k; R_0402_1005Metric
R5, R17, R18: 1k; R_0402_1005Metric
R19, R20: 49.9; R_0402_1005Metric
RV1: R_Potentiometer; RK09K1130A5R
RV2, RV3: ADA-2765
U1: 74HC164; SOIC-14_3.9x8.7mm_P1.27mm
U2, U3: 74HC165; SOIC-16_3.9x9.9mm_P1.27mm
U4: C4NDY_BOARD
U5: ADAU1761BCPZ; CP_32_4_ADI
U6: MIC2005A-1YM5-TR; SOT-23-5_M5_MCH

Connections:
/ICs/164_A: U1.1 (DSA), U4.32 (PC14)
/ICs/164_CLK: U1.8 (CP), U4.33 (PC13)
/ICs/165_CLK: U2.2 (CP), U3.2 (CP), U4.31 (PC15)
/ICs/165_QH: U2.9 (Q7), U4.28 (PB9)
/ICs/165_SL: U2.1 (~PL), U3.1 (~PL), U4.30 (PB7)
/ICs/BCLK: U4.24 (PB3), U5.28 (BCLK/GPIO2)
/ICs/DIN: U4.21 (PA10), U5.26 (ADC_SDATA/_GPIO1)
/ICs/DOUT: U4.22 (PB5), U5.27 (DAC_SDATA/_GPIO0)
/ICs/LAUX: C79.2, U5.6 (LAUX)
/ICs/LHP: J3.S, U5.20 (LHP)
/ICs/LRCLK: U4.23 (PB6), U5.29 (LRCLK/GPIO3)
/ICs/MCLK: U4.25 (PB4), U5.2 (MCLK)
/ICs/PA2: J4.3, U4.18 (PA2)
/ICs/PB13: J4.7, JP1.1 (A), U4.7 (PB13)
/ICs/PB14: J4.5, U4.11 (PB14)
/ICs/PB15: J4.4, U4.12 (PB15)
/ICs/PF1: J4.6, U4.10 (PF1)
/ICs/POT0: RV1.2, U4.2 (PA1)
/ICs/RAUX: C80.2, U5.14 (RAUX)
/ICs/RHP: J3.T, U5.19 (RHP)
/ICs/RST: J2.3, R16.2, U6.3 (ENABLE)
/ICs/SCL: J2.1, R14.2, U4.16 (PA9), U5.32 (SCL/CCLK)
/ICs/SDA: J2.2, R15.2, U4.15 (PA8), U5.31 (SDA/COUT)
unnamed: C79.1, R17.2, R19.2
unnamed: C80.1, R18.2, R20.2
unnamed: J1.S, R17.1
unnamed: J1.T, R18.1
unnamed 96: JP1.2 (B); also elsewhere on the board
unnamed: U2.10 (DS), U3.9 (Q7)
unnamed: RV2.Y, U4.3 (PA0)
unnamed: RV3.X, U4.6 (PA4)
unnamed: RV3.Y, U4.5 (PA5)
unnamed: RV2.X, U4.4 (PB2)
unnamed: C69.1, C70.1, U5.7 (CM), U5.10 (LINP), U5.12 (RINP)
PA15: J4.2, U4.17 (PA15); also elsewhere on the board
Q0: R6.2, U2.11 (D0); also elsewhere on the board
Q0_2: R1.2, U3.11 (D0); also elsewhere on the board
Q1: R7.2, U2.12 (D1); also elsewhere on the board
Q1_2: R2.2, U3.12 (D1); also elsewhere on the board
Q2: R8.2, U2.13 (D2); also elsewhere on the board
Q3: R9.2, U2.14 (D3); also elsewhere on the board
Q4: R10.2, U2.3 (D4); also elsewhere on the board
Q5: R11.2, U2.4 (D5); also elsewhere on the board
Q6: R12.2, U2.5 (D6); also elsewhere on the board
Q7: R13.2, U2.6 (D7); also elsewhere on the board
QB: U1.4 (Q1); also elsewhere on the board
QC: U1.5 (Q2); also elsewhere on the board
QD: U1.6 (Q3); also elsewhere on the board
VCC: C66.1, C67.1, C68.1, C78.1, J4.1, R1.1, R2.1, R6.1, R7.1, R8.1, R9.1, R10.1, R11.1, R12.1, R13.1, R16.1, RV1.3, RV2.X+, RV2.Y+, RV3.X+, RV3.Y+, U1.2 (DSB), U1.9 (~MR), U1.14 (VCC), U2.16 (VCC), U3.16 (VCC), U4.19 (VCC), U4.26 (VCC), U4.34 (VCC), U6.1 (VIN); also elsewhere on the board
VDD: C71.1, C72.1, C73.1, C74.1, C75.1, C76.1, C77.1, R14.1, R15.1, U5.1 (IOVDD), U5.8 (AVDD), U5.23 (AVDD), U5.24 (DVDDOUT), U6.5 (VOUT)

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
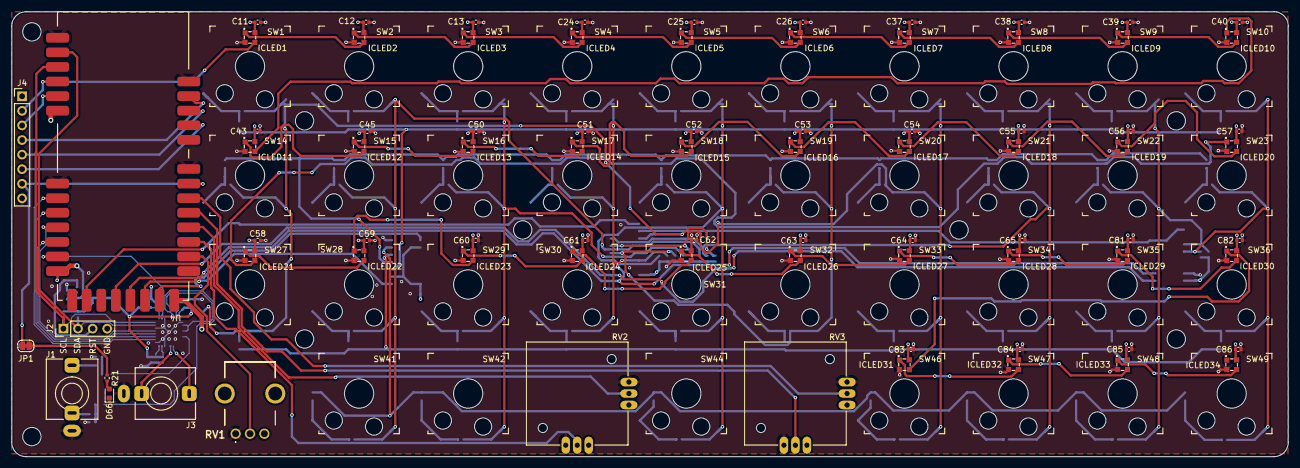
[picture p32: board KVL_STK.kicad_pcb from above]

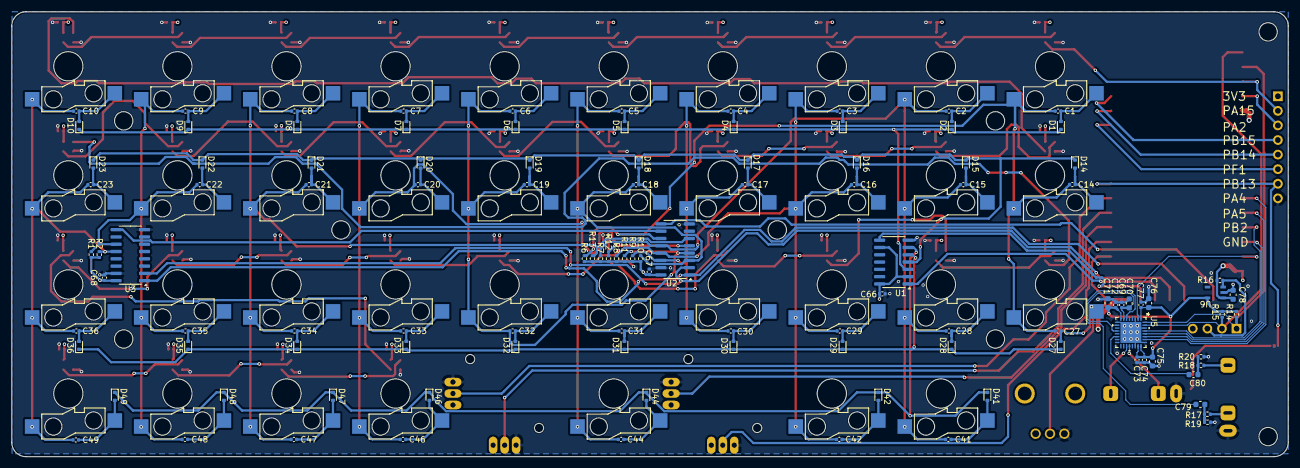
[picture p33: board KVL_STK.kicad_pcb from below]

Board: 4 copper layers, 222.3 x 77.5 mm, 235 parts (148 on the bottom side), 123 nets.

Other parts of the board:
D66: LED; LED_0603_1608Metric
MH1, MH2, MH4, MH4#2, MH5, MH6, MH7, MH8: MountingHole_3.2mm_M3
R21: 1k; R_0402_1005Metric

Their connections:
unnamed 96: R21.1; also elsewhere on the board

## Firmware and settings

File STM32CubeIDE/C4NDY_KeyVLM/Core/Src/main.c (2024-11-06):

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
/* Includes ------------------------------------------------------------------*/
#include "main.h"
#include "adc.h"
#include "dma.h"
#include "i2c.h"
#include "quadspi.h"
#include "sai.h"
#include "tim.h"
#include "usb.h"
#include "gpio.h"

/* USER CODE BEGIN Includes */
#include <stdbool.h>
#include <stdlib.h>
#include <math.h>

#include "usb_descriptors.h"

#include "keyboard.h"
#include "audio_control.h"
/* USER CODE END Includes */

/* USER CODE BEGIN PD */
#define FLASH_DATA_ADDR 0x0807F000

#define AUDIO_SAMPLE_RATE 48000

/* USER CODE END PD */


void SystemClock_Config(void);
/* USER CODE BEGIN 0 */

//--------------------------------------------------------------------+
// Application Callback API Implementations
//--------------------------------------------------------------------+
// Invoked when device is mounted
void tud_mount_cb(void)
{
    // blink_interval_ms = BLINK_MOUNTED;
}

// Invoked when device is unmounted
void tud_umount_cb(void)
{
    // blink_interval_ms = BLINK_NOT_MOUNTED;
}

// Invoked when usb bus is suspended
// remote_wakeup_en : if host allow us  to perform remote wakeup
// Within 7ms, device must draw an average of current less than 2.5 mA from bus
void tud_suspend_cb(bool remote_wakeup_en)
{
    (void) remote_wakeup_en;
    // blink_interval_ms = BLINK_SUSPENDED;
}

// Invoked when usb bus is resumed
void tud_resume_cb(void)
{
    // blink_interval_ms = BLINK_MOUNTED;
}

void HAL_TIM_PeriodElapsedCallback(TIM_HandleTypeDef* htim)
{
    if (htim == &htim6)
    {
    }
}

void erase_flash_data(void)
{
    static FLASH_EraseInitTypeDef EraseInitStruct;
    uint32_t PAGEError;
    EraseInitStruct.TypeErase = FLASH_TYPEERASE_PAGES;
    EraseInitStruct.Page      = 254;
    EraseInitStruct.NbPages   = 2;

    if (HAL_FLASHEx_Erase(&EraseInitStruct, &PAGEError) != HAL_OK)
    {
        SEGGER_RTT_printf(0, "flash erase error...\n");
    }
}

void write_flash_data(uint16_t index, uint8_t val)
{
    if (HAL_FLASH_Program(FLASH_TYPEPROGRAM_DOUBLEWORD, FLASH_DATA_ADDR + 8 * index, val) != HAL_OK)
    {
        SEGGER_RTT_printf(0, "flash program error...\n");
    }
}

uint64_t read_flash_data(uint16_t index)
{
    return *(uint64_t*) (FLASH_DATA_ADDR + 8 * index);
}

void setBootDfuFlag(bool is_boot_dfu)
{
    SEGGER_RTT_printf(0, "erase & write FLASH...\n");
    HAL_FLASH_Unlock();

    uint64_t currentKeyMap[2][MATRIX_ROWS][MATRIX_COLUMNS] = {0x0};

    SEGGER_RTT_printf(0, "current KeyMap\n");
    for (int k = 0; k < 2; k++)
    {
        SEGGER_RTT_printf(0, "Layout:%d\n", k + 1);
        SEGGER_RTT_printf(0, "[\n");
        for (int i = 0; i < MATRIX_ROWS; i++)
        {
            SEGGER_RTT_printf(0, "[");
            for (int j = 0; j < MATRIX_COLUMNS; j++)
            {
                currentKeyMap[k][i][j] = read_flash_data(BASIC_PARAMS_NUM + k * (MATRIX_ROWS * MATRIX_COLUMNS) + i * MATRIX_COLUMNS + j);
                SEGGER_RTT_printf(0, "%02X ", currentKeyMap[k][i][j]);
            }
            SEGGER_RTT_printf(0, "]\n");
        }
        SEGGER_RTT_printf(0, "]\n\n");
    }

    erase_flash_data();

    if (is_boot_dfu)
    {
        write_flash_data(0, 1);
    }
    else
    {
        write_flash_data(0, 0);
    }
    write_flash_data(1, getLinePhonoSW());
    write_flash_data(2, getKeymapID());

    SEGGER_RTT_printf(0, "reload KeyMap\n");
    for (int k = 0; k < 2; k++)
    {
        SEGGER_RTT_printf(0, "Layout:%d\n", k + 1);
        SEGGER_RTT_printf(0, "[\n");
        for (int i = 0; i < MATRIX_ROWS; i++)
        {
            SEGGER_RTT_printf(0, "[");
            for (int j = 0; j < MATRIX_COLUMNS; j++)
            {
                write_flash_data(BASIC_PARAMS_NUM + k * (MATRIX_ROWS * MATRIX_COLUMNS) + i * MATRIX_COLUMNS + j, currentKeyMap[k][i][j]);
                SEGGER_RTT_printf(0, "%02X ", currentKeyMap[k][i][j]);
            }
            SEGGER_RTT_printf(0, "]\n");
        }
        SEGGER_RTT_printf(0, "]\n\n");
    }

    HAL_FLASH_Lock();
}
/* USER CODE END 0 */

/**
 * @brief  The application entry point.
 * @retval int
 */
int main(void)
{

    /* MCU Configuration--------------------------------------------------------*/

    /* Reset of all peripherals, Initializes the Flash interface and the Systick. */
    HAL_Init();

    /* Configure the system clock */
    SystemClock_Config();

    /* Initialize all configured peripherals */
    MX_GPIO_Init();
    MX_DMA_Init();
    MX_SAI1_Init();
    MX_QUADSPI1_Init();
    MX_I2C2_Init();
    MX_ADC1_Init();
    MX_USB_PCD_Init();
    MX_TIM6_Init();
    /* USER CODE BEGIN 2 */
    HAL_GPIO_WritePin(USER_LED_GPIO_Port, USER_LED_Pin, GPIO_PIN_SET);

    SEGGER_RTT_printf(0, "Unique Device ID = %X-%X-%X\n", HAL_GetUIDw0(), HAL_GetUIDw1(), HAL_GetUIDw2());

    SEGGER_RTT_printf(0, "initialize ADAU1761...\n");
    default_download_IC_1();

    SEGGER_RTT_printf(0, "initialize tinyUSB...\n");
    tusb_init();

    SEGGER_RTT_printf(0, "start ADC DMA...\n");
    start_adc();

    SEGGER_RTT_printf(0, "start SAI DMA...\n");
    start_sai();

    // HAL_TIM_Base_Start_IT(&htim6);

    SEGGER_RTT_printf(0, "user_sw = %d\n", HAL_GPIO_ReadPin(USER_SW_GPIO_Port, USER_SW_Pin));
    if (!HAL_GPIO_ReadPin(USER_SW_GPIO_Port, USER_SW_Pin))
    {
        SEGGER_RTT_printf(0, "init flash data");

        factoryReset();
    }

    loadKeyboardSettingsFromFlash();
    /* USER CODE END 2 */

    /* Infinite loop */
    /* USER CODE BEGIN WHILE */
    while (1)
    {
        tud_task();

        read_audio_data_from_usb(N_SAMPLES_PER_1_RX * CFG_TUD_AUDIO_FUNC_1_N_BYTES_PER_SAMPLE_RX * CFG_TUD_AUDIO_FUNC_1_N_CHANNELS_RX);

        codec_control_task();

        hid_keyscan_task();

        /* USER CODE END WHILE */

        /* USER CODE BEGIN 3 */
    }
    /* USER CODE END 3 */
}

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


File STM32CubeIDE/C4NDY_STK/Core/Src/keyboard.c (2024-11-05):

/*
 * keyboard.c
 *
 *  Created on: Aug 17, 2023
 *      Author: shun
 */

#include "keyboard.h"

#include "audio_control.h"
#include "adc.h"
#include "icled.h"

#include <math.h>

struct keyboardHID_t
{
    uint8_t modifiers;
    uint8_t reserved;
    uint8_t key[6];
} keyboardHID;

struct mouseHID_t
{
    int8_t x;
    int8_t y;
    uint8_t buttons;
    int8_t vertical;
    int8_t horizontal;
    int8_t vertical_prev;
} mouseHID;

uint16_t keyState[MATRIX_ROWS]     = {0x0};
uint16_t prevKeyState[MATRIX_ROWS] = {0x0};

bool isSwitchDFUMode      = false;
uint32_t longPressCounter = 0;

bool isKeymapIDChanged = false;
uint8_t keymapID       = 0;

bool isLinePhonoSWChanged = false;
uint8_t linePhonoSW       = 0;

bool isMasterGainChanged = false;

bool isUpper   = false;
bool isShift   = false;
bool isControl = false;
bool isAlt     = false;
bool isGui     = false;

bool isClicked       = false;
bool isWheel         = false;
bool isXFadeCut      = false;
bool isStickReturned = false;

int offset_calibrate_count[JOYSTICK_NUMS] = {0};
double x_offset[JOYSTICK_NUMS]            = {0.0};
double y_offset[JOYSTICK_NUMS]            = {0.0};

uint16_t countReturnNeutral = 0;
#define MAX_COUNT_RETURN_NEUTRAL 600

int8_t currentStk[JOYSTICK_NUMS][JOYSTICK_AXIS] = {0};
int8_t prevStk[JOYSTICK_NUMS][JOYSTICK_AXIS]    = {0};

// clang-format off
const uint8_t keymaps_normal_default[2][MATRIX_ROWS][MATRIX_COLUMNS][2] = {
    {
        {{KC_Q, M_NO},    {KC_W, M_NO},    {KC_E, M_NO},    {KC_R, M_NO},    {KC_T, M_NO},        {KC_Y, M_NO},    {KC_U, M_NO},    {KC_I, M_NO},     {KC_O, M_NO},      {KC_P, M_NO}},
        {{KC_A, M_NO},    {KC_S, M_NO},    {KC_D, M_NO},    {KC_F, M_NO},    {KC_G, M_NO},        {KC_H, M_NO},    {KC_J, M_NO},    {KC_K, M_NO},     {KC_L, M_NO},      {KC_SC, M_NO}},
        {{KC_Z, M_NO},    {KC_X, M_NO},    {KC_C, M_NO},    {KC_V, M_NO},    {KC_B, M_NO},        {KC_N, M_NO},    {KC_M, M_NO},    {KC_COMMA, M_NO}, {KC_PERIOD, M_NO}, {KC_SLASH, M_NO}},
        {{KC_NULL, M_NO}, {KC_LGUI, M_NO}, {KC_LALT, M_NO}, {KC_NULL, M_NO}, {KC_LCONTROL, M_NO}, {KC_NULL, M_NO}, {KC_LEFT, M_NO}, {KC_DOWN, M_NO},  {KC_UP, M_NO},     {KC_RIGHT, M_NO}}
    },
    {
        {{KC_APS, M_NO},  {KC_COMMA, M_NO}, {KC_O, M_NO},    {KC_U, M_NO},    {KC_Y, M_NO},        {KC_F, M_NO},    {KC_G, M_NO},    {KC_C, M_NO},    {KC_R, M_NO},  {KC_L, M_NO}},
        {{KC_P, M_NO},    {KC_I, M_NO},     {KC_E, M_NO},    {KC_A, M_NO},    {KC_PERIOD, M_NO},   {KC_D, M_NO},    {KC_S, M_NO},    {KC_T, M_NO},    {KC_H, M_NO},  {KC_Z, M_NO}},
        {{KC_J, M_NO},    {KC_Q, M_NO},     {KC_SC, M_NO},   {KC_K, M_NO},    {KC_X, M_NO},        {KC_B, M_NO},    {KC_M, M_NO},    {KC_W, M_NO},    {KC_N, M_NO},  {KC_V, M_NO}},
        {{KC_NULL, M_NO}, {KC_LGUI, M_NO},  {KC_LALT, M_NO}, {KC_NULL, M_NO}, {KC_LCONTROL, M_NO}, {KC_NULL, M_NO}, {KC_LEFT, M_NO}, {KC_DOWN, M_NO}, {KC_UP, M_NO}, {KC_RIGHT, M_NO}}
    }
};

const uint8_t keymaps_upper_default[2][MATRIX_ROWS][MATRIX_COLUMNS][2] = {
    {
        {{KC_1, M_NO},    {KC_2, M_NO},        {KC_3, M_NO},      {KC_4, M_NO},      {KC_5, M_NO},        {KC_6, M_NO},    {KC_7, M_NO},    {KC_8, M_NO},          {KC_9, M_NO},        {KC_0, M_NO}},
        {{KC_APS, M_NO},  {KC_GA, M_NO},       {KC_NULL, M_NO},   {KC_LGUI, M_NO},   {KC_NULL, M_NO},     {KC_NULL, M_NO}, {KC_LSB, M_NO},  {KC_RSB, M_NO},        {KC_MINUS, M_NO},    {KC_EQUAL, M_NO}},
        {{KC_NULL, M_NO}, {KC_CAPSLOCK, M_NO}, {KC_M_LBTN, M_NO}, {KC_M_RBTN, M_NO}, {KC_M_WHEEL, M_NO},  {KC_NULL, M_NO}, {KC_NULL, M_NO}, {KC_COMMA, M_NO},      {KC_PERIOD, M_NO},   {KC_BSLASH, M_NO}},
        {{KC_NULL, M_NO}, {KC_LNPH, M_NO},     {KC_LAYOUT, M_NO}, {KC_NULL, M_NO},   {KC_LCONTROL, M_NO}, {KC_NULL, M_NO}, {KC_NULL, M_NO}, {KC_MGAIN_DOWN, M_NO}, {KC_MGAIN_UP, M_NO}, {KC_RESET, M_NO}}
    },
    {
        {{KC_1, M_NO},    {KC_2, M_NO},        {KC_3, M_NO},      {KC_4, M_NO},      {KC_5, M_NO},        {KC_6, M_NO},    {KC_7, M_NO},     {KC_8, M_NO},          {KC_9, M_NO},        {KC_0, M_NO}},
        {{KC_APS, M_NO},  {KC_COMMA, M_NO},    {KC_NULL, M_NO},   {KC_LGUI, M_NO},   {KC_PERIOD, M_NO},   {KC_NULL, M_NO}, {KC_LSB, M_NO},   {KC_RSB, M_NO},        {KC_SLASH, M_NO},    {KC_MINUS, M_NO}},
        {{KC_NULL, M_NO}, {KC_CAPSLOCK, M_NO}, {KC_M_LBTN, M_NO}, {KC_M_RBTN, M_NO}, {KC_M_WHEEL, M_NO},  {KC_NULL, M_NO}, {KC_EQUAL, M_NO}, {KC_NULL, M_NO},       {KC_NULL, M_NO},     {KC_BSLASH, M_NO}},
        {{KC_NULL, M_NO}, {KC_LNPH, M_NO},     {KC_LAYOUT, M_NO}, {KC_NULL, M_NO},   {KC_LCONTROL, M_NO}, {KC_NULL, M_NO}, {KC_NULL, M_NO},  {KC_MGAIN_DOWN, M_NO}, {KC_MGAIN_UP, M_NO}, {KC_RESET, M_NO}}
    }
};
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

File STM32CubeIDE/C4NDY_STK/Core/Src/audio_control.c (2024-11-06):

/*
 * audio_control.c
 *
 *  Created on: Aug 17, 2023
 *      Author: shun
 */

#include <math.h>

#include "adc.h"
#include "sai.h"

#include "audio_control.h"

#include "ADAU1761_IC_1_PARAM.h"
#include "ADAU1761_IC_1_REG.h"
#include "ADAU1761_IC_1.h"
#include "SigmaStudioFW.h"

#include <icled.h>
#include <keyboard.h>

// List of supported sample rates
const uint32_t sample_rates[] = {48000};
uint32_t current_sample_rate  = 48000;

enum
{
    VOLUME_CTRL_0_DB    = 0,
    VOLUME_CTRL_10_DB   = 2560,
    VOLUME_CTRL_20_DB   = 5120,
    VOLUME_CTRL_30_DB   = 7680,
    VOLUME_CTRL_40_DB   = 10240,
    VOLUME_CTRL_50_DB   = 12800,
    VOLUME_CTRL_60_DB   = 15360,
    VOLUME_CTRL_70_DB   = 17920,
    VOLUME_CTRL_80_DB   = 20480,
    VOLUME_CTRL_90_DB   = 23040,
    VOLUME_CTRL_100_DB  = 25600,
    VOLUME_CTRL_SILENCE = 0x8000,
};

// Audio controls
// Current states
int8_t mute[CFG_TUD_AUDIO_FUNC_1_N_CHANNELS_RX + 1];     // +1 for master channel 0
int16_t volume[CFG_TUD_AUDIO_FUNC_1_N_CHANNELS_RX + 1];  // +1 for master channel 0

// Resolution per format
const uint8_t resolutions_per_format[1] = {CFG_TUD_AUDIO_FUNC_1_RESOLUTION_RX};
// Current resolution, update on format change
uint8_t current_resolution = 24;

#define N_SAMPLE_RATES TU_ARRAY_SIZE(sample_rates)

uint8_t xfade_buffer_index      = 0;
uint8_t buffer_index            = 0;
uint16_t xfade_buffer[16]       = {0};
uint16_t xfade                  = 0;
uint16_t xfade_prev             = 255;
uint16_t master_gain_buffer[16] = {0};
uint16_t master_gain            = 0;
uint16_t master_gain_prev       = 255;

uint_fast64_t sai_buf_index            = 0;
uint_fast64_t sai_transmit_index       = 0;
int_fast32_t sai_buf[SAI_RNG_BUF_SIZE] = {0};

// Speaker data size received in the last frame
uint_fast16_t spk_data_size = 0;

// Buffer for speaker data
int_fast32_t spk_buf[CFG_TUD_AUDIO_FUNC_1_EP_OUT_SW_BUF_SZ] = {0};
int_fast32_t hpout_buf[SAI_BUF_SIZE]                        = {0};

volatile int16_t update_pointer    = -1;
volatile int16_t hpout_clear_count = 0;

// Helper for clock get requests
static bool tud_audio_clock_get_request(uint8_t rhport, audio_control_request_t const* request)
{
    TU_ASSERT(request->bEntityID == UAC2_ENTITY_CLOCK);

    if (request->bControlSelector == AUDIO_CS_CTRL_SAM_FREQ)
    {
        if (request->bRequest == AUDIO_CS_REQ_CUR)
        {
            SEGGER_RTT_printf(0, "Clock get current freq %lu\r\n", current_sample_rate);

            audio_control_cur_4_t curf = {(int32_t) tu_htole32(current_sample_rate)};
            return tud_audio_buffer_and_schedule_control_xfer(rhport, (tusb_control_request_t const*) request, &curf, sizeof(curf));
        }
        else if (request->bRequest == AUDIO_CS_REQ_RANGE)
        {
            audio_control_range_4_n_t(N_SAMPLE_RATES) rangef =
                {
                    .wNumSubRanges = tu_htole16(N_SAMPLE_RATES)};
            SEGGER_RTT_printf(0, "Clock get %d freq ranges\r\n", N_SAMPLE_RATES);
            for (uint8_t i = 0; i < N_SAMPLE_RATES; i++)
            {
                rangef.subrange[i].bMin = (int32_t) sample_rates[i];
                rangef.subrange[i].bMax = (int32_t) sample_rates[i];
                rangef.subrange[i].bRes = 0;
                SEGGER_RTT_printf(0, "Range %d (%d, %d, %d)\r\n", i, (int) rangef.subrange[i].bMin, (int) rangef.subrange[i].bMax, (int) rangef.subrange[i].bRes);
            }

            return tud_audio_buffer_and_schedule_control_xfer(rhport, (tusb_control_request_t const*) request, &rangef, sizeof(rangef));
        }
    }
    else if (request->bControlSelector == AUDIO_CS_CTRL_CLK_VALID && request->bRequest == AUDIO_CS_REQ_CUR)
    {
        audio_control_cur_1_t cur_valid = {.bCur = 1};
        SEGGER_RTT_printf(0, "Clock get is valid %u\r\n", cur_valid.bCur);
        return tud_audio_buffer_and_schedule_control_xfer(rhport, (tusb_control_request_t const*) request, &cur_valid, sizeof(cur_valid));
    }
    SEGGER_RTT_printf(0, "Clock get request not supported, entity = %u, selector = %u, request = %u\r\n", request->bEntityID, request->bControlSelector, request->bRequest);
    return false;
}

// Helper for clock set requests
static bool tud_audio_clock_set_request(uint8_t rhport, audio_control_request_t const* request, uint8_t const* buf)
{
    (void) rhport;

    TU_ASSERT(request->bEntityID == UAC2_ENTITY_CLOCK);
    TU_VERIFY(request->bRequest == AUDIO_CS_REQ_CUR);

    if (request->bControlSelector == AUDIO_CS_CTRL_SAM_FREQ)
    {
        TU_VERIFY(request->wLength == sizeof(audio_control_cur_4_t));

        current_sample_rate = (uint32_t) ((audio_control_cur_4_t const*) buf)->bCur;

        SEGGER_RTT_printf(0, "Clock set current freq: %ld\r\n", current_sample_rate);

        return true;
    }
    else
    {
        SEGGER_RTT_printf(0, "Clock set request not supported, entity = %u, selector = %u, request = %u\r\n", request->bEntityID, request->bControlSelector, request->bRequest);
        return false;
    }
}
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

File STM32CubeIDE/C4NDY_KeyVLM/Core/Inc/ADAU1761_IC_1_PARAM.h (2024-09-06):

/*
 * File:           C:\Users\shun\C4NDY\SigmaDSP\ADAU1761_IC_1_PARAM.h
 *
 * Created:        Wednesday, September 4, 2024 8:57:34 PM
 * Description:    ADAU1761:IC 1 parameter RAM definitions.
 *
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
 * This software may only be used to program products purchased from
 * Analog Devices for incorporation by you into audio products that
 * are intended for resale to audio product end users. This software
 * may not be distributed whole or in any part to third parties.
 *
 * Copyright ©2024 Analog Devices, Inc. All rights reserved.
 */
#ifndef __ADAU1761_IC_1_PARAM_H__
#define __ADAU1761_IC_1_PARAM_H__


/* Module Modulo Size - Modulo Size*/
#define MOD_MODULOSIZE_COUNT                           1
#define MOD_MODULOSIZE_DEVICE                          "IC1"
#define MOD_MODULOSIZE_MODULO_SIZE_ADDR                0
#define MOD_MODULOSIZE_MODULO_SIZE_FIXPT               0x00001000
#define MOD_MODULOSIZE_MODULO_SIZE_VALUE               SIGMASTUDIOTYPE_INTEGER_CONVERT(4096)
#define MOD_MODULOSIZE_MODULO_SIZE_TYPE                SIGMASTUDIOTYPE_INTEGER

/* Module DC1 - DC Input Entry*/
#define MOD_DC1_COUNT                                  1
#define MOD_DC1_DEVICE                                 "IC1"
#define MOD_DC1_DCINPALG1_ADDR                         8
#define MOD_DC1_DCINPALG1_FIXPT                        0x00400000
#define MOD_DC1_DCINPALG1_VALUE                        SIGMASTUDIOTYPE_FIXPOINT_CONVERT(0.5)
#define MOD_DC1_DCINPALG1_TYPE                         SIGMASTUDIOTYPE_FIXPOINT

/* Module DC2 - DC Input Entry*/
#define MOD_DC2_COUNT                                  1
#define MOD_DC2_DEVICE                                 "IC1"
#define MOD_DC2_DCINPALG2_ADDR                         9
#define MOD_DC2_DCINPALG2_FIXPT                        0x00400000
#define MOD_DC2_DCINPALG2_VALUE                        SIGMASTUDIOTYPE_FIXPOINT_CONVERT(0.5)
#define MOD_DC2_DCINPALG2_TYPE                         SIGMASTUDIOTYPE_FIXPOINT

/* Module Single 1 - Single Volume Shared*/
#define MOD_SINGLE1_COUNT                              2
#define MOD_SINGLE1_DEVICE                             "IC1"
#define MOD_SINGLE1_ALG0_APPROXFACTORGAINS200ALGGROWDBSTEP1_ADDR 10
#define MOD_SINGLE1_ALG0_APPROXFACTORGAINS200ALGGROWDBSTEP1_FIXPT 0x00001000
#define MOD_SINGLE1_ALG0_APPROXFACTORGAINS200ALGGROWDBSTEP1_VALUE SIGMASTUDIOTYPE_FIXPOINT_CONVERT(0.00048828125)
#define MOD_SINGLE1_ALG0_APPROXFACTORGAINS200ALGGROWDBSTEP1_TYPE SIGMASTUDIOTYPE_FIXPOINT
#define MOD_SINGLE1_ALG0_TARGETGAINS200ALGGROWDBSTEP1_ADDR 11
#define MOD_SINGLE1_ALG0_TARGETGAINS200ALGGROWDBSTEP1_FIXPT 0x00800000
#define MOD_SINGLE1_ALG0_TARGETGAINS200ALGGROWDBSTEP1_VALUE SIGMASTUDIOTYPE_FIXPOINT_CONVERT(1)
#define MOD_SINGLE1_ALG0_TARGETGAINS200ALGGROWDBSTEP1_TYPE SIGMASTUDIOTYPE_FIXPOINT

/* Module ln ph sw - Stereo Switch 2xN*/
#define MOD_LNPHSW_COUNT                               2
#define MOD_LNPHSW_DEVICE                              "IC1"
#define MOD_LNPHSW_ALG0_STEREODEMUXSLEW10_ADDR         12
#define MOD_LNPHSW_ALG0_STEREODEMUXSLEW10_FIXPT        0x00000000
#define MOD_LNPHSW_ALG0_STEREODEMUXSLEW10_VALUE        SIGMASTUDIOTYPE_FIXPOINT_CONVERT(0)
#define MOD_LNPHSW_ALG0_STEREODEMUXSLEW10_TYPE         SIGMASTUDIOTYPE_FIXPOINT
#define MOD_LNPHSW_ALG0_STEREODEMUXSLEW11_ADDR         13
#define MOD_LNPHSW_ALG0_STEREODEMUXSLEW11_FIXPT        0x00800000
#define MOD_LNPHSW_ALG0_STEREODEMUXSLEW11_VALUE        SIGMASTUDIOTYPE_FIXPOINT_CONVERT(1)
#define MOD_LNPHSW_ALG0_STEREODEMUXSLEW11_TYPE         SIGMASTUDIOTYPE_FIXPOINT
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

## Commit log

2023-06-13 Add Kicad Project files.
    [C4NDY.kicad_pcb, C4NDY.kicad_sch]
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2023-06-14 Fix some mistakes.
    1．A1_XXをA12_XXに修正
    2．ビアに被っていたシルクの位置を調整
    3．USB Type-CのCC用5.1kをまとめない
    4．スイッチのフットプリントを修正
    [C4NDY.kicad_pcb, C4NDY.kicad_sch]
2023-06-26 Fixed some comment.
    [C4NDY.kicad_pcb]
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2023-06-26 Move kicad project files to "KiCad" folder.
    [C4NDY.kicad_pcb, C4NDY.kicad_sch]
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2023-07-01 Modify some codes(configuration descriptor, etc) for composite device.
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2023-07-04 Change USBD_MAX_POWER(100mA -> 500mA).
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2023-07-04 typoを修正
2023-07-04 wTotalLengthの値を修正
    コメント修正
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2023-07-04 typo修正
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2023-07-04 ｗTotalLengthを修正
2023-07-04 サンプルレートの設定ミスとデスクリプタサイズを修正
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2023-07-05 Feature Unit Descriptorを修正
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2023-07-05 インデント修正
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2023-07-05 マージミスを修正
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2023-07-13 VrefをVCCに接続し、マイコン周辺の部品配置と配線を修正
    [C4NDY.kicad_pcb, C4NDY.kicad_sch]
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2023-07-18 USB high priority interrupt remapを有効化
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2023-07-21 String Descriptor周りを修正
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2023-07-25 文字化けを修正
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2023-07-25 SAIのFirstBitOffsetの値を修正
2023-07-25 C4NDYメインボードのKiCadデータを移動
    [C4NDY.kicad_pcb, C4NDY.kicad_sch]
2023-07-25 キーボードのKiCadデータを追加
    [ICs.kicad_sch, KVL.dsn, KVL.kicad_pcb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]
2023-07-26 SigmaDSPのプロジェクトを追加し、エクスポートしたヘッダーを更新
    [ADAU1761.params]
2023-07-26 USB High Priority Interruptを有効化
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2023-08-03 ADAU176のマスターゲインを調整出来るようにした
    detectSwitchess()のステートマシンをさらに細分化
    SAIをDMA化
    一時的にタイマー処理をコメントアウト
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2023-08-16 フォルダ名とプロジェクト名変更に伴うsubmoduleのエラーを修正
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2023-08-17 基板の寸法情報を追加
    [KVL.kicad_pcb]
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2023-11-30 古いプロジェクト名が残っていたので現在の名称に修正
2023-11-30 SWD用のコネクタを汎用のピンヘッダに変更し、viaをテントに修正。
    [C4NDY.kicad_pcb, C4NDY.kicad_sch]
2023-11-30 キースイッチをソケット化
    [ICs.kicad_sch, KVL.kicad_pcb, KVL.kicad_sch]
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2023-12-01 USBからの入力音を調整するVolumeを追加
    [ADAU1761.params]
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2023-12-14 ADAU1761の入力段のゲインを-16dBから-4dBに上げる。
    [ADAU1761.params]
2023-12-14 音割れ修正
2023-12-14 リングバッファ用のインデックスの型を修正
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2023-12-18 DFUモードへの遷移をLGUI+ESCキー10秒長押しに変更
    DFUモード遷移時にキーマップが0クリアされないように修正
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2023-12-28 Add step files.
    [KVL_D_socket.step, KeyVLM_TopPlate.step, case_D_socket.stp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]
2023-12-28 Add top(switch) plate kicad files.
    [KeyVLM_TopPlate.kicad_pcb, KeyVLM_TopPlate.kicad_sch]
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2023-12-28 Renew C4NDY mainboard 3D modedl.
    [KVL.dsn, KVL.kicad_pcb]
2024-01-19 Fix to switch the bootloader mode.
    [keyboard.c]
2024-01-22 The current keymap of the specified layout can now be obtained.
2024-03-29 Added Line/Phono Switching LED.
    [ICs.kicad_sch, KVL.kicad_pcb]
2024-03-29 Modify USB Type-C Connector Position.
    [C4NDY.kicad_pcb, C4NDY.kicad_sch]
2024-03-29 Adjust screw hole size.
    [KeyVLM_TopPlate.kicad_pcb]
2024-03-29 Turns the LED on and off when the Line/Phono key is pressed.
2024-05-29 Fixed to set POT value correctly at startup.
    [audio_control.c]
2024-05-29 Phono(LED ON), Line(LED OFF)
2024-05-29 Add pcb step file.
    [pcb.step]
2024-06-01 Changed to save the state to flash memory when switching between Line/Phono.
2024-06-01 Corrected LED for Line/Phono to light correctly when device is activated.
    [main.c]
2024-06-02 Fixed initialization process for USER_LED.
    [main.c]
2024-07-14 Add C4NDY_STK kicad project.
    [ICs.kicad_sch, KVL_STK.kicad_pcb, KVL_STK.kicad_sch]
2024-07-14 Add kicad project of C4NDY_STK top-plate.
    [STK_TopPlate.kicad_pcb, STK_TopPlate.kicad_sch]
2024-07-15 Add plasticity file of keyboard enclosure and side panel.
2024-07-15 Renew kicad files.
    [ICs.kicad_sch, KVL.kicad_sch, KeyVLM_TopPlate.kicad_sch]
2024-07-19 Add plasticity file of STK's left side panel .
    remove step files.
    [C4NDY_revD.step, KeyVLM_TopPlate.step, pcb.step]
2024-07-30 Fixed a key input bug when using the analog stick.
    Suppresses false keystrokes that occur immediately after key input while the analog stick is depressed.
    [keyboard.c]
2024-08-02 Fixed a bug and refactored.
    [keyboard.c]
2024-08-07 Assign PA15 to PWM output pin (DMA).
2024-08-21 Fixed Data Delay LRCLOCK Edge value from 1 to 8 in SigmaStudio project.
    [ADAU1761_IC_1.h, ADAU1761_IC_1_PARAM.h, ADAU1761_IC_1_REG.h]
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2024-08-21 Added 30 RGB LEDs.
    [ICs.kicad_sch, KVL_STK.kicad_pcb, KVL_STK.kicad_sch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]
2024-08-21 Added led brightness adjustment and anti-flicker function.
2024-08-21 LED color changes in response to key operations.
    The color of the LED changes depending on whether or not the Upper key is pressed.
2024-08-22 Fixed a bug with noise when Master Gain was adjusted by key input.
    [ADAU1761.params]
2024-08-22 Added RESET key for swtching to DFU bootloader mode.
    [keyboard.c, keyboard.h]
2024-08-22 Fixed DFU bootloader to work correctly with C4NDY STK.
    [main.c]
2024-08-22 Adjustment of screw hole position.
    [KVL_STK.kicad_pcb]
2024-08-23 Added functions for LED control.
2024-08-26 Fixed DMA's priority.
2024-08-26 Added four LEDs.
    [KVL_STK.kicad_pcb, LEDs.kicad_sch]
2024-08-27 Changes the color of the LED when the SHIFT key is pressed.
2024-08-27 Fixed a bug that LED did not light up at startup.
    [main.c]
2024-08-27 Change LED color when SHIFT key is pressed.
2024-08-28 Change input gain of ch.2 & 3(signal from STM32 SAI) from -4dB to 0dB.
    [ADAU1761.params]
2024-08-28 Change master gain's value and step.
    [ADAU1761.params]
2024-09-02 Changed RGB LED nums.
2024-09-02 Modified USB max current from 100mA to 500mA.
2024-09-03 Implemented LED lighting process when Upper and Shift keys are pressed.
2024-09-03 Added STK's schematic & board pdf.
    [KVL_STK.kicad_pcb, KVL_STK.kicad_sch]
2024-09-03 Added KeyVLM's schematic & board pdf.
    [KVL.kicad_pcb, KVL.kicad_sch]
2024-09-03 Added Mainboard's schematic & board pdf.
2024-09-03 Implemented LED animation when Space or BS key is pressed.
2024-09-03 Implemented LED animation when Enter is pressed.
2024-09-03 Changed LED animation when Shift or Upper key is pressed.
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2024-09-04 Added noise gate.
    [ADAU1761.params]
2024-09-05 Fixed noise on sound input from USB host during LED animation.
    [icled.c]
2024-09-05 Fixes to prevent device freezing.
    [C4NDY_STK.ioc, icled.c, icled.h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]
2024-09-06 Fixed to prevent device freezing.
    [icled.c]
2024-09-06 Fixed PID.
2024-09-10 Fixed SAI process not to be interrupted when executing PWM process.
    [icled.c]
2024-09-10 Implemented some functions to save LED color settings in FLASH.
2024-09-11 Fixed erase page setting.
    [main.c]
2024-09-11 Changed to allow separate LED color settings for layout1 and layout2.
2024-09-12 Implemented the function to click left and right buttons.
2024-09-13 Fixed a bug that left the last pattern of LED animation.
    [icled.c]
2024-09-13 Fixed a bug of LED.
    Fixed a bug that the LED color did not change when the Upper key was pressed.
    [keyboard.c]
2024-09-17 Fixed typing error when releasing the Upper key.
    [keyboard.c]
2024-09-17 Adjust speed of LED animation.
2024-09-18 Support mouse wheel function(vertical only).
2024-09-19 Fixed the RESET key function. #57
    Allow the keyboard to be restarted by tapping the RESET key once (the long press function is retained).
    [keyboard.c]
2024-09-19 Fixed a bug #58.
    Fixed a bug that prevented jumping to the application code from the boot loader of release builds.
    [main.c]
2024-09-19 Fixed to be able to delete data area correctly.
    [main.c]
2024-09-19 Corrected the order of data stored in the FLASH data area.
    Place the boot flag at the beginning of the data area.
    [keyboard.c, keyboard.h, main.c]
2024-09-23 Corrected constant names defined in define.
    [keyboard.c, keyboard.h]
2024-09-27 Adjust the position of LEDs on the PCB.
    [KVL_STK.kicad_pcb]
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2024-09-30 Implemented the function to check LED color from the Confiseur.
2024-09-30 Fixed a bug that modifier keys are entered during mouse operation.
    [keyboard.c]
2024-09-30 Fixed a bug that caused unintended wheel operation.
    [keyboard.c]
2024-10-01 Adjust wheel operation sensitivity. #55
2024-10-02 Fixed a bug where the joystick's upper right input was not cleared.
    [keyboard.c]
2024-10-03 Fixed a bug with key input leaking immediately after joystick operation.
    [keyboard.c]
2024-10-04 Fixed a bug that key input is lost after space input with joystick.
    [keyboard.c]
2024-10-15 Fixed a bug in factoryReset().
    Modifier keys were not initialized correctly.
    [keyboard.c]
2024-10-16 Fixed sai_buf array size.
    [audio_control.c]
2024-10-16 Modified potentiometer hole position.
2024-10-16 Modified to clear buffers for audio as appropriate.
    Fixed a bug that sound remaining in the buffer was played in a loop when the host terminated an application that was playing audio.
    [audio_control.c]
2024-10-18 Fixed a ring buffer bug.
    [audio_control.c, tusb_config.h]
2024-10-20 Fixed a bug that caused unintended key input.
    Corrected key input process not to be executed during joystick calibration, which is performed immediately after connecting to the host device.
    [keyboard.c]
2024-10-21 Changed LED intensity from constant to variable.
    LED intensity can be adjusted from Confiseur.
2024-10-21 Allow storing LED intensity values in FLASH.
2024-10-21 Revert "Allow storing LED intensity values in FLASH."
    This reverts commit b492ffadb30c2145b92f6da8f81da1627a88dbe6.
    [keyboard.c, main.c]
2024-10-21 Revert "Support for Confiseur v0.12.0."
    This reverts commit dded4184bae4c79584a9f8eb12deec27e9a1faa2.
    [keyboard.c]
2024-10-21 Fixed to read LED intensity values from FLASH at startup.
    [icled.c]
2024-10-21 Fixed a bug in factoryreset.
    Fixed a bug that LED settings were not initialized correctly when factoryreset was executed.
    [keyboard.c]
2024-10-24 Modified buffer size and sample size of read from usb.
2024-10-26 Improved data update process for buffers passed to SAI DMA.
2024-10-28 Added xfader cut keys.
2024-10-28 Fixed a bug of volume control by pressing XFADE_CUT.
    Fixed a bug that the volume could not be restored after pressing the XFADE_CUT key.
    [audio_control.c]
2024-10-28 Fixed a bug. #101
    Fixed a bug that SAI buffer was not cleared when sound was forced to stop during audio playback via USB.
    [audio_control.c]
2024-10-28 Fixed a bug of LED.
    Fixed a bug in the Upper layout that the LEDs of keys to which modifier keys are assigned were turned off.
    [keyboard.c]
2024-10-30 Fixed a bug #107 .
    Fixed a bug that the key being pressed is input when the stick is undone while a key is being pressed.
    [keyboard.c]
2024-10-31 Make the flag variable volatile.
    Fixed flag variables so that they are not affected by compiler optimizations.
    [audio_control.c]
2024-10-31 Fixed a key input bug.
    If you tilt the stick to the Upper On state, press any key, and then release the key and return the stick at approximately the same timing, the process of releasing the key will be lost.
    [keyboard.c]
2024-11-01 Changed LED lighting pattern for joystick operation.
2024-11-01 Fixed a bug in mouse mode.
    Fixed a bug that the mouse mode is canceled by diagonal input during mouse operation with the right stick.
    [keyboard.c]
2024-11-01 Added LED lighting patterns in mouse mode.
2024-11-01 Fixed a bug in LED control in mouse mode.
    [icled.c, icled.h]
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2024-11-02 Fixed a bug when switching LED mode.
    The LED pattern does not light up correctly when the stick is operated immediately after the Mix knob operation.
    [icled.c]
2024-11-05 Fixed a bug with diagonal input of the right stick.
    Fixed a bug in which the modifier keys could not be input correctly when the right stick was operated diagonally.
    [keyboard.c, keyboard.h]
2024-11-06 Assigned STM32 96-bit unique ID to USB Serial.
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2025-05-29 Added TPS2116 and removed onboard QSPI..
    [C4NDY.kicad_pcb, C4NDY.kicad_sch]
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2025-05-29 Renewed some footprint.
    [C4NDY.kicad_pcb]

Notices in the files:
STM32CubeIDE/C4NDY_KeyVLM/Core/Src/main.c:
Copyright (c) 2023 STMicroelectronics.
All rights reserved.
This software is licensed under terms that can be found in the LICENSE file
